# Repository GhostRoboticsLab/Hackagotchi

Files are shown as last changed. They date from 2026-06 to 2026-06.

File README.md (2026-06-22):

# Hackagotchi 🛠️🐾

<div align="center">

**The debug probe with a soul — and tools up its sleeves.**






<!-- HERO RENDER: export the Blender hero to docs/media/hero.png (recommend ~1280px wide, transparent or dark bg) and uncomment the <img> below; then drop the social card that follows it.
<img src="docs/media/hero.png" width="640" alt="Hackagotchi — XIAO RP2040: CMSIS-DAP debug probe + UART black-box recorder + reactive OLED companion" />
-->

<!-- Until the Blender hero lands, the social card doubles as the top banner. -->
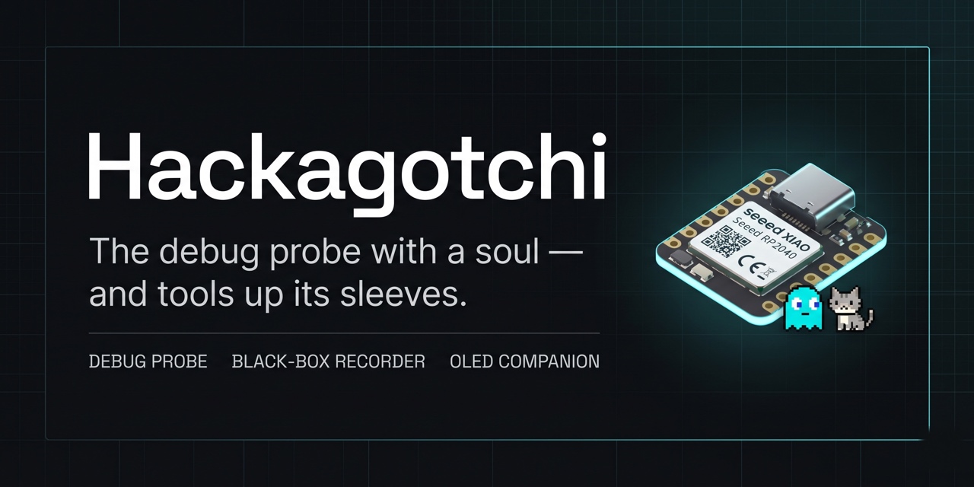
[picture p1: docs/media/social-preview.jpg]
Hackagotchi — a CMSIS-DAP debug probe, UART black-box recorder, and reactive OLED companion on one Seeed XIAO RP2040


</div>

A fork of Raspberry Pi's official [`debugprobe`](https://github.com/raspberrypi/debugprobe) firmware — drop-in with OpenOCD, probe-rs, and the Pico SDK — that doesn't just flash your target, it *watches* it. One **Seeed XIAO RP2040**, one firmware image, **three simultaneous roles**:

- 🔌 **A real SWD debug probe** — halt, erase, and reflash a wedged target with OpenOCD / probe-rs, *whatever state its firmware is in*. Standards-compliant CMSIS-DAP; enumerates as **"Hackagotchi Probe (CMSIS-DAP)"**.
- 📼 **A UART black-box recorder** — continuously logs the target's serial to microSD (session headers, heartbeats, a freeze-frame on a wedge), so a board that goes dark still leaves its **last words**.
- 🐾 **A reactive OLED that's alive, not a dongle** — a cat and a ghost whose every flicker is a *literal readout of your target*. The cat is the bench at a glance; **Spectre, the ghost, IS the target board's soul** — it wakes when the board talks, goes hollow when it wedges, dissolves when you reflash. The probe and recorder feed a face that shows the board's pulse. (This layer is evolving fast.)

> 🎯 All three on **one single-core RP2040**, with **0 DAP transfer stalls under load** — the dashboard and SD writer never steal a cycle from a flash in progress. That invariant (**R1**) is *proven on hardware, not asserted*: see [`docs/release-readiness.md`](docs/release-readiness.md).

## ⚡ Flash it in 30 seconds

No toolchain needed — just `picotool` (`brew install picotool`). Grab `hackagotchi_probe.uf2` from the **[latest release](https://github.com/GhostRoboticsLab/Hackagotchi/releases)**, drop into BOOTSEL, and load:

```bash
# BOOTSEL the XIAO: hold B, tap R, release B  ->  an RPI-RP2 drive mounts
picotool load -x hackagotchi_probe.uf2          # -x = run after loading

# alive check: send this to the control serial port (the one that answers as "Hackagotchi")
printf '{"q":"status"}\n' > /dev/cu.usbmodemXXXX  # -> {"fw":"Hackagotchi","ver":"1.0.0",...}
```

That's it — the cat wakes up and the probe is live.

<sub>Already running an older build? You don't even need the chord — send `{"q":"bootsel"}` to the control port and it drops to BOOTSEL on its own. Building from source instead? → [`docs/c-firmware-build.md`](docs/c-firmware-build.md).</sub>

<sub>**Two firmwares live here.** The shipping product is the **C firmware** in [`firmware/c/`](firmware/c) (everything below). [`firmware/micropython/`](firmware/micropython) is the original MicroPython v1 prototype, kept for reference.</sub>

---

<details>
<summary><b>🔧 Wiring &amp; pin map</b> — it's a XIAO on a Seeed expansion board; you only wire SWD + GND to your target</summary>

| Function | Pins |
|---|---|
| **SWD → target** (the probe) | SWCLK **GP26**, SWDIO **GP27**, + GND |
| **Target UART tap** → CDC0 bridge | TX **GP0**, RX **GP1** (uart0) |
| **microSD** — SPI0 (black box) | SCK **GP2**, MOSI **GP3**, MISO **GP4**, CS **GP28** |
| **OLED** — I2C1 @ 1 MHz (addr 0x3C) | SDA **GP6**, SCL **GP7** |
| **Buzzer** (PWM) | **GP29** |
| **WS2812 NeoPixel** (status LED) | data **GP12**, power **GP11** |

**No physical button** — GP27 became SWDIO, so navigation and tools are driven over USB (CDC1, below). A deliberate trade: when the device *is* a debugger, an extra debug pin beats a menu button.

</details>

<details>
<summary><b>🎛️ Using it</b> — two USB serial ports: a transparent UART bridge + a JSON control channel</summary>

| Port | Role |
|---|---|
| **CDC0** | Transparent **UART bridge** — your target's serial console, passed straight through (115200 default; runtime-changeable). |
| **CDC1** | **JSON control channel** — newline-delimited `{"q":"..."}` requests, JSON replies. |

The numeric `/dev/cu.usbmodemXXXX` suffix is **not stable** across replug — identify the control port by *behavior*: it's the one that answers `{"q":"status"}` with `"fw":"Hackagotchi"`. The other is the bridge.

**Debugging a target (SWD)** — it's a standard CMSIS-DAP probe, so point your usual tools at it:

```bash
probe-rs list                                   # -> "Hackagotchi Probe (CMSIS-DAP)"
probe-rs download --verify firmware.elf --chip RP2040
openocd -f interface/cmsis-dap.cfg -f target/rp2040.cfg
```

</details>

<details>
<summary><b>📡 Control channel (CDC1) — full command reference</b></summary>

Send `{"q":"<cmd>", ...}\n`; you get one JSON line back.

| Group | Command | Does |
|---|---|---|
| **Status** | `{"q":"status"}` | live telemetry: `fw, ver, heap, up, n, crashes, wd_armed, page, urx_drop, frag, …` |
| | `{"q":"dump"}` | status + last crash report |
| | `{"q":"lastfault"}` | the post-mortem crash box (HardFault / malloc-fail, survives reboot) |
| **Recorder / SD** | `{"q":"rec"}` / `{"q":"tail"}` | recorder state / the on-card log tail |
| | `{"q":"ls"}` / `{"q":"cat","i":N,"off":M}` | list logs / read log #N (by index — no path traversal) |
| | `{"q":"sd"}` | SD mount + bring-up status |
| **Dashboard** | `{"q":"next"}` / `{"q":"prev"}` / `{"q":"screen","n":N}` | navigate screens |
| | `{"q":"hex"}` | toggle the SNIFFER between ASCII and hex |
| **Tools** | `{"q":"macros"}` / `{"q":"macro","i":N}` | list / send a predefined string out the target UART |
| | `{"q":"setmacro","i":N,"s":"..."}` | set macro N (persisted to SD) |
| | `{"q":"baud","v":N}` | change the target-UART baud (validated set; persisted) |
| **Feedback** | `{"q":"beep"}` / `{"q":"led",...}` / `{"q":"pixel",...}` | buzzer / status LEDs / NeoPixel (pixel 0) |
| | `{"q":"fb"}` | feedback-layer readback — beep count + live NeoPixel colour (diagnostic) |
| **Companion (v1.2)** | `{"q":"fill","r":..,"g":..,"b":..}` | set the whole WS2812 chain to one colour |
| | `{"q":"mood","n":0..6,"i":0..255}` | animated mood: off / idle / rx / warn / fault / pet / rainbow |
| | `{"q":"btn"}` / `{"q":"joy"}` | button + joystick readback (held / taps; present / X / Y / dir) |
| **Companion** | `{"q":"pet"}` | a happy cat beat (heart + chirp) |
| | `{"q":"summon"}` / `{"q":"banish"}` | force the ghost present / absent (also lets tests drive it) |
| | `{"q":"exorcise"}` | the exorcism dissolve — a host flasher fires it after a clean reflash |
| | `{"q":"ghost","on":0/1}` / `{"q":"theme","n":0/1}` | mute the character layer (pure-instrument) / motion density |
| | `{"q":"ghost"}` (no `on`) | clear a `summon`/`banish` override — return the ghost to AUTO |
| **Maintenance** | `{"q":"bootsel"}` | reset to BOOTSEL for a hands-free reflash |
| | `{"q":"wd_arm"}` / `{"q":"wd_reset"}` | software watchdog control |

There are also test/diagnostic hooks used by the HIL suite (`uloop_on/off`, `recgen_on/off`, `crash`, `oom_test`, `wd_test`) — see [`firmware/c/src/cdc1_control.c`](firmware/c/src/cdc1_control.c).

</details>

<details open>
<summary><b>🐾 The dashboard</b> — a cat + a ghost, 6 auto-cycling monitor screens, 3 summonable tool screens</summary>

```
HOME         SNIFFER        RECORDER     THROUGHPUT    WATCHDOG       UPTIME
 /\_/\  .-.  UART RX LOG    BLACK BOX     ▁▂▄▆█▆▄▂      last freeze    + heap
( o.o )(o o) live tail      log NNN       bytes/s       frame          rev/flt
```

**Every flicker of personality is a literal readout of a real signal** — two characters, no whimsy that isn't load-bearing:

- **The cat** is your bench familiar, its mood the bench at a glance: **sleeping** (idle), **content** (target chatting), **hunting** (data really flowing — particles + tail speed scale with throughput), **alert** (target wedged or SD fault). Pet it with `{"q":"pet"}`.
- **Spectre, the ghost**, *is the target board's soul*. It **dozes** when the target is quiet and **wakes solid** when it talks over the UART tap (GP0/GP1), goes **hollow/pale** when it wedges, **torn** on a recorder fault, and is **exorcised** (dissolves) when the host reflashes. A status pip rides the top-right corner of every screen. (Ghost liveness follows the target's *serial* — an SWD-only attach with no UART traffic shows the dozing ghost.)

The six **monitor** screens auto-cycle; three **tool** screens (MACRO / BAUD / SD-EXPLORER) are summoned over CDC1 and stay put (excluded from auto-cycle). The buzzer + NeoPixel add event feedback (summon chirp, wedge alarm + red, recovery gasp + green) — all driven off the DAP hot path. Want a pure instrument cluster? `{"q":"ghost","on":0}`.

This character layer is under heavy active development and expanding fast — the cat and Spectre are just the first faces of the bench.

</details>

<details>
<summary><b>🧠 How it works — the R1 invariant</b> (single-core coexistence bought with priority, not a 2nd core)</summary>

The RP2040 in `debugprobe-v2.2.3` is **single-core** (no SMP), so coexistence is bought with **task priority**:

```
priority  high ─────────────────────────────────────────────► low
          UART bridge / watchdog  >  USB (TUD)  >  DAP  >  dashboard + SD writer
```

The DAP path is never blocked by anything below it, and nothing above it takes a DAP-needed lock. Cross-task data moves through **single-writer published snapshots** (a seqlock) and **lock-free SPSC rings** — never shared mutable structs. Each resource has exactly one owning task (FatFs ↔ SD task, OLED/I2C1 ↔ dashboard task, uart0 TX ↔ bridge task). The firmware runs from **flash XIP** (not `copy_to_ram`), buying +139 KB of SRAM at identical DAP throughput.

The measured payoff: **0 DAP transfer stalls** in every soak — while the SD writer hammers the card and the dashboard renders. Rationale: [`docs/engineering-plan.md`](docs/engineering-plan.md) · evidence: [`docs/release-readiness.md`](docs/release-readiness.md).

</details>

<details>
<summary><b>📁 Repository layout</b></summary>

```
firmware/c/          the shipping C firmware (this README)
  src/               our overlay: probe + bridge + control + recorder + dashboard + reliability
  boards/            the locked XIAO pin map (board config shim over upstream)
  tests/             gates/ (Gate 0/1/2) + m1..m4 (HIL + host unit tests)
  build_fork.sh setup.sh analyze.sh   build / fetch-upstream / static-analysis gate
firmware/micropython/  legacy v1 prototype (MicroPython)
docs/                engineering-plan · release-readiness · c-firmware-build · recovery-model · firmware-conventions
.github/workflows/   firmware-c.yml — manual-dispatch build + static-analysis gate + Release
case/                3D-printable enclosure
```

</details>

<details>
<summary><b>🛡️ Reliability &amp; evidence</b> — this project is gates-first</summary>

The risky architectural claims — *does the dashboard starve the probe? does the SD writer corrupt a flash? does the 2nd CDC keep DAP enumerating?* — were proven on real hardware as falsifiable **gates** *before* any feature work. See [`docs/release-readiness.md`](docs/release-readiness.md) for the full CI-automated-vs-HIL-attested evidence table, and `firmware/c/tests/gates/GATE_RESULTS.md`.

> ⚠️ A green CI badge means "builds + passes static analysis," **not** "the gates ran" — the HIL gates need the physical bench and are attested by hand on each release image.

</details>

<details>
<summary><b>📜 License &amp; open-core model</b></summary>

- **Project: GPL-3.0-or-later** ([`LICENSE`](LICENSE)) — © 2026 GhostRoboticsLab and the Hackagotchi authors. Same copyleft lineage as Pwnagotchi / Flipper Zero / Meshtastic: use, study, modify, redistribute; derivatives stay GPL.
- **`firmware/c/` subtree: MIT** ([`firmware/c/LICENSE`](firmware/c/LICENSE)) — kept MIT so fixes stay rebasable onto upstream `debugprobe`.
- Third-party components are all permissive (MIT / BSD-3 / Apache-2.0), attributed in [`THIRD-PARTY-NOTICES.md`](THIRD-PARTY-NOTICES.md) (+ [`firmware/c/THIRD-PARTY-NOTICES.md`](firmware/c/THIRD-PARTY-NOTICES.md)).

**Open-core:** the firmware is free and forkable; the project is sustained by selling assembled, pre-flashed units and the enclosure — not by closing the code.

</details>

<details>
<summary><b>🙏 Acknowledgements</b></summary>

Built on the shoulders of [`raspberrypi/debugprobe`](https://github.com/raspberrypi/debugprobe), the [Raspberry Pi Pico SDK](https://github.com/raspberrypi/pico-sdk), [TinyUSB](https://github.com/hathach/tinyusb), [FreeRTOS](https://www.freertos.org/), [carlk3's no-OS-FatFS](https://github.com/carlk3/no-OS-FatFS-SD-SDIO-SPI-RPi-Pico), ChaN's [FatFs](http://elm-chan.org/fsw/ff/), [daschr/pico-ssd1306](https://github.com/daschr/pico-ssd1306), and [zserge/jsmn](https://github.com/zserge/jsmn). 🐾

</details>

---

**Contributing?** Start with **[`CONTRIBUTING.md`](CONTRIBUTING.md)** — the fork-overlay model (don't edit upstream), the R1 concurrency rules, the gates-first discipline, and the build/test loop. 🐾

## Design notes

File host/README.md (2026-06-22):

# Host tooling

Host-side companions for a running Hackagotchi probe. Pure Python (stdlib + `pyserial`, plus
optional `Pillow`); **nothing here touches the firmware or risks the device** — these just drive
the two USB-CDC serial ports the board exposes.

| file | what it is |
|---|---|
| `hackagotchi_ctl.py` | the CLI driver for the CDC1 JSON control channel — so you don't hand-echo `{"q":"…"}` at a port |
| `tests/ctl_selftest.py` | a no-hardware self-test of the CLI's parsing/dispatch (mock serial); falsifiable green check |

## Setup

```bash
./setup-venv.sh                 # from the repo root: creates .venv + installs requirements.txt
.venv/bin/python host/hackagotchi_ctl.py status
```

`setup-venv.sh` builds one venv at the repo root and symlinks `firmware/c/.venv` to it, so the
HIL-test convention (`.venv/bin/python tests/…` run from `firmware/c/`) resolves to the same
interpreter. Manual equivalent: `python3 -m venv .venv && .venv/bin/pip install -r requirements.txt`.

## The two ports (identify by behavior, not device path)

The composite device exposes two `/dev/cu.usbmodem*` (or `/dev/ttyACM*`) ports; the numeric suffix
is **not stable across replug**. The CLI auto-detects by probing every port with `{"q":"status"}`
and matching the `"fw":"Hackagotchi"` reply — so you normally don't pass `--port` at all.

- **CDC0** — transparent target-UART bridge (the target's console; default 115200). Silent to a status probe.
- **CDC1** — newline-delimited JSON control channel (`{"q":"…"}` → one JSON line back). The one the CLI drives.

## CLI commands

```
.venv/bin/python host/hackagotchi_ctl.py <command> [args]   [--port /dev/cu.usbmodemXXXX]
```

| command | what it does |
|---|---|
| `status` | live telemetry snapshot (screen, baud, tx/rx, throughput, recorder, wedge) |
| `dump` | crash box + status in one shot |
| `lastfault` | the post-mortem crash box (HardFault / malloc-fail; survives a reboot) |
| `freeze` | the recorder's freeze-frame — the target's last words before it went silent |
| `bootsel` | reset to BOOTSEL for a hands-free reflash (the port drops; then `picotool load -x …`) |
| `baud [RATE]` | read the target-UART baud + valid options; with `RATE`, set it (validated, persisted) |
| `macro [N]` | list the configured macros; with `N`, send macro N out the target UART |
| `ls` | list the SD card's log files (shows the number to pass to `cat`) |
| `cat N [--off M] [--all]` | read SD log #N (`cat 7` → `log_007.txt`); `--all` pages to EOF |
| `sd` / `rec` / `tail` | SD mount status / recorder state / on-card log tail |
| `screen N` | jump the dashboard to screen N |
| `clear` | reset tx/rx/throughput/hits + freeze-frame |
| `watch [--seconds S]` | live-tail the relayed telemetry (Ctrl-C to stop) |
| `shot [--out f.png] [--scale K]` | screenshot the OLED over the tap → PNG (PGM fallback without Pillow) |

`ls`/`cat`/`tail` are **async by design**: the firmware services FatFs on a low-priority task off
the DAP hot path (R1), so the CLI issues each of these twice — trigger, then collect the fresh
result. The full command grammar lives in the firmware (`src/cdc1_control.c`) and the README
command table.

## Self-test (no hardware)

```bash
python3 host/tests/ctl_selftest.py                          # all checks PASS (exit 0)
HG_CTL_SELFTEST_BREAK=1 python3 host/tests/ctl_selftest.py  # verify-the-verifier: MUST FAIL (exit 1)
```

It feeds canned device replies through the CLI's parsers with a mock serial. The break mode flips
one expectation to prove the harness can actually go red — a test that cannot fail is a silent pass.

## HIL tests

The hardware-in-the-loop suites under `firmware/c/tests/**` use the same venv but need the physical
bench (a probe + a separate RP2040 target + microSD). See the project README and
`docs/release-readiness.md`.

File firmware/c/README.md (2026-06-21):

# Hackagotchi — C probe firmware

A fork of the Raspberry Pi [debugprobe](https://github.com/raspberrypi/debugprobe) that turns a
XIAO RP2040 into a **real SWD debug probe** (drive it with OpenOCD / probe-rs to halt, erase, and
reflash a wedged target regardless of its firmware state) **while also** running a UART black-box
recorder to SD, a reactive OLED dashboard, and a JSON control channel — all on the Pico SDK +
TinyUSB + FreeRTOS (**single-core**), staying R1-clean (0 DAP transfer stalls) throughout.

> This is the released product (**M1–M5 complete**; the 3 hardware gates passed). For the product
> overview and flashing a release build, see the [repo-root README](../../README.md). Full
> build/flash/analyze guide: [`../../docs/c-firmware-build.md`](../../docs/c-firmware-build.md).
> Engineering history + evidence: [`../../docs/engineering-plan.md`](../../docs/engineering-plan.md),
> [`../../docs/release-readiness.md`](../../docs/release-readiness.md), and the gate/milestone
> results under [`tests/`](tests).

## Build & flash (from source)

```bash
./setup.sh                        # fetch pinned upstream (debugprobe v2.2.3, carlk3 FatFs, pico-sdk 2.2.0)
VERSION=1.0.0 ./build_fork.sh     # -> build/hackagotchi_probe.uf2 (+ .elf); VERSION is reported by {"q":"status"}
./analyze.sh                      # GCC -fanalyzer + cppcheck static-analysis gate
```

Flash: BOOTSEL the XIAO (hold **B**, tap **R**, release **B** → `RPI-RP2` mounts), then
`picotool load -x build/hackagotchi_probe.uf2`. With the firmware already running, `{"q":"bootsel"}`
over CDC1 drops it to BOOTSEL with no button (remote reflash).

## Layout

- `src/` — our overlay: `main.c` (probe + FreeRTOS tasks), `cdc1_control.c` (JSON control),
  `cdc_uart.c` + `uart_bridge.c` (CDC0 bridge), `sd_gate.c` + `recorder.c` (SD black box),
  `hackagotchi_dashboard.c` (OLED), `crash_box.c` / `watchdog_task.c` (reliability), `feedback.c`
  (buzzer/NeoPixel), `hg_config.c` (settings), vendored `ssd1306/`, `jsmn.h`, `ws2812.pio`.
- `boards/board_hackagotchi_config.h` — the **locked** pin map (below).
- `upstream/` (gitignored) — pristine debugprobe + carlk3 FatFs, fetched by `setup.sh`.
- `tests/` — `gates/` (Gate 0/1/2 + `GATE_RESULTS.md`), `m1/`…`m4/` (HIL + host unit tests).

## Pin map (locked; verified with `picotool info`)

| Function | Pins |
|---|---|
| SWD (probe → target) | SWCLK **GP26**, SWDIO **GP27** |
| Target UART bridge (CDC0) | TX **GP0**, RX **GP1** |
| SD card — SPI0 (black box) | SCK **GP2**, MOSI **GP3**, MISO **GP4**, CS **GP28** |
| OLED — I2C1 @ 1 MHz (addr 0x3C) | SDA **GP6**, SCL **GP7** |
| Buzzer (PWM) | **GP29** |
| WS2812 NeoPixel | data **GP12**, power **GP11** |

There is **no physical button** (GP27 became SWDIO) — navigation + tools are driven over the CDC1
JSON channel. Two USB-CDC nodes enumerate: **CDC0** = UART bridge, **CDC1** = JSON control.

## Fork model

Pinned to upstream **`debugprobe-v2.2.3`** (single-core FreeRTOS — before the #189 SMP flash
regression). `setup.sh` fetches the pristine upstream into `upstream/` (gitignored); our build is an
**overlay** (we compile our `main.c` instead of upstream's and add our tasks) without modifying
upstream, so fixes stay rebasable. See [`../../docs/upstream-strategy.md`](../../docs/upstream-strategy.md).

## License

`firmware/c/` is **MIT** ([`LICENSE`](LICENSE)) to stay upstream-compatible; the rest of the repo is
GPL-3.0-or-later. Third-party components (all permissive MIT/BSD-3/Apache) are attributed in
[`THIRD-PARTY-NOTICES.md`](THIRD-PARTY-NOTICES.md).

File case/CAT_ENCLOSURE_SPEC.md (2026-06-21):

# Cat-as-object enclosure — spec & CAD-agent prompt

> Design spec, 2026-06-20. Evolves the existing "Field Recorder" pebble
> ([`HACKAGOTCHI_CASE.md`](HACKAGOTCHI_CASE.md) / `hackagotchi_case.scad`) into **Hackagotchi** — a
> desk-cat enclosure whose **face is the OLED**. The single ignition lever: a still
> photo of the powered-off object must read unmistakably as a cat.

## Design thesis

Fuse mascot + object. The on-screen `draw_cat` sprite (a 28×20 head with pointed ears, nose,
whiskers, wagging tail) should rhyme with the physical form. **#1 acceptance criterion:** one still
photo of the powered-OFF printed unit reads as a cat. The team's in-house 3D printing makes this the
highest-leverage, lowest-cost viral asset.

## Hardware to enclose

Seeed XIAO RP2040 stacked on the Seeed XIAO Expansion Board — **every dimension stays a parametric
`[MEASURE]` placeholder**, matching the current file's discipline:

- 0.96″ 128×64 SSD1306 OLED · microSD slot (edge access) · PCF8563 RTC + CR1220 coin cell ·
  passive buzzer · user button · USB-C (on the XIAO) · UART-tap leads GP0/GP1/GND exiting as a
  bundle · optional future LiPo volume.

## Cat-feature → physical mapping

| Cat feature | Physical realization |
|---|---|
| **Face** | the flush OLED visor — the screen shows the cat mascot, so the object frames the screen *as* the face |
| **Ears** | two pointed 3D ears at the OLED end, flanking the canted top corners (echo the sprite's ear angle) |
| **Nose / mouth** | the buzzer grille, recentred directly below the screen as a muzzle motif |
| **Whiskers** | shallow debossed lines on the front face flanking the screen |
| **Cheek / paw** | the recessed user button as a tap-target "cheek" |
| **Tail / rump** | the probe-snout cable boot at the XIAO end where USB-C + tap leads exit — sculpt a curled-tail relief |
| **Collar loop** | the lanyard eyelet, relocated between/behind the ears |

## Carry over from v1

Canted top (tilts screen to a desk viewer) · snap-fit seam + **no visible screws** · corner-post
board cradle · flush visor. **Print:** FDM, 0.4 mm nozzle / 0.2 mm layers, PETG or PLA; base
flat-down, top visor-window-down → no supports; ears self-support **or** are separate snap/glue
parts; ship a `coupon` (one ear + seam + cable opening) to print first.

## The CAD-agent prompt

Hand the block below to a CAD agent (OpenSCAD-fluent) to refactor `case/hackagotchi_case.scad`:

```
ROLE: You are a parametric CAD engineer fluent in OpenSCAD and FDM design-for-manufacture.

GOAL: Refactor the existing enclosure `case/hackagotchi_case.scad` from a plain "Field Recorder"
pebble into "Hackagotchi" — a desk-cat enclosure whose FACE is the OLED screen. THE #1 ACCEPTANCE
CRITERION: a single still photo of the powered-OFF printed object must read unmistakably as a cat.
This is a marketing-critical hero object, not just a box.

START FROM: the current `case/hackagotchi_case.scad` and `case/HACKAGOTCHI_CASE.md`. Preserve its
parametric structure, its `[MEASURE]`-placeholder discipline (DO NOT invent precise hardware
dimensions — keep every unknown as a clearly-commented variable with a provisional default), its
snap-fit seam, corner-post board cradle, canted top, and no-visible-screws constraint.

HARDWARE TO HOUSE (Seeed XIAO RP2040 stacked on the Seeed XIAO Expansion Board; all dims = [MEASURE]):
- 0.96" 128x64 SSD1306 OLED (the "face")     - microSD slot, edge-accessible
- PCF8563 RTC + CR1220 coin-cell holder       - passive buzzer        - user button
- USB-C port on the XIAO                       - UART-tap leads GP0/GP1/GND exit as a bundle
- leave an optional parametric volume for a future LiPo (default off)

CAT FORM (map features onto function — the printed silhouette must persist when unpowered):
- FACE  = flush OLED visor with a thin frame reveal (the on-screen mascot aligns to it)
- EARS  = two pointed 3D ears at the OLED end flanking the canted top corners
- NOSE/MOUTH = the buzzer grille, recentred directly below the screen as a muzzle
- WHISKERS   = shallow debossed lines on the front face beside the screen
- CHEEK = the recessed user button                - TAIL/RUMP = the probe-snout cable boot at
  the XIAO end (USB-C + tap leads exit here); add a curled-tail relief
- COLLAR LOOP = lanyard eyelet relocated between/behind the ears

HARD CONSTRAINTS:
- FDM, 0.4 mm nozzle, 0.2 mm layers, PETG/PLA. Base prints flat-down, top prints visor-down →
  NO support material. Ears must EITHER self-support at their radii OR be separate snap/glue parts
  (your call — justify it in a comment). Keep wall thickness, snap-fit lip clearance (`lip_clr`),
  and all tolerances as named parameters.
- Everything parametric. Anything you cannot know (board outline, component positions, OLED active
  area, USB-C cutout, tap-lead slot) stays a `[MEASURE]` variable with a sane default + a comment.

DELIVERABLES:
1. Refactored `case/hackagotchi_case.scad` with a `part=` switch: "base" | "top" | "ears"
   (if separate) | "coupon" | "all" (preview only).
2. Every part renders MANIFOLD / NoError via the OpenSCAD CLI. Provide the exact render commands.
3. A "[MEASURE] checklist": list every variable a human must set with calipers before a full print,
   grouped by part, each with units and what to measure against.
4. A 3-line print plan (orientation per part, which to print first, support=none confirmation).

STYLE: minimal but unmistakably feline; soft radii; the cat should look intentional and cute, not
a literal toy cat — think "instrument with a face." Comment your geometry. Do not add electronics,
firmware, or BOM commentary — enclosure only. If a requirement is physically impossible to print
without supports, say so and propose the nearest printable alternative rather than silently changing intent.
```

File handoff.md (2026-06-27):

# Handoff — apply the Hackagotchi product-analysis playbook to **Kestrel** (GhostLabs)

> **Purpose.** This document hands a receiving agent the *exact methodology* used to analyze
> **Hackagotchi** (a GhostLabs hardware/firmware product) so it can reproduce the full analysis for
> **Kestrel**, another GhostLabs project. The Hackagotchi *findings* were product-specific; the
> *method* below is reusable. Worked examples to imitate live in the Hackagotchi repo:
> `docs/go-to-market.md`, `docs/monetization.md`, `case/CAT_ENCLOSURE_SPEC.md`, and the GPL-3.0
> relicense (`LICENSE` + `THIRD-PARTY-NOTICES.md`).
>
> **How to use:** read §1 (principles), do §2 (understand Kestrel + adapt), run §3 (the phases),
> ship §4 (deliverables). §5 has copy-paste lens templates. §6 has the hard-won defaults.

---

## 0. Operating mode

- **Best executed with multi-agent orchestration.** Each phase is a *fan-out of independent lenses*
  (run in parallel) → an *adversarial critic* that stress-tests all lenses together → a *synthesis*
  you write. If you have a Workflow/subagent tool, use it (parallel lenses + a high-effort critic).
  If you're a single agent, run each lens as its own sequential research pass, then the critic.
- **Ground everything in web research + the real repo.** Real comparables, real 2026 prices/fees,
  real numbers. Never vibes, never made-up figures.
- **You produce the synthesis.** Subagents return structured findings; *you* write the final docs and
  make the decisive calls. Don't just relay lens output.

---

## 1. Operating principles (non-negotiable — these are what made the analysis good)

1. **Adversarial verification at every phase.** End each phase with a ruthless critic prompted to
   *refute*: name the weakest/most wishful claims, what won't work, the single biggest risk, the
   honest odds, and a **cut list**. Trust the critic's corrected numbers over first-pass optimism.
2. **Honest ceilings.** Model the *realistic* outcome, not the fantasy. State the hard ceiling out
   loud (for Hackagotchi: "a beloved niche tool, not a viral phenomenon"). Treat breakout as a
   labeled lottery ticket that **never** enters a plan or anchors any spend.
3. **Lead with the core insight ("the wedge"), not the feature list.** Find the one-sentence,
   universally-felt pain the product resolves. That sentence *is* the positioning.
4. **Be decisive.** Pick winners and give numbers; don't survey options. Every recommendation states
   the action, the why, a confidence level, and (for money) the arithmetic.
5. **Separate "can" from "should."** Especially for licensing/closed-source: answer the legal
   question *and* the strategic question separately.
6. **Right altitude for the audience.** For a hobbyist/consumer/maker audience, the emotional hook /
   personality / mascot is the *primary* lever — lean in. For an enterprise/pro audience, firewall it
   and lead with credibility. Decide which Kestrel is *first*.
7. **Cross-link and date everything.** Each deliverable is a dated analysis snapshot, cross-linked to
   the others.

---

## 2. Phase 0 — Understand Kestrel, then ADAPT the plan (do this first)

Before any strategy work, build the shared brief every lens will reuse.

**Read the Kestrel repo end-to-end:** README, `docs/`, any roadmap/engineering notes, the code
structure, the license state, and every dependency's license. Determine:

- **What it is** and **who it's for** (the audience — and therefore the altitude per principle 6).
- **The core "wedge"/insight** — the one-sentence pain it kills.
- **Stage** — finished? still in development? (gates "launch now vs keep building").
- **Assets** — does it have a mascot/brand? hardware? 3D-printing capability? a community? a name with
  lineage/borrowed reach?
- **Licensing reality** — current license (or none = "all rights reserved"), and whether deps are
  permissive (MIT/BSD/Apache) or copyleft (GPL) / non-commercial (which constrains closing it).

**Then classify the project TYPE and adapt which phases apply:**

| Kestrel is… | Run | Adapt / skip |
|---|---|---|
| **Hardware / firmware product** | All of §3 incl. manufacturing + enclosure spec | — (the Hackagotchi case, verbatim shape) |
| **Pure software / app / SaaS** | §3 A, B, C, licensing | Replace "manufacturing/DFM" with *delivery/infra cost + COGS-per-user*; pricing vs software comparables; **skip** the enclosure spec (optionally produce a landing-page/brand spec instead) |
| **Dev tool / library / OSS** | §3 A, B (adoption-flavored), C, licensing | Monetization → OSS sustainability (sponsors, support, hosted/pro tier); virality → adoption/forkability; skip enclosure/manufacturing |
| **Service / content / other** | §3 A, C, licensing | Tailor B and the asset spec to the medium |

**Output of Phase 0:** a tight one-page **`{{KESTREL_BRIEF}}`** (product, wedge, audience, stage,
assets, license reality, the goal). Every lens prompt below interpolates it. This mirrors the
`BRIEF` constant used in the Hackagotchi workflows.

---

## 3. The analysis phases

Each phase = fan-out lenses → adversarial critic → your synthesis into one dated doc.

### Phase A — Go-to-market / marketing strategy → `docs/go-to-market.md`
**Lenses:** (1) audience & channels — *who*, ranked, with the beachhead, and the exact 2026
communities/channels to reach them; (2) positioning & messaging — the 5-second one-liner, taglines,
the narrative (pain → villain → hero), naming check; (3) launch playbook — sequenced, the single best
lead surface, the one make-or-break asset; (4) competitive landscape — real alternatives + prices,
the defensible differentiation, where *not* to fight; (5) business model — monetization shape +
channels; (6) content & assets — the highest-leverage pieces, ranked by impact-per-effort.
**Critic:** the real wedge, weakest claims, what won't work for a small/solo team, biggest risk, the
**cut list**, and an honest "product vs portfolio/credibility play" verdict.

### Phase B — Virality / adoption strategy → fold into `docs/go-to-market.md`
**Lenses:** (1) **viral case studies** — find the *real* analogues that went viral in Kestrel's space
and extract the repeatable mechanics (for Hackagotchi: Pwnagotchi, Flipper, the deauther,
Meshtastic); (2) the **hook** — the emotional/mascot/personality lever or the "money moment" that is
inherently shareable; (3) **channel ignition mechanics** — what actually triggers a front page /
algorithm / share cascade, and the firing *order* (e.g. Reddit warm-up → Hackaday amplifier → hold
Show HN); (4) the **distribution funnel** — hardware: 3D-print + build-it-yourself; software:
free-tier/templates/integrations/forkability; (5) **licensing-for-virality** — open vs closed, and
its effect on the community flywheel; (6) **timing & readiness** — launch-now vs keep-building, the
readiness minimum, a realistic definition of "viral" for this niche (tiered, with odds).
**Critic:** the single **ignition move**, the **honest odds**, what *kills* virality, and the decisive
open/closed call.

### Phase C — Monetization, pricing & manufacturing/delivery → `docs/monetization.md`
**Lenses:** (1) revenue model + **the actual math** — every stream ranked by contribution, the funnel
math (visitors → conversion → paid), unit economics, and **low/base/high 12-month scenarios** with
explicit assumptions; (2) **pricing market analysis** — competitor price map, willingness-to-pay
floor/ceiling, the recommended price ladder (good/better/best) with rationale; (3) **manufacturing /
DFM** (hardware) — enclosure (FDM → POD → injection-mold break-evens), electronics (COTS vs custom
PCB MOQ curves), certification, assembly — *or* **delivery/infra cost** (software); (4) **channel
economics** — fees, fulfillment burden, tax/VAT handling, and crowdfunding-to-de-risk-the-first-run.
**Critic (CFO-style, high effort):** the weakest numbers (haircut them), a frank **realistic P&L**
(is this a business, side-income, or break-even hobby?), the **biggest financial risk**, a
sell-or-not verdict, the **recommended sequenced path**, and a **cut list**. *The critic's corrected
numbers are the ones you publish.*

### Cross-cutting 1 — Licensing decision (+ optionally execute it)
Answer both questions: **CAN** it be closed (audit every dependency's license — flag any
copyleft/non-commercial traps) and **SHOULD** it (strategy: for clonable/community products the moat
is brand + docs + convenience + trademark, not the bytes → usually **open-core**). Recommend a
specific license + the open-core structure. If asked to execute: add `LICENSE` + per-file SPDX
headers + a root `THIRD-PARTY-NOTICES.md`, kill any stale license references, **on a branch → PR**.
(Hackagotchi precedent: GPL-3.0 for the project, MIT kept on a subtree that's a fork of an MIT
upstream to preserve upstream-ability. Confirm the copyright holder against the **GitHub org name**,
not a guess.)

### Cross-cutting 2 — Tangible-asset spec (if applicable)
Hardware → an enclosure/industrial-design spec + a ready-to-use **CAD-agent prompt** (see
`case/CAT_ENCLOSURE_SPEC.md` for the shape: design thesis, hardware-to-house with `[MEASURE]`
parametric placeholders, feature→form mapping table, print constraints, deliverables, and the
self-contained prompt). Software → a landing-page / brand / onboarding spec.

---

## 4. Deliverables

Produce, each on its **own branch → PR** (keep PRs focused; docs-only PRs separate from any code/
license change):

- `docs/go-to-market.md` — GTM + virality (audience, positioning, the ignition move, channel
  sequence, the **honest ceiling** table, what-kills-it, the readiness gate, a **cut list**).
- `docs/monetization.md` (or `docs/business-model.md` for software) — the **corrected** money math,
  pricing ladder, unit economics, scenario table, the cardinal financial rules, manufacturing/
  delivery roadmap, channel sequence, the pre-revenue gate.
- (hardware) `<dir>/<ASSET>_SPEC.md` — asset spec + CAD-agent prompt.
- Licensing: `LICENSE` + `THIRD-PARTY-NOTICES.md` (if executing) on a relicense branch → PR.

**Delivery (pre-authorized by Davis — don't ask for this part).** When a phase's report/deliverable
is finished, ship it end-to-end: **commit → push → open PR → sync with `main`** (merge the PR, then
update local `main`). This delivery flow is standing-authorized. You still **pause between phases**
for steering, and still **ask before** anything destructive/out-of-scope (force-push, history
rewrite, deleting work) and before any **license change** not already cleared with Davis.

**Every doc:** dated header + one-line provenance, evidence-grounded, the critic's corrected figures,
cross-linked, and an explicit "honest ceiling" + "cut list".

---

## 5. Reusable templates (copy-paste; substitute `{{KESTREL_BRIEF}}`)

**Lens output schema (structured):**
```
{ lens: string,
  keyFindings: string[],                 // 4–7 decisive, evidence-backed
  numbers?: string[],                    // concrete figures w/ sources (money phases)
  recommendations: [{ action, why|rationale, priority|viralLeverage|confidence, effort? }],
  evidence?: string[] }                  // named cases, URLs, prices, mechanics
```

**Critic output schema:**
```
{ weakestClaims: string[], whatWontWork|whatKills: string[], biggestRisk: string,
  theRealWedge|theIgnitionMove: string, honestOdds|realisticPnL: string,
  decisiveCall: string,                  // e.g. open/closed, sell-or-not, product-vs-portfolio
  cutList: string[] }
```

**Generic lens prompt:**
```
You are a {{ROLE}} for {{PROJECT TYPE}}. {{TASK FOR THIS LENS}}.
{{KESTREL_BRIEF}}
Use WebSearch to ground this in current (2026) reality. Be specific with NAMES, NUMBERS, and real
comparables — not categories. Deliver {{the bullet list of what this lens must produce}}. Be
opinionated and pick winners; show arithmetic where relevant.
```

**Adversarial critic prompt:**
```
You are a ruthless {{growth / CFO}} advisor doing a REALITY CHECK on the strategy assembled for
{{PROJECT}}. Be adversarial and decisive — stop a small team from wasting months/money.
{{KESTREL_BRIEF}}
Assembled findings from the lenses (JSON): {{LENSES_JSON}}
Identify: the weakest/most wishful claims; what won't work for a small team with no budget/audience;
the single biggest risk; THE one move that matters most (be concrete); the honest odds / realistic
P&L (don't flatter); the decisive call ({{open vs closed / sell-or-not / etc.}}); and the cut list of
what to NOT do.
```

**Phase lens menus** (interpolate the brief into each): use the lens lists in §3 A/B/C verbatim as the
set of parallel lenses per phase.

---

## 6. Hard-won defaults from Hackagotchi (apply, but re-verify for Kestrel)

- **Open-core beats closed** for clonable / community / maker products. Closing the source on a
  commodity base protects almost nothing and kills the fork/plugin/community flywheel. Monetize the
  brand, docs, convenience, trademark, and a premium tier — never the bytes. *(Verify Kestrel's
  audience expects openness before assuming this.)*
- **Plan for the niche base case, not the lottery.** Breakout is a 10–20%-at-best upside that must
  never appear in a P&L.
- **Price for after-labor margin.** For small-batch hardware, *labor — not BOM —* is the margin
  killer; price above the "nets ~$0 after your time" floor. For software, watch infra COGS + support
  load per user.
- **Never spend tooling/inventory ahead of validated demand** — crowdfund the first real run.
- **Never ship without the safety/quality basics** (hardware: input protection; software: the
  equivalent first-run/data-loss guards) — RMAs/churn erase all margin and the brand.
- **The mascot/personality can be the #1 viral lever for a hobbyist audience** — but firewall it from
  capability claims for a pro/enterprise audience.
- **Lineage/borrowed reach is free** — if the name or category rides an existing beloved thing, state
  it explicitly.

---

### Quick-start for the receiving agent
1. Read this whole file. 2. Do **Phase 0** → write `{{KESTREL_BRIEF}}` and classify the project type.
3. Run **Phase A**, then **B**, then **C** (fan-out lenses → critic → synthesize), pausing after each
   to let the human steer. 4. Do the **licensing** decision; execute it on a branch + PR if asked.
5. Produce the **asset spec** if applicable. 6. For each finished deliverable, **commit → push → open
   PR → sync with `main`** (pre-authorized — don't ask).
Pause between phases for steering and surface conflicts; ask before anything destructive/out-of-scope
or any **license change** not yet cleared with Davis.

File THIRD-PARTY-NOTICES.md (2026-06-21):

# Third-party notices

Copyright © 2026 GhostRoboticsLab and the Hackagotchi authors.

Hackagotchi's own source code is licensed **GPL-3.0-or-later** (see [`LICENSE`](LICENSE)),
**except** the `firmware/c/` subtree, which is **MIT** (see
[`firmware/c/LICENSE`](firmware/c/LICENSE) and the note below). Bundled and build-time
third-party components remain under their own licenses, reproduced or referenced here.

## firmware/micropython — v1 (project code: GPL-3.0-or-later)

Vendored MicroPython drivers, redistributed under their original **MIT** license:

| Component | Path | License | Upstream |
|---|---|---|---|
| `ssd1306.py` | `firmware/micropython/lib/ssd1306.py` | MIT | MicroPython project (`micropython/micropython`) |

MIT is one-way compatible with GPL-3.0, so the combined v1 firmware (GPL-3.0 application
code + MIT drivers) is distributable as a whole under **GPL-3.0-or-later**.

## firmware/c — v2 (subtree license: MIT)

The v2 debug-probe firmware is a fork of Raspberry Pi's **`debugprobe`** (MIT) and is kept
under **MIT** so fixes remain upstream-compatible (see `docs/upstream-strategy.md`). Its full
per-component attribution lives in
[`firmware/c/THIRD-PARTY-NOTICES.md`](firmware/c/THIRD-PARTY-NOTICES.md) and covers, in brief:

| Component | License |
|---|---|
| `raspberrypi/debugprobe` | MIT |
| ARM CMSIS-DAP | Apache-2.0 |
| FreeRTOS-Kernel | MIT |
| Raspberry Pi Pico SDK | BSD-3-Clause |
| TinyUSB | MIT |
| `daschr/pico-ssd1306` | MIT |
| `zserge/jsmn` | MIT |

All permissive, no copyleft. Per release, ship this notice and keep any GPL (sigrok) or
non-commercial (SEGGER SystemView) components **out** of the shipping image, per
`docs/engineering-plan.md`.

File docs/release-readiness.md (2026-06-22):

# Release readiness — `v1.1`

The single evidence index for the C probe firmware release. It draws the line between what **CI can
automate** and what is **operator-attested on real hardware**, and pins each green to the *tagged
image* (not a per-increment dev build).

> ⚠️ **The HIL gates cannot run in CI.** Every gate/milestone test needs a physical probe + target
> (+ for some, an SD card / SWD fixtures). CI (`.github/workflows/firmware-c.yml`, self-hosted runner)
> runs **only** the build + the `analyze.sh` static-analysis gate. A green CI badge therefore means
> "builds + passes static analysis," **not** "the gates ran." The gates below were run by hand on the
> image and recorded here.

## Release identity (v1.1)

| | |
|---|---|
| Tag | `v1.1` |
| Version (compiled in) | `1.1.0` — reported live by `{"q":"status"}` → `"ver"` (verified on the artifact: `strings` → `1.1.0`) |
| Base | fork of `raspberrypi/debugprobe` @ `debugprobe-v2.2.3` (single-core FreeRTOS) |
| Headline | OLED UI overhaul (cat + Spectre) **+ the `HG_PIN_DAP` XIP-cache-contention fix it needed** (§0 below) + DAP health telemetry |
| Build | `VERSION=1.1.0 ./build_fork.sh` (Arm GCC 13.3.Rel1 + pico-sdk 2.2.0; **`HG_PIN_DAP=ON` by default**) |
| Footprint | `.text` 110516 B (flash XIP) · `.data` 18832 B copied to **SRAM** at boot (incl. the ~18.8 KB pinned DAP/USB hot path) · `.bss` 82068 B |
| Attested artifact | `.uf2` sha256 `b0826090…d683` · `.elf` sha256 `56c5c975…5bec` |
| Gate | `analyze.sh` **PASS** (exit 0); the 7 DAP/USB transaction objects verified resident in SRAM (`nm`: `0x2000xxxx`), i.e. the pin took effect in the binary |
| Published | **tag `v1.1` @ `29fddde`** · [Release](https://github.com/GhostRoboticsLab/Hackagotchi/releases/tag/v1.1) — **immutable**, latest (`.uf2` + `.elf` + `THIRD-PARTY-NOTICES.md` + MIT `LICENSE`) · 2026-06-22. The published `.uf2` downloads back to sha256 `b0826090…d683`, byte-identical to the attested artifact and a clean reproducible rebuild from `29fddde`. |
| Tag scheme | per v1.0: GitHub immutable-releases reserve a tag name permanently, so semver `1.1.0` ships under the short tag **`v1.1`** (the `1.1.x` tag space stays open for patch re-cuts). |

## Section 0 — v1.1 delta: the XIP-cache-contention finding + `HG_PIN_DAP` fix

The v1.1 UI overhaul is a `+0` (lowest-priority), snapshot-only render layer that never touches the DAP
hot path — yet it introduced a **0-stall DAP regression** via a path priority cannot see. This section is
the proof it was found, root-caused, and fixed before shipping.

**Falsifiable claim (the regression):** *the v1.1 UI does not regress the DAP retryable-desync rate the
shipped v1.0 met.* — **FALSIFIED**, then fixed.

| Step | Evidence | Result |
|---|---|---|
| Reproduce | Gate-1 soaks of the v1.1 candidate on a clean bench | **1.4–3.0% retryable**, **0 stalls**, 0 target-glitch |
| Is it the firmware (not bench drift)? | **Interleaved A/B vs the shipped v1.0 `.uf2`** on one bench/host/cable, candidate **last-in-time**, power-cycle each | v1.0 **~0.2%**; v1.1 **1.4–3.0%** with the v1.1 run last → real **~7–15× regression**, not drift. (Tell: a power-cycle made it *worse*, not better → not dirty-bench.) |
| Root cause | ELF artifact diff + reasoning: the +0 render loop churns the 16 KB XIP I-cache and evicts the flash-resident CMSIS-DAP framing path; only the USB device ISR (`dcd_rp2040_irq`) was SRAM-resident → QSPI refill in the USB-IN window → retryable desyncs, **0-stall** (RAM ISR keeps acking). **The XIP cache is priority-blind.** | confirmed |
| Fix | `HG_PIN_DAP` → `memmap_hackagotchi_pin.ld` drops the 7 DAP/USB transaction objects from flash `.text` so they run from SRAM (residency only; no priority change; no upstream edit). `nm` on the v1.1 artifact: all 7 at `0x2000xxxx`. | in the shipped binary |
| Pure-pin soak | `gate1_soak 500` on the pinned image (run `b7dsm5jry`) | **0/500 fails, 0 stalls** — cleaner than v1.0's own ~0.2% |
| Combined image soak | `gate1_soak 1000` on the combined candidate (`ver 1.1.0-pin-dh` — identical to the released `1.1.0` but for the compiled version string), **non-idle host** (concurrent git/doc work mid-run) | authoritative line **verbatim**: `DONE N=1000 fails=2 stalls=0 target_glitch=0` → **`PROBE VERDICT: FAIL` (strict 0-fail Gate-1 bar)**. **999/1000 clean cycles**; the `fails=2` are both from **one** bad cycle (#994: a `TARGET_OK` retryable download fail + its re-verify mismatch). **0 stalls, 0 target-glitch.** |
| Liveness cross-check | a live `{"q":"status"}` read **immediately after the soak** (companion read — the soak harness logs cycle tallies, not the status reply) | `dap_xfers=1,993,328`, `crashes=0`, `urx_drop=utx_drop=0` — the monotonic `--wrap=DAP_ExecuteCommand` witness shows the probe serviced ~2.0 M transfers, so the clean cycles are real, not a dark/silent pass. |

**Verdict — honest, not flattering.** The R1 hard bar (**0 stalls**) held in every soak, and the fix's
*correctness* is established: the interleaved A/B eliminated the ~7–15× regression and the **pure-pin image
soaked `0/500` (PASS)** — that 0/500 is the clean reference. **But the combined 1000-cycle run's own strict
Gate-1 verdict was `FAIL`** — `fails=2` (0.2%), both from a single non-stall `TARGET_OK` retryable cycle on
an **admitted non-idle host** (the methodology's #1 rate inflator). 0.2% is the *same order* as v1.0's ~0.2%
floor — **not below it**. So the combined run corroborates 0-stall + witness-live but did **not** itself
clear the strict retryable bar; we ship on the strength of the A/B + the 0/500, not this run. **Carried
forward (open):** re-run the combined image `gate1_soak 1000` + `coexist_soak 300` on a strictly idle host
for a clean 0/N headline.

> Methodology now codified in `docs/firmware-conventions.md` §2, `docs/mcu-bringup-playbook.md` §10, and
> the `run-hil-gate` / `firmware-gate` skills: **0 stalls is necessary, not sufficient** — also gate the
> retryable rate against the *shipped* image, interleaved + candidate-last, with the `dap_xfers` witness.

## Section A — CI-automated (`firmware-c.yml`)

| Check | Tool | Result on v1.0 |
|---|---|---|
| Build | CMake + pinned Arm GCC 13.3 + pico-sdk 2.2.0 | **PASS** (clean) |
| Static-analysis gate | `analyze.sh` (GCC `-fanalyzer` + cppcheck) | **PASS** — 0 analyzer / 0 style on the pristine TUs (`cdc1_control.c`, `hackagotchi_dashboard.c`); only report-only upstream-inherited warnings |
| Artifacts + Release | uploads `.uf2`+`.elf`; optional Release ships **+ THIRD-PARTY-NOTICES.md + LICENSE** | wired |

Host unit tests (`ring_test`, `recorder_test`) are pure-host and **CI-able** (no hardware); they pass
locally (below) and a CI job for them is a tracked follow-up.

## Section B — HIL-attested baseline (NOT run in CI) — carried forward to v1.1

> **Carry-forward rationale.** The v1.1 delta is (a) the OLED UI overhaul, which runs entirely at the
> lowest priority off snapshot-only reads — it adds new *screens/attestation*, not new probe/bridge/SD
> paths — (b) the `HG_PIN_DAP` **residency** change (no logic/priority change), (c) the additive
> `dap_xfers`/`dap_idle_ms` status fields, and (d) the `ver` string. The portable + integration suites
> below are unaffected by those, so they carry forward as the v1.1 baseline; the v1.1-specific evidence
> (UI surfaces via `screen_hil`, and the DAP regression + fix) is in **§0** and the M-UI results.

Ports: CDC1/control `/dev/cu.usbmodem21204`, CDC0/bridge `/dev/cu.usbmodem21202`. Runner:
`…/PicoInky/.venv/bin/python`. Device flashed with the v1.0 `.uf2` (`{"q":"status"}` → `ver=1.0.0`).

| Suite | Proves | On v1.0 | Result |
|---|---|---|---|
| Version provenance | device self-reports its release | ✅ re-run | **PASS** — `fw=Hackagotchi, ver=1.0.0` |
| `m1/ring_test` (host) | SPSC ring (FIFO/wrap/drop/fence) | ✅ re-run | **PASS** 35/35 |
| `m2/recorder_test` (host) | recorder core state machine | ✅ re-run | **PASS** 31/31 |
| `m1/jsmn_hil` | JSON dispatch, strstr-trap reject, frag reassembly, nav | ✅ re-run | **PASS** (nav assertion hardened — async read) |
| `m1/uart_bridge_hil` | CDC0↔UART IRQ→ring→drain, 0 drops | ✅ re-run | **PASS** 55 B, 0 drops |
| `m1/crashbox_hil` | HardFault + malloc-fail captured, survive reboot | ✅ re-run | **PASS** |
| `m1/watchdog_hil` | SW watchdog catches a wedged TUD | ✅ re-run | **PASS** |
| `m3/screen_hil` | screen self-attestation (shows==loops) | ✅ re-run | **PASS** |
| `m3/feedback_hil` | buzzer/NeoPixel event transitions | ✅ re-run | **PASS** |
| `m4/hex_hil` | SNIFFER ASCII↔hex render | ✅ re-run | **PASS** (gutter assertion hardened — row-wrap) |
| `m4/macro_hil` | macro sender loops back | ✅ re-run | **PASS** |
| `m4/baud_hil` | runtime baud change + loopback at new rate | ✅ re-run | **PASS** |
| `m4/sd_hil` | SD explorer ls/cat | ✅ re-run | **PASS** |
| `m4/config_hil` | settings persist across reboot | ✅ re-run | **PASS** |
| **Gate 2 deferral (b)** `gate2_cdc.py --live-uart` | CDC0 live UART concurrent with a DAP flash soak | ✅ re-run | **PASS** — loopback 125/125, `urx_drop`/`utx_drop` +0, CDC1 answered 125/125, **0 stalls** ¹ |
| Gate 0 | probe halts/erases/flashes a target | cited | **PASS** 5/5 — `GATE_RESULTS.md` (prior image; needs SWD target + fixtures to re-run) |
| Gate 1 | OLED task survives sustained flash, 0 stalls; at-DAP-prio contention | cited | **PASS** — `GATE_RESULTS.md` (1000/1000 + self-attesting 300; prior image) |
| Gate 2 core | 2 nodes, DAP binds, 100/100 JSON | cited + corroborated | **PASS** — `GATE_RESULTS.md`; on v1.0 the probe enumerates as `Hackagotchi Probe (CMSIS-DAP)` and `--live-uart` exercised both CDCs + DAP live |
| M2 coexistence soak (R1) | 0 stalls under continuous SD-write + DAP flash | cited | **PROBE PASS** — `M4_RESULTS.md`: **0 stalls, flash succeeded every cycle**; the 13/300 (4.3%) are RETRYABLE host/USB hiccups, not flash-fails or probe faults (M4 image; v1.0 differs only by the `ver` string, so not re-run) |

¹ First run: the target re-glitched its QSPI (`fails=300`, still 0 stalls — the documented fragility).
**Clean re-run after a power-cycle (2026-06-21): PASS — `fails=1` (1%), 0 stalls, loopback 64/64,
urx/utx_drop +0, CDC1 answered 64/64** — the DAP flash also completed clean *concurrent with* byte-perfect
UART + USB liveness. Unambiguous close of deferral (b).

## Open operator-gated items

1. **Gate 2 deferral (a)** — node-map stability across replug/reboot. **One cycle effectively passed**:
   the 2026-06-21 power loss + operator replug was a real reboot+replug, and behavioral discovery recovered
   the roles correctly afterward (exactly 2 nodes; control `usbmodem21204` answers as `Hackagotchi`; bridge
   `usbmodem21202` silent). The full interactive 3×-replug + 1-reboot run is available via
   `gate2_cdc.py --replug-rounds 4` (it prompts the operator each round).
2. ~~Gate 2 deferral (b) clean re-run~~ — **DONE** (footnote ¹: clean PASS on the power-cycled target).
3. *(optional rigor)* re-run Gate 0/1 + `coexist_soak.py 300` on the v1.0 image (cited above from the
   functionally-identical M4 image).

## Carried caveats (unchanged from M4)

- Retryable (0-stall) DAP transfer errors rise under the *artificial* continuous-max-SD soak; ~0 in
  real use (the target is halted during a real flash). **Host-load-sensitive** — run soaks on an idle host.
- Some target boards re-glitch their QSPI under sustained flash hammering (still 0 stalls throughout) —
  power-cycle the target between long soak campaigns. Probe firmware unaffected.

## Reproduce

```bash
cd firmware/c && ./setup.sh && VERSION=1.0.0 BUILD_DIR=/tmp/hg-v100 ./build_fork.sh && ./analyze.sh
# flash /tmp/hg-v100/hackagotchi_probe.uf2 (picotool load -x, or {"q":"bootsel"} then load), then:
VENV=…/PicoInky/.venv/bin/python
$VENV tests/m1/jsmn_hil.py; $VENV tests/m1/uart_bridge_hil.py; $VENV tests/m1/crashbox_hil.py; $VENV tests/m1/watchdog_hil.py
$VENV tests/m3/screen_hil.py; $VENV tests/m3/feedback_hil.py
$VENV tests/m4/hex_hil.py; $VENV tests/m4/macro_hil.py; $VENV tests/m4/baud_hil.py; $VENV tests/m4/sd_hil.py; $VENV tests/m4/config_hil.py
$VENV tests/gates/gate2_cdc.py --live-uart --secs 150       # deferral (b)
$VENV tests/gates/gate2_cdc.py --replug-rounds 4            # deferral (a) — operator-driven
cc -I src -pthread tests/m1/ring_test.c -o /tmp/ring && /tmp/ring
cc -I src tests/m2/recorder_test.c src/recorder.c -o /tmp/rec && /tmp/rec
```

> Run HIL suites **standalone on a settled device** (not back-to-back after the reboot-inducing
> crashbox/watchdog tests, and not on a loaded host) — the UART-loopback tests share device state.
> See the `run-hil-gate` skill for the bench runbook.

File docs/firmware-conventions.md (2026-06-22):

# Hackagotchi firmware — C conventions (the reliability stack, codified)

The conventions the M1 reliability core established, written down so M2+ follow them. These are the
"raise the reliability stack" rules in concrete form. The methodology behind them (gates-first,
evidence ranks, verify-the-verifier) lives in `docs/mcu-bringup-playbook.md`; this file is the
day-to-day coding contract.

## 1. Error handling: error-code + goto-cleanup

New code that acquires **more than one** releasable resource unwinds via a single cleanup label, in
reverse order of acquisition — no nested `if` pyramids, no leaked handle on an early error:

```c
int do_thing(...) {
    int rc = -1;
    FIL *f = NULL;
    if (f_mount(&fs, "", 1) != FR_OK) goto out;          // resource 1
    if (f_open(&file, path, FA_WRITE) != FR_OK) goto unmount;  // resource 2
    if (f_write(&file, buf, n, &bw) != FR_OK || bw != n) goto close;
    rc = 0;
close:   f_close(&file);
unmount: f_unmount("");
out:     return rc;
}
```

- Return an **error code**, not a bool, when the caller can act differently per failure.
- A function that takes **one** resource uses plain early-return (the degenerate case) — that is what
  the M1 modules (`crash_box`, `watchdog_task`, `uart_bridge`, `cdc1_control`) do, since none acquire
  multiple resources. The full goto-cleanup idiom first earns its keep in **M2** (FatFs: mount → open
  → write → close).
- Never `goto` forward over a variable's initialization, and never `goto` backward (no loops).

## 2. Never block on the hot path (anything at or above DAP priority)

Priority order (single-core FreeRTOS, F1-1): UART-bridge +3 > TUD +2 > DAP +1 > dashboard +0, plus the
SW-watchdog at +3. (This intentionally keeps upstream debugprobe's UART(+3) > TUD(+2) ordering — "UART
must preempt USB or characters get lost" — rather than the engineering-plan §4.1 sketch of TinyUSB >
UART; the load-bearing invariant is only that everything stays **above DAP**.) A task at or above DAP
must not busy-wait or do slow I/O, or it delays the probe:

- **No `uart_write_blocking` / `f_write` / `ssd1306_show` / `busy_wait` on a +1..+3 task.** The CDC0
  TX path was switched from `uart_write_blocking` to push-only-what-the-FIFO-takes (M1 increment 5)
  for exactly this reason.
- Slow work (SD writes, OLED flush, buzzer) belongs on the **dashboard task (+0)**, which is designed
  to be preemptible and may be starved for seconds under load — that starvation is a *feature*, not a
  wedge (so do **not** watchdog the dashboard task; watchdog TUD instead — it is never legitimately
  starved because DAP is below it).

**The XIP cache is priority-blind (Finding, v1.1).** Priority arbitrates CPU *scheduling*, not the
shared **16 KB XIP instruction cache or the QSPI flash bus**. The image runs from flash XIP and the
entire CMSIS-DAP response-framing path (`DAP_ProcessCommand`, `SWD_Transfer`, `tud_task_ext`,
`usbd_edpt_xfer`, the vendor/CDC endpoint glue) is flash-resident — only the USB device ISR
(`dcd_rp2040_irq`) is in SRAM. A *non-blocking* +0 task that churns a large flash-instruction working
set every frame (v1.1's OLED render loop: new blit engine + sprites + ghost compositing, 8 blits/frame)
**evicts the DAP path's cache lines**; the next transaction pays a QSPI refill that lands inside the
USB-IN response window → **retryable** DAP framing desyncs (wrong command-ID / short-transfer /
IN-timeout). It stays **0-stall** (the RAM-resident ISR keeps acking the bus — added *latency*, not a
lock), so it PASSES the R1 hard bar yet **regresses the strict Gate-1 retryable rate the shipped image
met**. Preemption can't save it: when the DAP task runs, the cache is *already* polluted. Proven by
interleaved A/B on the bench (v1.1 ~1.4–3.0% retryable vs v1.0 ~0.2%, 0 stalls throughout, candidate
last-in-time → not bench drift). **Mitigation: `HG_PIN_DAP`** — a gated linker variant
(`memmap_hackagotchi_pin.ld`) drops the DAP/USB transaction objects from flash `.text` via
`EXCLUDE_FILE` so they run from SRAM, out of the contended cache (no upstream edit, **residency-only —
no priority change**, ~19 KB of the +139 KB free SRAM). The pinned image soaked **0/500**. Corollary:
when you add continuous flash-resident work, **watch the DAP *retryable* rate, not just stalls**, and
A/B it against the shipped image — and the old "the DAP hot path stays warm in XIP without
`__not_in_flash_func`" assumption holds only for a light UI; a heavy render loop crosses the threshold.

## 3. Bounded buffers, counted overflow — never silent loss

Every queue/ring/buffer has a fixed cap and a **counter** for what it had to drop, surfaced in the
CDC1 `status` telemetry (`urx_drop`, `utx_drop`, `crashes`, …). A silent drop is a silent pass. The
target-UART RX path is interrupt-driven into a bounded SPSC ring (`spsc_ring.h`) so capture never
depends on poll timing; overflow is counted, not lost-and-forgotten.

## 4. ISR / callback-context buffers go static, not stack (Finding F1-4)

A USB/IRQ callback runs on a small task stack (the TUD task is 512 words) on top of the USB stack's
own call depth. Large locals there overflow it and corrupt adjacent state — the symptom is *not* a
clean crash but, e.g., a corrupted USB endpoint (host `ENXIO`). Put parser token arrays, reply
buffers, DMA scratch, etc. in `static` storage (the callback is single-task, non-reentrant) or in a
dedicated larger stack. See `cdc1_control.c` (jsmn tokens + reply buffers are `static`).

## 5. Firmware self-attestation + machine-checkable telemetry

The running firmware reports its own identity and proof-of-behaviour over CDC1 `status` (build prio,
measured stall, loop counters, fault count, ring drops). This closes provenance gaps (which build is
actually running?) and powers the HIL gates. Prefer a **machine-readable** signal a test can assert on
over an operator eyeball. Every reply is one line of valid JSON.

## 6. Overlay discipline

The probe is an overlay of upstream debugprobe (stable tag). Keep per-file diffs minimal and tagged
`// [HACKAGOTCHI]`; new functionality goes in **new** files (`crash_box`, `watchdog_task`,
`uart_bridge`, `spsc_ring`, `cdc1_control`) wherever possible, so an upstream bump is a small re-diff.
Vendored third-party code is single-header where possible and listed in `THIRD-PARTY-NOTICES.md`.

## 7. Prove it on hardware (gates-first)

No architectural claim is "done" until a falsifiable HIL test asserts it from the right signal and can
emit FAIL. Host-test pure logic off-target (`tests/m1/ring_test.c`); HIL-test integration on the
device (`tests/m1/*_hil.py`). Decode the built artifact (`nm`/`strings`/`addr2line`/descriptor), don't
trust the source diff. Disclose every deferred item in the verdict.

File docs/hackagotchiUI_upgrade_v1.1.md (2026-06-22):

# Hackagotchi UI Upgrade — v1.1 (grounded)

**Status:** planning doc for the *later* graphics/UI rewrite (after M3 ships the faithful port).
**Supersedes:** `hackagotchiUI_upgradev1.0.md` (a Ghost Labs spec written by an agent with **no context of
our hardware bring-up** — Gates 0–2, M1, M2, M3.0–M3.2). This doc keeps v1.0's good UI/aesthetic ideas and
**rejects its architectural prescriptions that contradict what we proved on hardware.**

---

## 0. Ground truth the v1.0 spec didn't have

These are *established by HIL evidence* in this repo (see `tests/{gates,m1,m2,m3}/*_RESULTS.md`,
`docs/engineering-plan.md`, the product-focus memory). The upgrade must respect them:

- **F1-1 — SINGLE-CORE FreeRTOS.** The base is debugprobe **v2.2.3**, `configNUM_CORES=1`. SMP (and the
  #189 flash regression) came later; we deliberately stay on the stable single-core tag. **There is no
  "Core 1" to give the UI.** Coexistence is by **priority/preemption**, proven across 5000+ flash cycles.
- **XIP, no flash-pinning.** We dropped `copy_to_ram` → run from flash XIP (**+139 KB SRAM**, free 35→174 KB).
  The soak proved the DAP hot path stays warm in the 16 KB XIP cache **without** `__not_in_flash_func`
  pinning *for the light M3 UI* (SWCLK is PIO-generated; the SWD servicing code is tiny).
  **[Corrected after v1.1 HIL]** This held only up to a *light* UI. The shipped v1.1 render loop (sprite
  blit engine + ghost compositing, ~8 blits/frame) churns a large enough flash-instruction working set to
  **evict** the DAP framing path from the shared XIP cache, adding a QSPI refill inside the USB-IN window
  → a measurable, **still-0-stall** retryable-desync regression (~1.4–3.0% vs v1.0's ~0.2%, proven by
  interleaved A/B on the bench). The fix is *not* to pin the whole image back to RAM, but to pin only the
  DAP/USB hot path (~19 KB of the +139 KB win) via **`HG_PIN_DAP`**, keeping XIP-default for everything
  else; the pinned image soaks **0/500**. See `docs/firmware-conventions.md` §2 + `mcu-bringup-playbook.md` §10.
- **No user button.** GP27 (the only expansion button) became **SWDIO** at Gate 1; GP26 → SWCLK. Input is
  **auto-cycle + CDC1** (`next`/`prev`/`{"q":"screen","n":N}`). External buttons/switches are a future
  soldering option (broken-out Dx pads only — GP16/17 aren't pads).
- **Hard-dropped screens.** Oscilloscope (ADC on GP26=SWCLK), PWM Lab (GP28=SD-CS + GP2=SD-SCK), Logic
  Analyzer (monitors the whole locked bus) **cannot exist** — they need runtime pin re-mux, which wedges
  SD/SWD/UART. I2C-scanner is pointless (only our own OLED+RTC on I2C1) and contends the bus.
- **Status LED = onboard WS2812 NeoPixel** (GP12 data + GP11 power), driven via **PIO on pio1** (SWD owns
  pio0). The tiny onboard RGB (GP16/17) proved unreliable (color ≠ spec + competes with the GP25 USB-LED).
- **i2c1 is SHARED** (OLED 0x3C + PCF8563 RTC 0x51), GP6/GP7, behind a FreeRTOS mutex. Any OLED change
  must keep the RTC working on the same bus.
- **Concurrency idiom = single-writer published snapshots / SPSC rings**, never shared mutable structs.
  The dashboard already reads recorder/RTC state via a seqlock `rec_snapshot_t` and touches i2c1 only for
  `ssd1306_show()`. The M2 "two-ring" rule is load-bearing.
- **R1 (make-or-break):** nothing on the DAP/USB hot path may block. The OLED `ssd1306_show()` (~23 ms at
  400 kHz) is proven-safe **only** because it runs at the lowest priority + fully preemptible; the M2/M3
  coexist soaks pass at the **250 ms** redraw cadence.

---

## 1. Adversarial verdict on v1.0, claim by claim

| v1.0 claim | Verdict | Why (grounded) |
| --- | --- | --- |
| **Dual-core split**: Core 0 diagnostic, Core 1 UI; communicate via `multicore_fifo` | **REJECT** | Single-core FreeRTOS (F1-1). There is no spare core without enabling the #189-regressed SMP path we avoided, or bare-metal core1 fighting FreeRTOS. Our priority model already gives the UI "free" time. |
| **"No shared volatile flags; use multicore FIFO"** | **REJECT** | Moot (single core) and counter to our *proven* single-writer-snapshot idiom. Keep snapshots/SPSC. |
| **`__not_in_flash_func()` the UI loop + ISRs to protect the XIP cache** | **REJECT (the *prescription*) — but the *fear* was real** | **[Corrected after v1.1 HIL]** Pinning the *UI loop* is the wrong fix — the UI is the cache aggressor; you can't protect the cache by moving the aggressor into it, and the UI is lowest-prio + preempted anyway. But "cache footprint can't threaten DAP timing" was **wrong**: the heavy v1.1 render loop *does* evict the flash-resident DAP path (priority schedules CPU, not the XIP cache). The right fix pins the **victim** — the DAP/USB hot path (~19 KB) — to SRAM via `HG_PIN_DAP`, not the aggressor. |
| **Framebuffer in an isolated SRAM bank (`.sram4`)** | **DEFER / measure-first** | A real RP2040 technique for DMA-vs-USB AHB contention, but M2 already showed the OLED coexists at ~1% retryable. Only worth it *if* a DMA flush (below) shows measurable contention. Don't pre-optimize. |
| **DMA-push the 1025-byte framebuffer to I2C, CPU-free** | **ADOPT** | Genuine win: frees the CPU during the flush and (with FM+) shrinks the bus-hold. Our ssd1306 lib **already** uses the 1025-byte / `[0]=0x40` layout, so only the transfer path changes. Must still hold the i2c1 mutex for the DMA's duration (RTC shares the bus). |
| **`frame_dirty` — only flush on change** | **ADOPT** | We currently redraw every 250 ms. A dirty-flag cuts i2c1 traffic hugely (most frames are identical), freeing the bus for the RTC and lowering coexistence pressure. High value, low risk. |
| **I2C1 @ 1000 kHz (Fast Mode Plus)** | **ADAPT — with care** | FM+ shrinks the flush ~23 ms→~9 ms (good for R1). **But the PCF8563 RTC shares this bus and is typically rated 400 kHz.** Options: (a) verify the specific RTC tolerates FM+; (b) keep 400 kHz; (c) clock-switch around RTC transactions. Do **not** blindly set 1 MHz — it risks the clock. |
| **Reactive state machine (IDLE / UART_RX / ERROR), cat animation scales with packet rate** | **ADOPT** | Already feasible from the snapshot (`rx_total` delta, `wedge`, `alert`). This is the heart of the "alive" feel. Map states to snapshot fields, not FIFO messages. |
| **`STATE_OSC` / `STATE_PWM` (cat interacting with waveforms/wheels)** | **REJECT** | Those screens are hard-dropped (pin conflicts). No scope/PWM to react to. |
| **Sprite system (1-bit bitmap blit, lightweight struct)** | **ADOPT** | Needed for richer graphics than line-art. Sprites are `const` → live in flash/XIP, blit directly (no SRAM copy needed). This is the right primitive for the cat rewrite. **[Corrected after v1.1 HIL]** The *sprite data* in flash is fine; it's the larger *blit-engine code* working set that pressures the XIP cache — handled by pinning the DAP path (`HG_PIN_DAP`), not by changing the sprite layout. |
| **Ghost Labs "Phantom" mascot + day/night variants (RTC)** | **ADOPT (aesthetic)** | Pure identity/polish; RTC day/night is trivial (we cache the clock). Good for the rewrite the user wants. |
| **Buzzer soundscapes (boot jingle, error buzz), non-blocking** | **ADOPT** | We have the buzzer HAL (GP29 PWM, non-blocking, serviced off the hot path). Jingles/alerts fit M3.3. |
| **MicroSD FatFs blackbox logging, non-blocking** | **ALREADY DONE** | That's M2 (the recorder). The UI just reads its snapshot. |
| **User-button HW interrupt → Core 1 for UI toggle/ack** | **REJECT** | No button (GP27=SWDIO). Use CDC1 nav; if external buttons get soldered later, route them to a free Dx pad + the existing nav intents. |
| **Battery voltage via onboard divider → "hunger" level** | **DEFER — needs HW** | The XIAO RP2040 has **no** battery divider (not a Pico LiPo). All ADC-capable pins (GP26-29) are taken (SWCLK/SWDIO/SD-CS/buzzer). Needs external sense HW on a future board rev. Cute idea, park it. |
| **SSD1306 Horizontal Addressing Mode for linear DMA** | **ADOPT (with DMA)** | Correct prerequisite for a single-shot full-frame DMA. Fold in when we do the DMA flush. |

**Net:** v1.0's *UI vision* (reactive sprite-based mascot ecosystem, DMA/dirty rendering, soundscapes) is
good and worth building. v1.0's *system architecture* (dual-core, flash-pinning, button, battery sense,
scope/PWM states, 1 MHz bus) is mostly wrong for our proven hardware/firmware and must not be copied.

---

## 2. The grounded v1.1 upgrade plan (for after M3)

**Keep the M3 spine** (lowest-prio render task, snapshot-only reads, i2c1-mutex'd show, CDC1 nav,
self-attestation with the show-success counter). Layer the upgrade on top:

**Phase A — render pipeline (perf + headroom).**
1. **Dirty-flag rendering** — hash/compare the framebuffer (or track a dirty bool per screen); only
   `ssd1306_show()` when it changed. Biggest, safest win; cuts i2c1 traffic → more RTC headroom + lower R1
   pressure. (Lets a faster animation cadence be cheap.)
2. **DMA framebuffer flush** — push the existing 1025-byte buffer via a DMA channel to I2C1 TX, holding the
   i2c1 mutex for the transfer; switch the SSD1306 to Horizontal Addressing. Frees the CPU during the flush.
3. **Conditional FM+** — only after confirming the PCF8563 tolerates it (else keep 400 kHz, or clock-switch
   around RTC reads). Re-run the coexist soak at the new cadence — *the soak is the gate, not the spec.*

**Phase B — graphics rewrite (the part the user wants).**
4. **Sprite engine** — a tiny `sprite_t { w,h, const uint8_t *bits }` + blit (XOR/OR/clear) into the
   framebuffer. Sprites are `const` (flash/XIP). Replace the line-art cat with sprite frames.
5. **Reactive mascot state machine** — `IDLE / RX / WEDGE / FAULT` derived from the snapshot (rx-rate,
   wedge, alert, SD error). Animation speed scales with `tp_now`. Add the Ghost Labs phantom + RTC
   day/night variants. The NeoPixel mirrors state (idle=dim, RX=green pulse, wedge/fault=red).
6. **Soundscape** — boot jingle + per-state buzzer motifs via the existing non-blocking HAL (M3.3 wires
   wedge/fault/trigger; the rewrite adds the jingle + RX blips).

**Phase C — input & expansion (optional, HW-gated).**
7. If external buttons get soldered (free Dx pad), route them to the existing `dash_nav_step`/`dash_nav_to`
   intents + a "select/ack" intent — zero architecture change.
8. Battery/hunger only on a board rev that adds a real divider on a free ADC pin.

**Non-negotiables for every phase:** stay single-core + priority-preemptive; keep the render task lowest-
prio; read state only via published snapshots; keep i2c1's only writers the OLED show + RTC (mutex'd);
**gate every change on the probe-rs coexist soak (0 stalls, rec_drop=0)** — not on the spec's assertions.

---

## 3. One-line summary
Take v1.0's *look* (reactive sprite mascot + ghost, DMA/dirty rendering, soundscapes, day/night); throw out
its *architecture* (dual-core, flash-pinning, a button, battery sense, scope/PWM, 1 MHz bus) — all of which
assume a device we don't have. Build the upgrade on the proven M3 spine, soak-gated.

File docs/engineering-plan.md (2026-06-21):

# Hackagotchi — Engineering Plan

**Status:** Execution plan. Companion to `docs/c-firmware-analysis.md` (the decision doc). The *whether* is settled — this is the *how*. Folds in three research reports: yapicoprobe verdict (A), reliability stack (B), gate test strategy (C).

**Last verified:** 2026-06-19. Facts re-confirmed this session against live sources are tagged ✅; report-flagged caveats are preserved as ⚠️.

---

## 1. Scope & principles

**Goal.** Evolve the Hackagotchi device (Seeed XIAO RP2040 + expansion: SSD1306 128×64 OLED on I2C GP6/GP7; microSD on SPI0 GP2/3/4/CS28; PCF8563-class RTC @0x51; buzzer GP29; button GP27; LEDs GP25/26/17; target-UART tap on UART0 GP0/GP1) from its current MicroPython firmware into a **single C firmware** that is simultaneously:
- a **real SWD debug probe** (fork of `raspberrypi/debugprobe`, C + Pico SDK + TinyUSB + FreeRTOS SMP + PIO SWD), and
- the full **Hackagotchi OLED dashboard + UART "black-box" recorder**, reimplemented in C.

**Principles (in priority order):**

| # | Principle | What it means in practice |
|---|---|---|
| 1 | **Reliability by construction** | The probe path must NEVER stall/corrupt. The architecture (task priorities, no blocking on the DAP path), not tooling, is the lever. Tooling only *enforces and regression-tests* it. |
| 2 | **Gates-first** | No UI-porting code is written until **Gate 1** proves SWD ⇄ dashboard coexistence. Each gate is cheap to abandon; a failed gate kills/reshapes the plan before sunk cost. |
| 3 | **Reuse over reinvent** | Established libs for SWD/USB/SD/OLED/JSON/tests. Hand-roll only the ~40-line SPSC ring and the few glue macros. |
| 4 | **PicoInky stays a frozen test mule** | The MicroPython PicoInky repo/firmware is unchanged by this work — it is the *target* board against which the probe is validated, and a behavior reference for the ported screens. Hackagotchi is a **new C codebase** (this repo's `firmware/c/` subtree), not a mutation of the MicroPython tree. |

---

## 2. Base decision — debugprobe 2.2.3 NOW, yapicoprobe re-evaluated LATER

**Decision: fork `raspberrypi/debugprobe` pinned to tag `debugprobe-v2.2.3`. Do NOT fork yapicoprobe now.**

### Verified ground-truth (this session)
- ✅ **`debugprobe-v2.2.3` is a real tag** (Jul 7 2025, "Debugprobe re-release v2.2.3"). Latest upstream is `debugprobe-v2.3.1` (May 27 2026); `v2.3.0` was Feb 11 2026.
- ✅ **Issue #189 is real and as described:** FreeRTOS-SMP flash-programming regression introduced by commit `457e048`, intermittent flash hangs / "cannot read IDR" / corrupted target binary, **GDB+OpenOCD halt unaffected — flash-path only**. Absent from 2.2.3; reappears when 457e048 is cherry-picked. This is exactly why the Gate-1 bar is "1000 cycles, 0 fails," not a happy-path flash. ⚠️ It *may* be fixed in 2.3.x — see trigger below.
- ✅ **yapicoprobe `master` does not currently build on current `arm-none-eabi-gcc`** (issue #197, opened May 11 2026, still **open**, "high prio / in progress": `cannot read spec file 'nosys.specs'`). This directly substantiates Report A's reliability concern.

### Why debugprobe 2.2.3 now
- It is the **Raspberry Pi-maintained reference** every host tool (OpenOCD, pyOCD, probe-rs) is tested against → best fit for "reliability first / well-established."
- The gates were **defined against it**; changing base mid-plan invalidates Gate 0.
- 2.2.3 sits **before** the #189 SMP regression → safest known-good flash path.

### Why NOT yapicoprobe now (reinforced this session)
- **Bus-factor ≈ 1** + a visibly bumpy tracker (#197 build-broken-on-current-GCC, #198/#183 RTT regressions, RP2350 experimental). A sellable, reliability-critical product on a single-maintainer hobby fork is the exact exposure we're avoiding.
- **No umbrella `LICENSE` file** (GitHub license API returns `null`) — a real legal-hygiene problem for a sold product, even though per-file headers are clean (MIT + Apache-2.0 + SEGGER-BSD-1clause + FreeRTOS-MIT, no GPL).
- **Much larger surface** (NCM networking, sigrok, MSC, SystemView) we don't need — more to audit/break, opposite of lean gates-first.
- **No XIAO support either way** → no head start from adopting it.

### What we DO take from yapicoprobe — as a *design reference*, not a base
- Its **FreeRTOS SMP task-priority table** is a free, battle-tested template for our own (LED 30, **TinyUSB 28**, debug-CDC 26, sigrok 9, MSC-writer 8, SystemView 6, **UART-bridge 5**, **DAPv2 exec 3**, RTT-console 1, with the heavy RTT task pinned to core 1 via `vTaskCoreAffinitySet(…, 1<<1)`).
- Its `src/daplink-pico` MSC and RTT-to-CDC plumbing are **drop-in candidates later** (MIT/Apache).
- Cross-check role: run it **at Gate 0 only** as an A/B second-opinion probe firmware. If stock 2.2.3 ever shows a link issue our fork can't explain, yapicoprobe isolates "our fork" vs "RP2040-SWD-in-general."

### Trigger condition to revisit yapicoprobe (or move base to 2.3.x)
Re-evaluate **only after Gate 1 passes**, and adopt only *features* (RTT-into-CDC, MSC UF2 drag-drop, the proven SMP model) — never wholesale — and only if **all** hold:
1. We actually want one of those features in the product, AND
2. yapicoprobe's tracker is green on our toolchain (#197-class build breaks resolved on a pinned tag), AND
3. The license posture is settled (umbrella license confirmed with rgrr, or we've shed SEGGER/sigrok so the residual is plain MIT/Apache).
- **Separately:** once Gate 1 is green on 2.2.3, spike whether `debugprobe-v2.3.1` (post-#189-fix) is a viable newer base; if its flash path passes our Gate-1 soak, prefer it over 2.2.3 to ride upstream maintenance. ⚠️ Do not assume — prove it with the soak.

---

## 3. Adopted toolchain & libraries — "the reliability stack"

Versions are **flagged, not blindly pinned** — confirm against the live tree at adoption time, then pin by commit/tag in CI.

### MUST-HAVE — adopt in full

| Concern | Tool / library | Version (verify→pin) | License | Notes |
|---|---|---|---|---|
| Probe base | `raspberrypi/debugprobe` | tag `debugprobe-v2.2.3` ✅ | BSD-3 | Fork base. SWD-over-PIO, CMSIS-DAP v1/v2. |
| RTOS | FreeRTOS-Kernel (SMP) | submodule, pin SHA | MIT | `configNUMBER_OF_CORES=2`, `configUSE_CORE_AFFINITY`. |
| SDK / USB | Pico SDK + TinyUSB | SDK pin (debugprobe uses 2.x); TinyUSB per-SDK | BSD-3 / MIT | `cdc_dual_ports` is the 2×CDC reference. |
| SD / FAT | `carlk3/no-OS-FatFS-SD-SDIO-SPI-RPi-Pico` (wraps ChaN FatFs) | ~v3.6.2 | BSD-style | SPI0 microSD. **Writes block → low-prio task off the DAP core, never on hot path.** |
| OLED | `daschr/pico-ssd1306` | pin SHA | MIT | Near 1:1 with existing framebuf calls. Render to RAM FB in dashboard task; `ssd1306_show()` I2C flush at low prio/low rate, off hot path. |
| JSON (CDC1 control) | `zserge/jsmn` | single-header, pin SHA | MIT | **Zero-allocation tokenizer** (offset/length into the RX buffer). NOT cJSON (malloc-per-node → heap frag on 264 KB RP2040). Wrap iterate-kv boilerplate once + host-unit-test it. |
| Ring buffer | Pico SDK `queue_t` + hand-rolled SPSC ring (~40 lines) | SDK | BSD-3 | Single-producer/consumer UART path. Unit-tested. **No library** — a dep here is over-engineering. |
| Fault dump | Pico SDK `panic`/`hard_assert`/`assert`/`invalid_params_if` + custom `isr_hardfault`/`HardFault_Handler` override | SDK | BSD-3 | M0+ has **no stack-limit register** → silent stack overflow is real. Capture stacked frame (R0–R3, R12, LR, PC, xPSR) to a reserved-RAM "crash box" surviving reset; dump over CDC; reboot via WDT. Critical because the device often runs **probe-less**. (pico-sdk #228 pattern.) |
| Task health | FreeRTOS software-watchdog task feeding the **one** RP2040 HW WDT | SDK + FreeRTOS | — | Each monitored task checks in; low-prio watchdog task verifies all checked in within deadline, then `watchdog_update()`. Plus `configCHECK_FOR_STACK_OVERFLOW=2` + `vApplicationStackOverflowHook`, `configUSE_MALLOC_FAILED_HOOK=1`. **Primary defense against a blocking call stalling DAP.** |
| Host unit tests | Unity + CMock via **Ceedling 1.0** (ThrowTheSwitch) | 1.0 | MIT | x86 host tests for portable logic; mock HW edges (SD/OLED/USB) at the seam. |
| Static analysis | GCC `-Wall -Wextra -Wshadow -Wconversion -Wundef -Wdouble-promotion`, **`-Werror` in CI**, **`-fanalyzer`** | GCC pin | — | Tier-zero, free, highest bugs/minute. |
| Static analysis | `cppcheck` + `clang-tidy` (curated: `bugprone-*`, `cert-*`, `clang-analyzer-*`, selective `readability-*`) | cppcheck ~2.21 | — | Run **both** (disjoint bug classes). Our code only — exclude vendored SDK/FreeRTOS/TinyUSB. `clang-tidy` needs `compile_commands.json` via `-DCMAKE_EXPORT_COMPILE_COMMANDS=ON`. Curate-then-grow. |
| Heap | FreeRTOS `heap_4` (default), instrumented | — | — | **Gate-1 data decision**: keep `heap_4` (supports `vPortFree`, `xPortGetFreeHeapSize`/`…MinimumEverFreeHeapSize`) unless Gate 1 shows fragmentation alloc failures → only then retreat to `heap_1`. |

### NICE-TO-HAVE — adopt when a real need appears

| Tool | When | Caveat |
|---|---|---|
| **SEGGER RTT** (target-side `SEGGER_RTT.c/.h`) | Near-zero-overhead firmware-diagnostic logging that doesn't block on UART; our probe can *be* the RTT host. | BSD; commercial-OK with attribution. Promote to MUST-HAVE only if we later adopt yapicoprobe's RTT plumbing. Keep separate from the recorded target-UART telemetry. |
| **SEGGER SystemView** (visualizer) | **Bring-up / Gate-1 validation only** — visually prove the dashboard task never preempts DAP. | ⚠️ **Free tier is non-commercial only; commercial use needs a paid license.** **Keep it OUT of the shipping image** — bring-up tool, not a product dependency. |
| **HIL test in CI** (self-hosted mac-mini runner: pyOCD/OpenOCD + pytest, real probe + target) | After Gates 0–2 pass manually. Start with a smoke test (flash target, read IDCODE, assert), not a matrix. | Real maintenance cost (physical rig, flaky USB). |
| **CodeChecker** (Ericsson) | When analyzer output volume grows; aggregates clang-tidy/cppcheck with suppression mgmt. | Premature day one. |
| **ETL** (`ETLCPP/etl`, fixed-capacity no-heap containers) | Only if the dashboard/parser layer is written in **C++**. | MIT, but it's C++ — not worth a language mix just for a fixed vector. |

### EXPLICITLY SKIP — over-engineering for a small product

| Skip | Why |
|---|---|
| **Full MISRA C compliance** | Safety-cert friction (thousands of documented deviations) for little gain over `-Wall -Wextra -Werror -fanalyzer` + cppcheck + clang-tidy. At most run cppcheck's MISRA addon occasionally as a *suggestion source*, never a gate. |
| **Coverity / PVS-Studio / paid Infer** | The free trio covers the vast majority. Justified only at scale / under compliance mandate. |
| **cJSON / full JSON DOM** | malloc-per-node heap fragmentation on RP2040. Messages are tiny/fixed-shape → jsmn. |
| **Bespoke logging/trace framework** | RTT or plain CDC `printf` suffices. |
| **Custom ring-buffer / data-structure libs** | `queue_t` + hand-rolled SPSC ring, unit-tested. |
| **Fancy WDT (external chip / challenge-response)** | SW-watchdog-task-feeds-one-HW-WDT is the standard, sufficient pattern. |

---

## 4. Reliability methodology — how the C firmware beats the MicroPython original

The MicroPython firmware was *resilient by reboot* (the boot contract: never sit blank, re-probe, fall into a minimal loop on exception). The C firmware must be **resilient by construction** — caught earlier, observable when probe-less, and provably non-blocking on the DAP path.

### 4.1 Concurrency discipline (the #1 lever)
- **Core 1 = DAP + autobaud, untouched.** **Core 0 = TinyUSB + UART bridge + a LOW-priority dashboard task.**
- **Priority hierarchy** (modeled on yapicoprobe's): TinyUSB > UART-bridge > DAP-exec-glue **≫ dashboard task** (lowest, e.g. idle+2). The dashboard (OLED/SD/beep) must be *preemptible* by everything on the USB/probe path.
- **Pin the dashboard task to core 0 explicitly** (`vTaskCoreAffinitySet`) — `tskNO_AFFINITY` is **wrong** here; it must never land on core 1 beside DAP.
- **No blocking on the DAP/USB hot path, ever:** no `ssd1306_show()` I2C burst, no FatFs/SD write, no buzzer dwell, **no per-byte `strstr`** on the RX hot path. The bridge does a bounded SPSC enqueue; the dashboard/recorder drains and does the slow work at low priority.
- Gate 1 includes an **adversarial `busy_wait_ms(50)`** variant in the dashboard task to prove even a long core-0 stall (a slow SD write proxy) doesn't corrupt DAP.

### 4.2 Error handling in C (replaces try/except)
- **Error-code enum + single-exit `goto cleanup`** — the canonical idiom (Linux kernel, SQLite, libgit2). One `typedef enum { OK=0, ERR_… } pd_err_t;` per subsystem; resources released in reverse order at a bottom label. **Do not emulate C++ exceptions.**
- **Two boring macros:** `PD_TRY(expr)` (assign + `goto cleanup` on error) and `PD_CHECK(cond, code)`. Keep them few.
- **Pico SDK assert/panic is the foundation:** `assert`, `hard_assert` (→ `panic()` in release), `invalid_params_if`. `panic()` for unrecoverable invariants; error codes for anything a caller can handle.

### 4.3 Fault handler + crash box (because the device runs probe-less)
- Override the weak `isr_hardfault`/`HardFault_Handler`: capture the stacked exception frame → write to a **reserved-RAM crash box** that survives a warm reset → reboot via WDT → on next boot, dump the decoded fault over CDC (and/or RTT).
- Keep the **`.elf`** as a CI artifact to symbolicate these dumps and RTT.

### 4.4 Task health → single HW watchdog
- SW-watchdog pattern (§3): per-task check-in counters; a low-prio watchdog task feeds the lone RP2040 HW WDT only when **all** monitored tasks checked in on time. A wedged DAP/bridge/dashboard task → WDT not fed → chip resets.
- `configCHECK_FOR_STACK_OVERFLOW=2` + `vApplicationStackOverflowHook` compensate for the missing M0+ stack-limit register; `configUSE_MALLOC_FAILED_HOOK=1`.

### 4.5 Testable-logic structure (so logic ships verified, not hardware-hoped)
- **If it touches a register, it lives behind an interface and gets mocked; if it's algorithmic, it gets a host test.** High-value testable units (the project's actual risk areas):
  - UART **line/ring buffer** + framing,
  - the **wedge detector** state machine,
  - the **JSON control parser** (CDC1),
  - **log-rotation / session-index** logic ported from the MicroPython firmware (session-based auto-incrementing log files).
- These get Unity/CMock host tests *as they're extracted from the MicroPython port*, gated in CI.

---

## 5. Work breakdown structure

Phased, gates-first. Estimate reconciled to the prior **~22–31 eng-day** total. Ranges reflect report-flagged uncertainty (hardware bring-up, dual-CDC-on-macOS, soak duration).

| Milestone | Tasks | Reliability-stack mapping | Est (eng-days) |
|---|---|---|---|
| **M0 — Gates** (no UI port) | Build/flash stock 2.2.3 (bare XIAO); **Gate 0** (probe halts/erases/flashes a spare Pico). Lock SWD pin map → `board_hackagotchi_config.h`. Fork + remap SWD + one core-0 OLED coexistence task; **Gate 1** soak (≥1000 cycles, +adversarial 50 ms variant); record heap watermark → heap_4/heap_1 decision. Add CDC1 + jsmn status handler; **Gate 2** (two nodes, DAP binds, JSON round-trip). | Pico SDK base; `daschr/pico-ssd1306`; `heap_4` instrumented; jsmn; SPSC ring; the gate harness scripts (§9). | **6–9** |
| **M1 — Probe + bridge + control core** | Productionize the fork on the locked pin map. Robust UART bridge (CDC0) with bounded SPSC ring; CDC1 JSON control (jsmn) — `status`, `next`/`prev`/`dump` equivalents. **Fault handler + crash box; SW-watchdog task; stack-overflow/malloc hooks.** Per-interface USB string descriptors for stable node mapping. | §4.1 concurrency, §4.2 error idiom, §4.3 fault box, §4.4 watchdog; jsmn; SPSC ring (host-tested). | **4–6** |
| **M2 — SD + black-box logging** | `carlk3` FatFs on SPI0 (off-hot-path low-prio writer task). Port **session-based auto-incrementing log files** + UART telemetry recorder from MicroPython. RTC (PCF8563 @0x51) read for timestamps. | FatFs (low-prio task); log-rotation/session-index logic **host-unit-tested**; wedge detector state machine host-tested. | **3–5** |
| **M3 — Core screens** | OLED dashboard task (RAM framebuffer; low-rate flush). Port the *highest-value* mono screens first: live UART/telemetry view, recorder status, probe status, clock. Button (GP27) + LEDs (GP25/26/17) + buzzer (GP29, non-blocking, off hot path). | `daschr/pico-ssd1306`; dashboard task at lowest prio pinned core 0; buzzer never on hot path. | **3–4** |
| **M4 — Full UI parity** | Remaining Hackagotchi screens to parity with the MicroPython OLED family. Settings/config persisted to SD or flash. JSON control surface for host-side `dashboard_host.py`-style streaming if retained. | Reuse mono-page data conventions from PicoInky as a *behavior reference* (no code reuse — different language). cppcheck/clang-tidy curated set tightened. | **3–4** |
| **M5 — Polish / release** | CI green on the AUTOMATED checks it can run (build + `analyze.sh` static analysis + host unit tests); the HIL gates are **operator-attested on the release image** (CI cannot run hardware — see `docs/release-readiness.md`). Version compiled into the firmware (`{"q":"status"}` `ver`). Tagged GitHub Release with `.uf2`+`.elf` **+ NOTICE/LICENSE**. Docs: pin map, license/NOTICE bundle, flashing guide, README/CONTRIBUTING. License hygiene pass (BSD-3/MIT/Apache NOTICEs shipped; SystemView/sigrok confirmed absent from the shipping image). | CI/CD §7; HIL attested on-image; license posture (§2). | **3–4** |
| | | **Total** | **22–32** |

**Gating rule:** M1+ do not start until **Gate 1 passes**. M0 is abandon-cheap.

---

## 6. The 3-gate plan

**Locked SWD pin map (decide before any soldering).** Stock 2.2.3 defaults ✅ (`board_pico_config.h` @ v2.2.3): `SWCLK=GP2, SWDIO=GP3, RESET=GP1, UART_TX=GP4, UART_RX=GP5, uart1, LED=GP25, PROBE_SM=0`. **Collision:** GP2/3/4/28 are the Hackagotchi SD bus; GP4/5 aren't even broken out on the XIAO; the jancumps XIAO fork already moves the UART bridge to **GP0/GP1** ✅. **Recommended remap:** SWCLK/SWDIO onto two broken-out, uncommitted XIAO pins that avoid GP2/3/4/28 (SD), GP6/7 (OLED), and ideally GP0/1 (UART tap) — candidate **SWCLK=GP26, SWDIO=GP27** *if the button (GP27) is reclaimed*. ⚠️ **A wrong SWD pin fails Gate 1 silently as "no IDCODE."** Lock it in `board_hackagotchi_config.h` and record it in the gate doc; validate by Gate-0-style `probe-rs info` on the actual soldered header **before** trusting Gate 1.

✅ `probe-rs` subcommands confirmed present: `list`, `info`, `erase`, `download` (`--verify`, `--chip` in flattened `ProbeOptions`/`BinaryDownloadOptions`), `verify`, `reset`, `read`, `write`, `benchmark`.

### GATE 0 — stock probe firmware halts/erases/flashes a separate target
**Objective:** prove the *unmodified upstream* firmware turns the XIAO into a working SWD probe against a separate target, on THIS host (macOS) + toolchain. 0% porting. If this fails, nothing downstream matters.

**Setup:** Probe = **bare XIAO, no expansion board** (so stock GP2/GP3 SWD pins are legitimately free — isolates "does the probe work at all" from "on our pin map"; remap is a Gate-1 concern). Target = a **separate spare Raspberry Pi Pico** (plain RP2040 — not the XIAO, not a Pico W). Wiring: Probe SWCLK→Target SWCLK, SWDIO→SWDIO, **GND→GND (mandatory)**, optional RESET→RUN (only for `--connect-under-reset`). Power target via its own USB (don't backpower).

**Procedure / commands (macOS):**
```bash
# Build stock base
git clone --branch debugprobe-v2.2.3 --recurse-submodules \
  https://github.com/raspberrypi/debugprobe.git
cd debugprobe && mkdir build && cd build
cmake .. -DDEBUG_ON_PICO=OFF        # standalone probe
make -j                              # -> debugprobe.uf2
# Flash XIAO via BOOTSEL: copy debugprobe.uf2 to RPI-RP2, or: picotool load -x debugprobe.uf2

# Enumeration / DAP-present
system_profiler SPUSBDataType | grep -iA8 -E 'CMSIS|debugprobe|Picoprobe'
ioreg -p IOUSB -l -w0 | grep -iE 'CMSIS|debugprobe|IOCalloutDevice'
ls /dev/cu.usbmodem*

# probe-rs path (preferred: scriptable, --verify built in)
probe-rs list
probe-rs info --chip RP2040 --protocol swd
probe-rs erase --chip RP2040
probe-rs download --chip RP2040 --verify blink.elf
probe-rs reset --chip RP2040

# openocd cross-check (independent second opinion)
openocd -f interface/cmsis-dap.cfg -f target/rp2040.cfg \
  -c "init; reset halt; flash write_image erase blink.elf; verify_image blink.elf; reset run; exit"
```
Use a known `blink.elf` from `pico-examples` so the blinking LED corroborates `verify`.

**Pass/fail (quantitative):** PASS = `list` shows CMSIS-DAP; `info` reads a valid RP2040 IDCODE; `erase` 0-error; `download --verify` → `Verification successful` (exit 0); LED blinks after `reset`; openocd `verify_image` → verified; **5/5 consecutive clean runs**. FAIL = any non-zero exit, `Verification failed`, no probe in `list`, or no IDCODE.

**Optional A/B:** run yapicoprobe once here as a second-opinion probe firmware (do not adopt). If 2.2.3 shows a link issue our fork can't explain, this isolates "our fork" vs "RP2040-SWD-in-general."

**Evidence:** `gate0/` stdouts (`probe-rs_info.txt`, `download_verify.txt`, `openocd.txt`, `usb_enum.txt`) + blink video + versions (`probe-rs --version`, openocd, fw SHA/tag, macOS).

### GATE 1 — fork + SWD-remapped + ONE low-prio OLED task survives a sustained flash loop
**Make-or-break.** Prove that with SWD remapped off the SD bus AND a continuous core-0 OLED task, the probe flashes the target thousands of times with **zero** corruption/stall/timeout, and quantify heap headroom.

**Built:** fork 2.2.3; add `board_hackagotchi_config.h` (remapped SWCLK/SWDIO, UART GP0/GP1, LED GP25); add **one** low-prio FreeRTOS task **pinned to core 0** that only drives the OLED (`daschr/pico-ssd1306` on GP6/GP7): increment a counter, render a few lines, `ssd1306_show()` in a loop with a small delay. DAP stays on core 1, untouched. This is a **coexistence harness, not the dashboard.** Build **`heap_4`** first.

**Setup:** Gate-0 wiring **plus the Hackagotchi expansion board attached** (real OLED live; SD/buzzer pins physically present to prove remapped SWD truly avoids them). SWD on the **remapped** pins. Optional: logic analyzer or the spare XIAO-UART bridge on GP0 telemetry for an independent stall trace.

**Procedure:** (1) flash fork; confirm `probe-rs info` reads the target on the **remapped** pins *before* stressing (proves the remap). (2) confirm OLED counter ticking + probe enumerated simultaneously. (3) run the soak ≥1000 cycles (~2–4 h). (4) periodically emit `xPortGetFreeHeapSize()` + `xPortGetMinimumEverFreeHeapSize()` over CDC. (5) tally + inspect min-ever-free watermark.

**Stress harness** (`gate1_soak.sh`): alternate **two distinct images** (so `--verify` is a real read-back diff), wrap every call in `timeout` (a DAP hang → detected stall, not infinite hang), run an **independent second `probe-rs verify`** (guards a lying download-verify), dump probe+USB state on first failure. Twin `gate1_soak_openocd.sh` runs the same loop with the openocd client (different DAP pipelining; #189 only showed under flash → vary the client).
```bash
#!/usr/bin/env bash
# gate1_soak.sh
set -uo pipefail
CHIP=RP2040; ELF_A=fixtures/blink_a.elf; ELF_B=fixtures/blink_b.elf
N=${1:-1000}; log=gate1/soak_$(date +%Y%m%dT%H%M%S).log; fails=0; stalls=0
for i in $(seq 1 "$N"); do
  elf=$([ $((i % 2)) -eq 0 ] && echo "$ELF_A" || echo "$ELF_B")
  if ! timeout 30 probe-rs download --chip "$CHIP" --verify "$elf" >>"$log" 2>&1; then
    rc=$?
    [ $rc -eq 124 ] && { echo "STALL/TIMEOUT cycle $i"|tee -a "$log"; stalls=$((stalls+1)); } \
                    || { echo "FAIL(rc=$rc) cycle $i"|tee -a "$log"; fails=$((fails+1)); }
    probe-rs list >>"$log" 2>&1
    system_profiler SPUSBDataType | grep -iA6 CMSIS >>"$log" 2>&1
  fi
  timeout 30 probe-rs verify --chip "$CHIP" "$elf" >>"$log" 2>&1 || \
    { echo "REVERIFY-MISMATCH cycle $i"|tee -a "$log"; fails=$((fails+1)); }
done
echo "DONE N=$N fails=$fails stalls=$stalls"|tee -a "$log"; exit $(( fails + stalls ))
```
**Adversarial variant:** add a `busy_wait_ms(50)` to the OLED task (slow-SD-write proxy) to prove a long core-0 stall still doesn't corrupt DAP. Do NOT yet add real SD writes or the buzzer.

**Pass/fail:** PASS = **1000 consecutive download+verify, 0 fails, 0 stalls** (`exit 0`), independent re-verify passes every cycle, OLED counter advanced throughout. Stretch: 5000 overnight. **Heap decision:** if min-ever-free stays comfortably positive (≳4 KB headroom, no monotonic decline) → keep `heap_4` (preferred; dashboard will malloc framebuffers/JSON). Retreat to `heap_1` only on fragmentation alloc failures (but `heap_1` forbids `vPortFree`, which the OLED lib / future tasks may need). FAIL = any corruption, stall, OLED freeze, downward-trending free heap (leak), or the adversarial variant failing.

**Evidence:** soak log w/ per-cycle timings + tally; heap watermark series (plot via `heap_plot.py`); OLED-counter timelapse; fork SHA; `board_hackagotchi_config.h`; chosen heap scheme + measured headroom. **This log IS the gate verdict.**

### GATE 2 — add 2nd CDC: two usbmodem nodes, DAP still binds, JSON round-trip
**Objective:** composite grows {DAP v2 + CDC0} → {DAP v2 + CDC0 + CDC1} cleanly: macOS enumerates **two** `/dev/cu.usbmodem*`, CMSIS-DAP still binds (probe-rs still works), `{"q":"status"}` round-trips on CDC1 while CDC0 carries the UART telemetry stream and DAP stays bound.

**Built:** merge the `cdc_dual_ports` pattern into the fork's `usb_descriptors.c` — add a 2nd CDC (3rd+4th interface pair + 2 endpoints), keep device descriptor IAD composite `0xEF/0x02/0x01` ✅ with an IAD per CDC, bump `CFG_TUD_CDC=2` + `ITF_NUM_TOTAL`/`EPNUM_*`. Tiny CDC1 line handler parses `{"q":"status"}` (jsmn) → one-line JSON reply `{"fw":"…","heap":NNN,"up":SS}`. CDC0 keeps bridging the target UART. Set **distinct USB interface-name strings** per CDC (`"Hackagotchi UART"` / `"Hackagotchi Control"`).

**Setup:** Gate-1 (probe + target + OLED live) + a known UART stream into GP0/GP1 RX so CDC0 has real traffic.

**Commands (the macOS node-identity problem is the crux):**
```bash
ls /dev/cu.usbmodem*            # expect TWO nodes
probe-rs list                   # CMSIS-DAP still present
probe-rs info --chip RP2040 --protocol swd
# Map name -> node ROBUSTLY (don't trust numeric suffix sort order):
ioreg -p IOUSB -l -w0 -r -c IOUSBHostDevice | \
  grep -iE 'IOCalloutDevice|bInterfaceNumber|USB Interface Name|kUSBString'
system_profiler SPUSBDataType   # shows IAD + each named CDC interface
# JSON round-trip on CDC1 while CDC0 carries UART and DAP is live (run concurrently):
cat /dev/cu.usbmodemCDC0 > gate2/uart_capture.txt &
( probe-rs info --chip RP2040 --protocol swd ) &
python3 - <<'PY'
import serial, json, time
p = serial.Serial('/dev/cu.usbmodemCDC1', 115200, timeout=2)
p.write(b'{"q":"status"}\n'); time.sleep(0.2)
line = p.readline().decode().strip(); print("REPLY:", line)
assert json.loads(line).get("fw"), "no valid JSON status reply"; print("PASS")
PY
wait
```
**Robust node ID:** map **interface NAME → `IOCalloutDevice` path** via `ioreg`/`system_profiler`, NOT the numeric `usbmodemXXXXn` suffix sort order (⚠️ not guaranteed stable across reboots/replugs). Document the mapping recipe in the gate doc.

**Pass/fail:** PASS = exactly **2** nodes; `list`+`info` still succeed (DAP unaffected); CDC1 returns valid JSON with expected keys in timeout; CDC0 simultaneously shows live UART bytes; **round-trip 100/100** with no DAP error during the burst; mapping stable across **3 replug + 1 host reboot**. FAIL = only 1 node, DAP disappears, malformed/no JSON, CDC0 stops carrying UART when CDC1 active, or node identity unresolvable without trial-and-error.

**Evidence:** `gate2/` — `system_profiler` IAD + 2 named CDCs, `ls` listing, 100-request round-trip log (count + latencies), concurrent UART capture, documented name→node mapping recipe.

### Gate-results checklist template (copy into the gate doc)
```
HACKAGOTCHI GATE RESULTS
Date: __  Operator: __  Host macOS: __  probe-rs: __  openocd: __  picotool: __
Probe fw source/SHA: __  Pico SDK tag: __  Target: spare Pico (rev __)
Locked SWD: SWCLK=GP__ SWDIO=GP__ RESET=GP__ UART=GP0/GP1 OLED I2C=GP6/GP7

GATE 0 — stock probe halts/erases/flashes a target            [ PASS / FAIL ]
  [ ] probe-rs list shows CMSIS-DAP   [ ] info reads IDCODE: __
  [ ] erase 0-error  [ ] download --verify => "Verification successful"
  [ ] openocd verify_image => verified  [ ] reset => LED blinks  [ ] 5/5 clean
  Evidence: gate0/

GATE 1 — fork+SWD-remap+OLED task survives sustained flash      [ PASS / FAIL ]
  Fork base: debugprobe-v2.2.3  Fork SHA: __
  [ ] remapped SWD verified by probe-rs info BEFORE soak
  [ ] OLED task pinned core0, DAP on core1
  [ ] N cycles: __ (bar >=1000)  fails: __  stalls: __  re-verify mismatch: __ (must be 0)
  [ ] OLED counter advanced  [ ] adversarial 50ms-stall fails: __ (must be 0)
  Heap: scheme=heap__ free=__B min-ever-free=__B leak?__ DECISION: heap__
  Evidence: gate1/soak_*.log, heap plot, timelapse

GATE 2 — 2nd CDC: two nodes, DAP binds, JSON round-trip         [ PASS / FAIL ]
  Device class: 0xEF/0x02/0x01 (IAD)  CFG_TUD_CDC=2
  [ ] exactly TWO nodes  [ ] probe-rs list/info still succeed
  [ ] node map by NAME (CDC0=UART, CDC1=Control): __ / __  [ ] stable 3 replug + 1 reboot
  [ ] {"q":"status"} 100/100 valid JSON  [ ] CDC0 carried live UART concurrently
  Evidence: gate2/

OVERALL: [ ] all 3 PASS -> proceed to UI port   [ ] blocked at gate __: __
```

---

## 7. CI/CD (GitHub Actions)

Mirror the existing self-hosted-runner pattern (the MicroPython UF2 flow in PicoInky's `.github/workflows/firmware.yml`).

**One firmware workflow + parallel quality jobs:**
- **`build`** — checkout `submodules: recursive` (pico-sdk, FreeRTOS-Kernel, TinyUSB, `carlk3` FatFs all **pinned git submodules** — that IS the toolchain pin). **Pin Arm GCC** to a specific `arm-none-eabi-gcc` release (same philosophy as the existing MicroPython v1.28.0 + Arm GCC 13.3.Rel1 pin). `cmake -DCMAKE_EXPORT_COMPILE_COMMANDS=ON` → build → upload **`.uf2`** and **`.elf`** as artifacts. ⚠️ Pin the GCC version explicitly — the live yapicoprobe #197 ("cannot read `nosys.specs`" on current Debian GCC) is a concrete example of an *unpinned* GCC breaking an Arm embedded build; pinning is the mitigation.
- **`host-tests`** — Ceedling (Unity/CMock) for parser, ring buffer, wedge detector, log-rotation.
- **`cppcheck`** — our code only (exclude vendored).
- **`clang-tidy`** — curated checks, consumes `compile_commands.json`.
- **`werror-build`** — `-Wall -Wextra -Wshadow -Wconversion -Wundef -Wdouble-promotion -Werror -fanalyzer`.
- **Gate:** merges blocked on all of the above.
- **Release:** on tag → GitHub Release with `.uf2` **and `.elf`** attached (the `.elf` is required to symbolicate fault dumps + RTT). Dispatch-only manual trigger, like the existing firmware workflow.
- **(Later) HIL smoke** on the self-hosted mac-mini: real probe flashes a target, asserts IDCODE — added only after Gates 0–2 pass.

**Delivery status (reconciled with reality as of M1, 2026-06-20):** `build` ✅ and a static-analysis gate
(`analyze.sh`: `-Wall -Wextra -Wshadow -Wundef -Wdouble-promotion -fanalyzer -fsyntax-only` + optional
cppcheck) ✅ are in `.github/workflows/firmware-c.yml`. **Deferred to M2** (CI plumbing, not a missing M1
deliverable): the **`host-tests`** Ceedling job (M1 ships the host test `firmware/c/tests/m1/ring_test.c`
run via `cc` — Ceedling wrapping lands when M2 adds log-rotation/wedge-detector logic), a dedicated
**`clang-tidy`** job, and the full **`werror-build`** (`-Werror -Wconversion`) gate. Tracked in
`docs/TODO.md`; M1's own code builds `-Wall -Wextra`-clean.

---

## 8. Risk register

| # | Risk | Severity | Mitigation | Retired by |
|---|---|---|---|---|
| R1 | **Blocking call on the DAP/USB hot path** (OLED `show()`, SD write, beep, per-byte `strstr`) stalls/corrupts flash | **Critical** | §4.1 priority hierarchy; dashboard task lowest-prio + core-0-pinned; bounded SPSC enqueue on bridge; no slow work on hot path | **Gate 1** (incl. adversarial 50 ms variant) |
| R2 | **Heap fragmentation / exhaustion** under FreeRTOS on 264 KB RP2040 | High | `heap_4` instrumented; jsmn zero-alloc (no JSON DOM); watermark logged | **Gate 1** heap decision (data-driven heap_4 vs heap_1) |
| R3 | **Dual-CDC node identity unstable on macOS** (numeric suffix not stable across reboot/replug) | High | Distinct per-interface USB string descriptors; map name→`IOCalloutDevice` via `ioreg`/`system_profiler` | **Gate 2** (3 replug + 1 reboot stability check) |
| R4 | **SMP flash regression (#189)** ✅ — intermittent, flash-path-only, GDB/halt looks fine | High | Pin **2.2.3** (before commit `457e048`); soak with checksum-per-cycle, not happy-path | **Gate 1** soak (1000 cycles, 0 fails) |
| R5 | **Wrong SWD pin remap** ⚠️ — fails silently as "no IDCODE" | High | Lock `board_hackagotchi_config.h`; validate via `probe-rs info` on the **soldered** header *before* soak | **Gate 1** pre-soak `info` check |
| R6 | **SWD pins physically don't reach / not broken out** on the XIAO expansion header (limited free GPIO; GP2/3/4/28=SD, 6/7=OLED, 0/1=UART) | Med | Lock pin map before soldering; candidate SWCLK=GP26/SWDIO=GP27 (reclaim button); verify broken-out on the expansion header | **Gate 0/1** wiring validation |
| R7 | **yapicoprobe adopted prematurely** → bus-factor-1, unpinned breaking edge (#197 build break live), no umbrella license | Med | Stay on debugprobe 2.2.3; yapicoprobe = Gate-0 A/B reference + design template only; strict §2 trigger to revisit | §2 trigger gating |
| R8 | **License hygiene for a sold product** — SystemView non-commercial; yapicoprobe no umbrella license | Med | Keep SystemView a bring-up tool, OUT of shipping image; if any yapicoprobe code is later vendored, confirm umbrella license + ship NOTICEs; residual stack is BSD-3/MIT/Apache | M5 license pass |
| R9 | **Silent stack overflow** (M0+ has no stack-limit register) | Med | `configCHECK_FOR_STACK_OVERFLOW=2` + hook; fault handler + crash box; SW-watchdog | M1 fault-handling work |
| R10 | **Base drift** — 2.3.x may already fix #189, making 2.2.3 needlessly old | Low | After Gate 1 green on 2.2.3, spike 2.3.1 through the same soak; adopt if it passes | Post-Gate-1 base spike |

---

## 9. Test scripts to write NOW (before hardware exists)

All host-side, hardware-blind (fail cleanly with "no probe found" until wired). Authored so they're ready the instant the SWD header is soldered. Location: `firmware/c/tests/gates/`.

| Script | Purpose |
|---|---|
| `gate0_check.sh` | Runs `probe-rs list/info/erase/download --verify/reset` + `openocd verify_image` against `--chip RP2040`; asserts exit codes; writes `gate0/*.txt`. |
| `gate1_soak.sh` | The probe-rs soak loop above — alternating images, `timeout` wrap, independent re-verify, forensic dump on first fail. |
| `gate1_soak_openocd.sh` | Twin of the soak with the openocd client (different DAP pipelining — varies the client per #189). |
| `heap_plot.py` | Ingests the CDC heap-watermark log; plots free vs min-ever-free (leak/fragmentation visual); degrades to a text summary without matplotlib. |
| `gate2_cdc.py` | Two-node enumeration + JSON round-trip harness; parameterized node paths; `ioreg`/`system_profiler` **name→node** mapping helper. |
| `usb_enum_snapshot.sh` | Wraps `system_profiler SPUSBDataType` + `ioreg -p IOUSB -l` + `ls /dev/cu.usbmodem*` into a timestamped snapshot; run before/after each gate to diff descriptor changes. |
| `fixtures/build_fixtures.sh` | Builds two **distinct** `pico-examples` blink ELFs so `--verify` is a real read-back diff (not a same-image pass that masks a stuck write). Run once toolchain is set up. |
| `pin_toolchain.sh` | Install + record versions of `probe-rs` (`--version`), `openocd`, `picotool`, Arm GCC, Pico SDK tag — embedded in every gate log for reproducibility. |

Also write the **host unit tests** (Ceedling) for the portable logic that has no hardware dependency yet — UART ring buffer, wedge-detector state machine, jsmn JSON-control adapter, log-rotation/session-index — porting the algorithms from the MicroPython firmware behind mockable hardware seams. These run in CI from day one and need no probe.

---

*Generated by a 4-agent research workflow (yapicoprobe verdict · robust-embedded-C reliability stack · gate test strategy → synthesis), with live source re-verification. Re-confirm version/issue facts against the upstream repos at adoption time.*

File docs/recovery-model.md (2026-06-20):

# Hackagotchi — recovery model ("can it brick?")

What actually recovers the probe and a target it's attached to, in what order, and the residual cases
that genuinely *can* brick. Written to be honest about guarantees — the enemy is an over-claim that
gets trusted (the same silent-pass discipline as `mcu-bringup-playbook.md`). Two separate stories that
are easy to conflate: **the XIAO (the probe)** and **the attached target** recover by different means.

> TL;DR: **"unbrickable" is too strong.** But the XIAO is *practically* unrecoverable-proof thanks to
> the RP2040's mask-ROM bootrom (a chip property, not our firmware), and the M1 reliability core makes
> it self-healing + usually reflashable without touching it. A target is recoverable by the probe over
> SWD in the common case — but **not** if its debug port is physically dead or permanently locked.

---

## 1. The real source of resilience: the RP2040 bootrom (not our code)

On every reset the RP2040 runs its **bootrom**, which lives in **mask ROM and cannot be overwritten**.
The bootrom checks the **BOOTSEL** condition *before it branches to any code in flash* — it does first
read + checksum the flash's boot-stage-2 candidate into SRAM (trying the QSPI modes), but BOOTSEL,
sensed on the **QSPI_SS / flash chip-select strap pin**, is evaluated before that second stage is
*executed*:

- BOOTSEL asserted at reset → enter the USB bootloader (USB MSC + PICOBOOT), **regardless of what is
  in flash** — even if flash is blank, corrupt, or full of garbage (flash is read/probed, never run).
- BOOTSEL not asserted → validate + run the flash second-stage; if that's invalid, fall back to USB.

Consequences that matter here:

- **No software — including a bug of ours — can disable the BOOTSEL escape hatch on RP2040.** There is
  no secure-boot / OTP lockout that removes it. (RP2350 adds optional secure boot; RP2040 does not.)
- Holding BOOTSEL while powering up / resetting **always** wins over whatever is in flash. So even a
  tight reboot-loop is recoverable: a reboot-loop is *annoying*, not a brick.
- Flash content can always be mass-erased + rewritten over PICOBOOT, so corrupt flash is recoverable
  as long as the QSPI flash chip is electrically alive.

On the XIAO RP2040 the BOOTSEL gesture is: **hold B, tap R, release B**. (macOS sometimes does not
auto-mount the `RPI-RP2` volume; that's cosmetic — `picotool` still reaches the device over PICOBOOT,
which is all a reflash needs.)
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

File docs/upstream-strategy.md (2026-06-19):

# Hackagotchi — Upstream Strategy

How we relate to the two upstream projects: **debugprobe** (our base) and **yapicoprobe**
(a feature donor we also intend to contribute to). Companion to `c-firmware-analysis.md` §2 and
`engineering-plan.md` §2.

---

## 1. debugprobe — our base: track official stable, diverge minimally

**Policy: base on the official `raspberrypi/debugprobe`, track STABLE TAGS only (never `master`),
and keep our delta small enough that rebasing onto a new stable tag is cheap.**
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

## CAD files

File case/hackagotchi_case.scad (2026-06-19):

// hackagotchi_case.scad — minimal pocket case for Hackagotchi (Seeed XIAO RP2040 + Expansion Board:
// 128x64 OLED, microSD, PCF8563 RTC + CR1220, buzzer, user button). A "field recorder" form:
// a soft pebble with a gently CANTED top so the OLED tilts toward you on a desk, a tapering
// PROBE SNOUT where the UART-tap leads exit, and a LANYARD eyelet for pocket carry. Snap-fit
// clamshell, no visible screws.
//
//   openscad -D 'part="base"'   -o case/pt_base.stl   case/hackagotchi_case.scad
//   openscad -D 'part="top"'    -o case/pt_top.stl    case/hackagotchi_case.scad
//   openscad -D 'part="coupon"' -o case/pt_coupon.stl case/hackagotchi_case.scad   // fit test
//   openscad -D 'part="all"'    -o case/pt_preview.stl case/hackagotchi_case.scad  // preview only
//
// v1 (2026-06-19) — authored from datasheets; board outline + component positions are [MEASURE].
// The FORM is the deliverable; confirm cutout positions with calipers and print the coupon first.

part = "all";          // "base" | "top" | "coupon" | "all"
$fn = 80;
eps = 0.02;

/* ===== board (Seeed XIAO Expansion Base) — [MEASURE] all of these ===== */
brd_l   = 72.0;        // expansion board length [MEASURE]
brd_w   = 30.0;        // expansion board width  [MEASURE]
brd_t   = 1.2;         // PCB thickness
comp_h  = 9.0;         // tallest topside component clearance (OLED module / RTC holder) [MEASURE]
under_h = 2.5;         // underside clearance (XIAO + solder) below the PCB [MEASURE]

// component positions, board-centred coords (X along length, Y along width) — [MEASURE].
// -X = OLED end = HIGH end of the cant (tall enough for the 9mm OLED module).
// +X = XIAO end = LOW end -> USB-C + UART-tap leads exit here through the snout.
oled_pos = [-17.0, 0]; // OLED active-area centre (on the high end)
oled_w   = 22.0;       // OLED active width  (window = active + frame reveal)
oled_h   = 11.5;       // OLED active height
btn_pos  = [4.0, -9.0];// user button centre
sd_edge_y= +1;         // microSD slot on the +Y long edge; -1 for -Y
sd_pos_x = -6.0;       // microSD slot centre along X
buzz_pos = [6.0, 9.0]; // buzzer (grille goes over this)

/* ===== shell / fit ===== */
wall     = 2.0;        // side wall thickness
floor_t  = 1.6;        // base floor thickness
roof_t   = 1.8;        // top roof thickness (over the OLED visor frame)
corner_r = 5.0;        // generous pebble corner radius
fit      = 0.4;        // board edge -> inner wall clearance, per side
h_front  = 14.0;       // outer height at the front (USB-C/OLED-near) edge
h_back   = 19.0;       // outer height at the back edge -> the cant that tilts the OLED up
split_z  = 7.0;        // base/top split height above the bottom (snap seam)
lip_h    = 3.0;        // snap-lip overlap depth at the seam
lip_clr  = 0.18;       // snap-lip clearance per side (raise if too tight)

/* ===== features ===== */
frame    = 1.2;        // OLED window frame reveal beyond the active area, per side
btn_bore = 4.0;        // button access hole
usbc_w   = 9.6; usbc_h = 3.6;     // USB-C cutout
sd_w     = 12.5; sd_h  = 2.2;     // microSD slot cutout
snout_w  = 12.0;       // probe-snout width (tap leads GP0/GP1/GND exit here, +X end)
snout_d  = 7.0;        // how far the snout necks out past the body
tap_slot = 5.0;        // tap-lead exit slot height/width
eyelet_d = 5.0;        // lanyard eyelet outer loop
eyelet_hole = 2.6;     // lanyard hole

/* ===== derived ===== */
cav_l   = brd_l + 2*fit;
cav_w   = brd_w + 2*fit;
outer_l = cav_l + 2*wall;
outer_w = cav_w + 2*wall;
tilt    = atan2(h_back - h_front, outer_l);   // top-face cant angle
board_z = floor_t + under_h;                   // PCB underside height in the base

module rrect(w, h, r) offset(r=r) square([max(0.1,w - 2*r), max(0.1,h - 2*r)], center=true);
module rbox(w, h, t, r) linear_extrude(height=t) rrect(w, h, r);

/* ---- the full outer pebble: a rounded prism with a canted (wedged) top ---- */
module shell_outer() {
  intersection() {
    rbox(outer_l, outer_w, h_back + 10, corner_r);
    // half-space below the cant plane (higher at -X/back, lower at +X/front)
    translate([0, 0, (h_front + h_back)/2])
      rotate([0, tilt, 0])
        translate([0, 0, -100]) cube([800, 800, 200], center=true);
  }
}

/* ---- hollow inner volume (shell_outer shrunk by wall/floor/roof) ---- */
module shell_inner() {
  intersection() {
    translate([0, 0, floor_t])
      rbox(outer_l - 2*wall, outer_w - 2*wall, h_back + 10, max(0.6, corner_r - wall));
    translate([0, 0, (h_front + h_back)/2 - roof_t/cos(tilt)])
      rotate([0, tilt, 0])
        translate([0, 0, -100]) cube([800, 800, 200], center=true);
  }
}

/* ---- probe snout: a rounded cable-boot on the +X end, centred on the USB-C/tap exit ---- */
module snout() {
  translate([outer_l/2 - 1, 0, board_z + 1.0])
    hull() {
      rotate([90, 0, 0]) cylinder(h = snout_w, d = usbc_h + 5, center = true, $fn = 48);
      translate([snout_d, 0, 0])
        rotate([90, 0, 0]) cylinder(h = snout_w * 0.7, d = usbc_h + 2.5, center = true, $fn = 48);
    }
}

/* ---- lanyard eyelet: a loop off the -X/back top corner ---- */
module eyelet() {
  translate([-outer_l/2 - eyelet_d*0.4, outer_w/2 - eyelet_d, h_back - eyelet_d/2 - 1])
    rotate([90, 0, 0])
      difference() {
        cylinder(h = 3.2, d = eyelet_d + 3, center = true);
        cylinder(h = 4, d = eyelet_hole, center = true);
      }
}

/* ---- board-locating posts in the base (corner cradles) ---- */
module board_posts() {
  for (sx = [-1, 1]) for (sy = [-1, 1])
    translate([sx*(cav_l/2 - 1.6), sy*(cav_w/2 - 1.6), floor_t]) {
      linear_extrude(under_h) square([3.2, 3.2], center=true);      // PCB rest pillar
      translate([0,0,under_h]) linear_extrude(brd_t + 1.2)          // edge-capture lip
        square([3.2, 3.2], center=true);
    }
}

/* ---- top cutouts: OLED window, button, buzzer grille (cut through the roof) ---- */
module top_cuts() {
  // OLED window — projected straight up through the canted roof
  translate([oled_pos[0], oled_pos[1], 0])
    rbox(oled_w + 2*frame, oled_h + 2*frame, h_back + 5, 1.6);
  // button bore
  translate([btn_pos[0], btn_pos[1], 0]) cylinder(h = h_back + 5, d = btn_bore);
  // buzzer grille — a small 3x3 hole array
  for (i = [-1:1]) for (j = [-1:1])
    translate([buzz_pos[0] + i*3.2, buzz_pos[1] + j*3.2, 0]) cylinder(h = h_back + 5, d = 1.4);
}

/* ---- edge cutouts: combined USB-C + tap exit through the +X snout, microSD on a long edge ---- */
module edge_cuts() {
  // One generous opening through the +X snout for the XIAO USB-C AND the UART-tap leads
  // (both originate at the XIAO end). A single cable boot rather than two fragile slots.
  translate([outer_l/2 + snout_d/2, 0, board_z + 1.5])
    hull() {
      cube([snout_d + wall + 2, usbc_w, usbc_h], center=true);                 // USB-C window
      translate([0, 0, -1.5]) cube([snout_d + wall + 2, usbc_w + 4, tap_slot], center=true); // lead exit
    }
  // microSD on a long edge
  translate([sd_pos_x, sd_edge_y*(outer_w/2), board_z + 0.5])
    rotate([90,0,0]) cube([sd_w, sd_h, 3*wall], center=true);
}

/* ---- assemblies ---- */
module body_solid() { union() { shell_outer(); snout(); eyelet(); } }

module base() {
  difference() {
    union() {
      intersection() { body_solid(); translate([0,0,-eps]) rbox(outer_l+40, outer_w+40, split_z+eps, 0.1); }
      board_posts();
    }
    // hollow + seam recess for the top's lip + edge cuts
    shell_inner();
    translate([0,0,split_z - lip_h])
      difference() {
        rbox(outer_l - 2*wall + 2*lip_clr + 2, outer_w - 2*wall + 2*lip_clr + 2, lip_h + eps, corner_r);
        rbox(outer_l - 2*wall - 2*lip_clr, outer_w - 2*wall - 2*lip_clr, lip_h + 4*eps, max(0.6,corner_r-wall));
      }
    edge_cuts();
  }
}

module top() {
  difference() {
    union() {
      intersection() { body_solid(); translate([0,0,split_z]) rbox(outer_l+40, outer_w+40, h_back+10, 0.1); }
      // inward snap lip that drops into the base recess
      translate([0,0,split_z - lip_h])
        difference() {
          rbox(outer_l - 2*wall + 2*lip_clr, outer_w - 2*wall + 2*lip_clr, lip_h, max(0.6,corner_r-wall));
          translate([0,0,-eps]) rbox(outer_l - 2*wall - 2*lip_clr - 2, outer_w - 2*wall - 2*lip_clr - 2, lip_h+2*eps, max(0.6,corner_r-wall));
        }
    }
    shell_inner();
    top_cuts();
    edge_cuts();
  }
}

/* ---- coupon: the snout end of the base+top for a fast seam/fit test ---- */
module coupon() {
  intersection() {
    union() { base(); top(); }
    translate([outer_l/2 - 8, 0, (h_back)/2]) cube([24, outer_w+2, h_back+10], center=true);
  }
}

/* ---- dispatch ---- */
if (part == "base") base();
else if (part == "top") top();
else if (part == "coupon") coupon();
else {                                   // "all": exploded preview
  base();
  color("white") translate([0, 0, h_back + 8]) top();
}

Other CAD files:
case/pockettap_case.scad

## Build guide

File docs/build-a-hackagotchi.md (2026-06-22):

# Build a Hackagotchi

How to assemble, wire, flash, and first-boot a Hackagotchi from parts. This is the **physical
reproducibility** guide; the toolchain-level firmware build lives in
[`c-firmware-build.md`](c-firmware-build.md) and [`../firmware/c/README.md`](../firmware/c/README.md),
and the host tooling in [`../host/README.md`](../host/README.md).

> Hackagotchi runs three roles from one image on a single XIAO RP2040: a CMSIS-DAP SWD debug probe,
> a UART-to-microSD black-box recorder, and a reactive OLED dashboard. The hardware is almost
> entirely a stock **Seeed XIAO RP2040 + XIAO Expansion Board** — the expansion board already carries
> the OLED, microSD slot, and buzzer, so the BOM is short.

## Bill of materials

Approximate costs are USD, ballpark as of 2026 — check the store for current pricing. Quantities are
per unit.

| # | Part | Qty | ~Cost | Where | Notes |
|---|---|-----|---|---|---|
| 1 | **Seeed XIAO RP2040** | 1 | ~$5–6 | [wiki.seeedstudio.com/XIAO-RP2040](https://wiki.seeedstudio.com/XIAO-RP2040/) | the MCU. Has an **onboard WS2812 NeoPixel** (GP12 data / GP11 power) + onboard LED (GP25) the firmware uses |
| 2 | **Seeed Studio XIAO Expansion Board Base** | 1 | ~$11–14 | [wiki.seeedstudio.com/Seeeduino-XIAO-Expansion-Board](https://wiki.seeedstudio.com/Seeeduino-XIAO-Expansion-Board/) | carries the **0.96″ 128×64 SSD1306 OLED** (I2C @ 0x3C), **microSD slot** (SPI), **passive buzzer** (GP29), a user button (GP27 — **unusable**, see reconciliation), and a PCF8563 RTC + CR1220 holder (**unused**, see reconciliation) |
| 3 | **microSD card**, FAT32 | 1 | ~$5–8 | any | the black-box log store. Tested on a 16 GB FAT32 card; format FAT32 before first use |
| 4 | **Dupont / jumper leads** | ~5 | ~$2 | any | to a target board: SWCLK/SWDIO + GND (debug) and the UART tap GP0/GP1 + GND |
| 5 | **USB-C cable** | 1 | ~$3 | any | data-capable (powers + enumerates the composite USB device) |
| 6 | **Filament**, PETG or PLA | ~10 g | ~$1 | any | for the printed case ([`../case/`](../case/)) — 0.4 mm nozzle, 0.2 mm layers |
| 7 | *(for testing)* a separate **RP2040 target** | 1 | ~$4–5 | any | e.g. a Pico/Pico W to debug + record. Not part of the shipped unit |

**Rough total (the unit itself, parts 1–6): ~$27–34.**

The expansion board is the lever that keeps this cheap: OLED + microSD + buzzer come pre-mounted and
pre-wired to the XIAO's pads, so there is no peripheral soldering for the core build — just stack,
insert the card, and wire the two taps to whatever you're debugging.

## Consolidated pin map (as-built)

Every pin is fixed in firmware — `firmware/c/boards/board_hackagotchi_config.h` (probe/UART),
`firmware/c/src/sd/hw_config.c` (SD), `firmware/c/src/i2c1_bus.h` (OLED), and
`firmware/c/src/feedback.c` (buzzer/NeoPixel). The XIAO pad name (D0…D10) is what's silk-screened.

| Signal | GPIO | XIAO pad | Bus / role | Notes |
|---|---|---|---|---|
| **SWCLK** | GP26 | D0 | PIO0 SWD (probe out) | reclaims the D0 green-LED/ADC pad |
| **SWDIO** | GP27 | D1 | PIO0 SWD (probe I/O) | reclaims the user-button pad. **SWDIO must equal SWCLK+1** (PIO side-set adjacency) — that's why GP26/GP27 |
| **UART0 TX** | GP0 | D6 | target-UART tap → target RX | the recorder/bridge's view of the target console |
| **UART0 RX** | GP1 | D7 | target-UART tap ← target TX | |
| **SD SCK** | GP2 | D8 | SPI0 (FatFs) | 12 MHz |
| **SD MOSI** | GP3 | D10 | SPI0 | |
| **SD MISO** | GP4 | D9 | SPI0 | |
| **SD CS** | GP28 | D2 | SPI0, software SS | GP28 isn't an SPI0 HW pin, but CS is a plain GPIO so it's fine |
| **I2C1 SDA** | GP6 | D4 | OLED SSD1306 @ 0x3C | **OLED is the sole device** (RTC dropped); FM+ **1 MHz**, single-owner, no mutex |
| **I2C1 SCL** | GP7 | D5 | OLED SSD1306 | |
| **Buzzer** | GP29 | D3 | PWM | passive piezo |
| **NeoPixel data** | GP12 | onboard | WS2812 via **pio1** | the color status indicator (wedge = red, recovery = green). pio1 deliberately — pio0 is the SWD probe |
| **NeoPixel power** | GP11 | onboard | power-enable (drive HIGH) | the XIAO gates NeoPixel power on this pin |
| **Onboard LED** | GP25 | onboard | USB heartbeat | active-low; no pad |
| ~~Onboard RGB~~ | ~~GP16/17~~ | onboard | **unused** | abandoned as an unreliable status channel (firmware Finding M3-1) — the WS2812 is the status LED |

**Do not press the user button during a flash.** GP27 is now SWDIO; a debounce cap on that line can
break SWD at 1 MHz. The Gate-1 pre-soak check `probe-rs info --chip RP2040 --protocol swd` is the
arbiter that the soldered/stacked SWD path is sound before you trust a soak.

## As-shipped vs. the case docs — reconciliation

⚠️ The enclosure docs ([`../case/HACKAGOTCHI_CASE.md`](../case/HACKAGOTCHI_CASE.md),
[`../case/CAT_ENCLOSURE_SPEC.md`](../case/CAT_ENCLOSURE_SPEC.md)) and `hackagotchi_case.scad` were
written against an **earlier hardware intent** and have drifted from the as-built firmware. Until the
case is revised, reconcile as follows:

| Case docs say… | As-built firmware | What to do |
|---|---|---|
| Enclose a **PCF8563 RTC + CR1220 coin cell** | RTC **dropped** (commit `eca0f03`): `rtc_read = NULL`, logs carry **uptime `+Ns`** stamps, no `time`/`settime` verbs, I2C1 runs OLED-only at FM+ 1 MHz | No coin cell needed for operation. The RTC chip is still on the expansion board but the firmware never reads it — don't design the case around coin-cell access. There is **no wall-clock**; log timestamps are uptime-relative |
| A **recessed user button** as a "cheek" tap-target | GP27 is **SWDIO** — the button is electrically sacrificed and **unusable** (pressing it can break SWD) | Treat the button as decorative-only, or blank the cutout. All interaction is over USB (CDC1) — there is no physical button. `pet`/`summon`/`exorcise` etc. are CDC1 verbs |
| (no mention of a status light) | Firmware drives the **onboard WS2812 NeoPixel** (GP12/GP11) as the primary color-status channel | The `.scad` has **no light-pipe / cutout** for the NeoPixel, so the status color is invisible in an opaque case. Add a diffuser/cutout over the XIAO's onboard NeoPixel, or accept a blind status LED |
| OLED "face", buzzer "muzzle" grille, canted top | Consistent — OLED on GP6/7 @ 0x3C, buzzer on GP29 | No change. The cat-face/OLED and buzzer-grille mappings still hold |

The case files are also explicitly **v1 "form, not fit"** — every board outline and component
position is a `[MEASURE]` placeholder. Measure your stacked board with calipers and set the `.scad`
parameters before a full print; print the `coupon` first.

## Assembly

1. **Stack** the XIAO RP2040 onto the XIAO Expansion Board (USB-C end matching the board's USB-C
   cutout). This connects the OLED, microSD, and buzzer to the pads in the map above — no soldering.
2. **Format and insert** a FAT32 microSD card into the expansion board's slot (this is the black-box
   log store; with no card the recorder degrades gracefully and the SD glyph shows unmounted).
3. **Wire the debug + tap leads** to your target board:
   - SWD: XIAO **GP26 → target SWCLK**, **GP27 → target SWDIO**, **GND → GND**.
   - UART tap (optional but it's the recorder's whole point): XIAO **GP0 (TX) → target RX**,
     **GP1 (RX) → target TX**, **GND → GND**.
4. **Print the case** from [`../case/`](../case/) — render the STLs with the OpenSCAD commands in
   `HACKAGOTCHI_CASE.md`, print the `coupon` first to check the snap-fit seam and cable opening, then
   the base + top. Apply the reconciliation notes above (button cutout, NeoPixel diffuser).
5. **USB-C** from the XIAO to your host. The device enumerates as a composite USB device: two CDC
   serial ports (bridge + control) and the CMSIS-DAP probe.

## Build & flash the firmware

Full toolchain detail is in [`c-firmware-build.md`](c-firmware-build.md); the short path (all from
`firmware/c/`, pinned Arm GCC 13.3 + pico-sdk 2.2.0):

```bash
cd firmware/c
./setup.sh                                          # fetch pinned upstream (gitignored)
VERSION=$(git describe --tags --always) ./build_fork.sh   # -> build/hackagotchi_probe.uf2
./analyze.sh                                         # static-analysis gate (must pass)
```

Flash it:

- **First time / recovery:** hold nothing — there is no BOOTSEL button (GP27 is SWDIO). Put a *bare*
  XIAO into BOOTSEL via its onboard reset before first flash, then:
  `picotool load -x build/hackagotchi_probe.uf2`.
- **Reflash a running unit, hands-free:** send `{"q":"bootsel"}` on the control port (CDC1) — the
  firmware resets to BOOTSEL with no button — then `picotool load -x …`. The host CLI wraps this:
  `.venv/bin/python host/hackagotchi_ctl.py bootsel`. See [`recovery-model.md`](recovery-model.md).

## First-contact verification

Set up the host tooling once (`./setup-venv.sh` from the repo root — see
[`../host/README.md`](../host/README.md)), then:

```bash
.venv/bin/python host/hackagotchi_ctl.py status     # should answer fw=Hackagotchi, ver=…
.venv/bin/python host/hackagotchi_ctl.py sd          # SD mount/bring-up status
.venv/bin/python host/hackagotchi_ctl.py screen 0    # the OLED should show the cat / home screen
```

If `status` answers with `"fw":"Hackagotchi"`, the composite USB device, the control channel, and
the firmware are all alive. The OLED lighting up and `sd` reporting a mounted card confirm the two
expansion-board peripherals are seated. To prove the **probe** path, point `probe-rs` or `openocd` at
a wired target (`probe-rs info --chip RP2040 --protocol swd`).

## References

- [`c-firmware-build.md`](c-firmware-build.md) — toolchain, pinned versions, build flags
- [`../firmware/c/README.md`](../firmware/c/README.md) — firmware overview + CDC1 command table
- [`../host/README.md`](../host/README.md) — host CLI + the two-CDC port model
- [`recovery-model.md`](recovery-model.md) — bootsel / recovery guarantees
- [`release-readiness.md`](release-readiness.md) — what's HIL-attested on the release image
- [`../case/`](../case/) — enclosure source + print instructions

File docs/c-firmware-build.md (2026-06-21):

# Hackagotchi C probe firmware — build, flash, analyze

The C firmware (`firmware/c/`) is a **fork of `raspberrypi/debugprobe` @ `debugprobe-v2.2.3`** for the
Seeed XIAO RP2040: one image that is both an SWD debug probe (CMSIS-DAP) and the Hackagotchi OLED
dashboard / UART black-box recorder. See `docs/engineering-plan.md` for the *why*; this is the *how*.

## Fork model (overlay, not a vendored copy)

`upstream/debugprobe/` is **fetched on demand** by `setup.sh` and is gitignored — it is never committed.
Our changes live in `firmware/c/` and are compiled *instead of* the matching upstream files:

| Our file | Replaces / shadows | Why |
|---|---|---|
| `boards/board_hackagotchi_config.h` | (the real pin map) | SWD/UART/LED pins for the XIAO |
| `boards/board_debug_probe_config.h` | upstream `include/board_debug_probe_config.h` | **shim** → includes the Hackagotchi config; the only no-edit way to inject the board (the C quote-include adjacency rule defeats a `probe_config.h` overlay — see the shim's header comment) |
| `src/main.c` | upstream `src/main.c` | + the low-priority OLED coexistence task |
| `src/hackagotchi_dashboard.c` | (new) | the OLED task (Gate 1) |
| `src/usb_descriptors.c` | upstream `src/usb_descriptors.c` | 2nd CDC + IAD composite (Gate 2) |
| `src/cdc_uart.c` | upstream `src/cdc_uart.c` | `itf`-guard the CDC class callbacks (Gate 2) |
| `src/cdc1_control.c` | (new) | CDC1 JSON control handler (Gate 2) |
| `src/tusb_config.h` | upstream `src/tusb_config.h` | `CFG_TUD_CDC` 1 → 2 |
| `src/ssd1306/` | (vendored, MIT) | `daschr/pico-ssd1306` OLED driver |

`CMakeLists.txt` lists our files first and puts `src/` + `boards/` first on the include path. When
bumping the upstream base, diff each overlay file against the new upstream version.

## Pin map (XIAO RP2040 + Seeed expansion)

| Function | Pins |
|---|---|
| SWD (locked) | **SWCLK=GP26 (D0), SWDIO=GP27 (D1)** — adjacent, SWDIO=SWCLK+1 (PIO requirement); reclaims D0 LED/ADC + D1 button |
| UART tap (bridge) | GP0 TX / GP1 RX (uart0) |
| OLED | I2C1 SDA=GP6 / SCL=GP7 (OLED @0x3C, FM+ 1 MHz, single-owner — the PCF8563 RTC was dropped) |
| microSD — SPI0 (black box) | SCK=GP2 / MOSI=GP3 / MISO=GP4 / CS=GP28 |
| Buzzer (PWM) | GP29 |
| WS2812 NeoPixel (status) | data=GP12 / power=GP11 |
| USB heartbeat LED | GP25 (onboard blue) |

## Prerequisites (already on the build machine / self-hosted runner)

- **Pinned Arm GCC 13.3.Rel1** at `…/fw-build/arm-gnu-toolchain-13.3.rel1-darwin-arm64-arm-none-eabi`
  (NOT the host's system GCC). Override with `GCC_DIR=`.
- **pico-sdk 2.2.0** at `…/fw-build/micropython/lib/pico-sdk` (override with `PICO_SDK_PATH=`).
  `build_fork.sh` auto-inits its `lib/tinyusb` submodule (MicroPython leaves it empty).
- `cmake` ≥ 3.13, `picotool` 2.x. Optional: `cppcheck` (`brew install cppcheck`) for the 2nd analyzer.

## Build

```bash
cd firmware/c
./setup.sh                      # clone debugprobe-v2.2.3 (+ FreeRTOS) into upstream/ (gitignored)
VERSION=1.0.0 ./build_fork.sh   # -> build/hackagotchi_probe.uf2 (+ .elf); VERSION is compiled in + reported by {"q":"status"} "ver"
```

Gate-test variants (separate images; don't overwrite the product `build/` — use `BUILD_DIR=`):

```bash
ADVERSARIAL_STALL_MS=50 BUILD_DIR=/tmp/adv ./build_fork.sh                       # 50ms stall in the OLED task
ADVERSARIAL_STALL_MS=50 ADVERSARIAL_AT_DAP_PRIO=ON BUILD_DIR=/tmp/adv2 ./build_fork.sh  # + at DAP priority (contention)
```

Confirm the build is the intended image before flashing:

```bash
picotool info -a build/hackagotchi_probe.uf2          # SWCLK=GP26/SWDIO=GP27, "Hackagotchi Probe"
nm build/hackagotchi_probe.elf | grep tud_cdc_rx_cb   # present => Gate-2 (2-CDC) image
strings build/hackagotchi_probe.elf | grep 'Hackagotchi Control'
```

## Flash

The XIAO is the probe; reflashing it needs **USB BOOTSEL** — either the button gesture below, or
`{"q":"bootsel"}` over CDC1 (a software reset-to-bootloader, `reset_usb_boot`) for a hands-free reflash:

```bash
# Put the XIAO in BOOTSEL: hold B, tap R, release B  ->  RPI-RP2 mounts
picotool load -x build/hackagotchi_probe.uf2          # -x = run after load
```

Device-local files (none required for the probe itself yet).

## Static-analysis gate (reliability)

```bash
./build_fork.sh && ./analyze.sh    # GCC -fanalyzer + strict warnings (+ cppcheck) on OUR code only
```

FAILs on any `-Wanalyzer-*` finding, or any warning in the genuinely-new files
(`hackagotchi_dashboard.c`, `cdc1_control.c`); upstream-inherited style warnings in the overlay copies
are report-only. CI runs this as a gate (`.github/workflows/firmware-c.yml`).

## Gates

Hardware-in-the-loop validation lives in `firmware/c/tests/gates/` with results in
`tests/gates/GATE_RESULTS.md`. **Gate 0** (probe flashes a target), **Gate 1** (OLED task survives a
sustained flash soak, 0 stalls — at-DAP-priority contention closed), and **Gate 2** (2nd CDC: 2 nodes,
DAP binds, 100/100 JSON round-trip) all **PASS**. Milestones M1–M4 (reliability core, SD black box,
dashboard, full tool UI) are HIL-verified; per-milestone results are under `tests/m1`…`tests/m4`, and
the release-image attestation (CI-automated vs HIL-attested) is consolidated in
[`release-readiness.md`](release-readiness.md). The HIL gates cannot run in CI — only the build +
`analyze.sh` static-analysis gate do.

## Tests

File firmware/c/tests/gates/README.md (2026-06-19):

# Hackagotchi gate harness

Host-side scripts to run the three go/no-go gates from `docs/engineering-plan.md` §6. They
**de-risk the one uncertain thing** — SWD ⇄ dashboard concurrency — before any UI is ported.

All scripts are **hardware-blind-safe**: with no probe wired they exit cleanly with a clear
message (exit code 2 = "can't run yet", 0 = pass, 1 = fail). So they're ready to run the moment
the SWD header is soldered.

## Order

| Gate | Script | Needs |
|---|---|---|
| pre | `pin_toolchain.sh` | nothing — records tool versions into every gate log |
| pre | `usb_enum_snapshot.sh` | nothing — snapshot USB before/after to diff descriptors |
| 0 | `gate0_check.sh [elf]` | bare XIAO w/ **stock** debugprobe.uf2, wired to a spare Pico target |
| 1 | `gate1_soak.sh [N]` + `gate1_soak_openocd.sh [N]` | the **fork** + remapped SWD + 1 OLED task; soak ≥1000 cycles |
| 1 | `heap_plot.py <log>` | the CDC heap-watermark capture from the soak |
| 2 | `gate2_cdc.py` | the fork + 2nd CDC built |

`fixtures/build_fixtures.sh` builds the two distinct blink ELFs the soak needs (run once the
Pico SDK + Arm GCC are set up — see `../../setup.sh`).

## Hardware

- **Probe** = the Hackagotchi XIAO. Gate 0 uses a **bare** XIAO (stock GP2/GP3 SWD free); Gate 1+
  use the soldered, remapped SWD header (`../../boards/board_hackagotchi_config.h`).
- **Target** = a separate spare **Raspberry Pi Pico** (plain RP2040). Powered by its own USB.
- **Wiring** = Probe SWCLK→Target SWCLK, SWDIO→SWDIO, **GND→GND** (mandatory). Optional RESET→RUN.

## Recording results

Copy `GATE_RESULTS.md` per attempt and fill it in. Evidence lands in `gate0/ gate1/ gate2/`
(gitignored — they're per-run artifacts).

> ⚠️ Before trusting Gate 1, validate the **soldered** SWD pins with
> `probe-rs info --chip RP2040 --protocol swd` — a wrong pin fails silently as "no IDCODE".

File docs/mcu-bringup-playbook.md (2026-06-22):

# MCU bring-up playbook — proving firmware on real hardware before you build on it

A repeatable method for bringing up firmware on any microcontroller product, distilled from the
Hackagotchi C debugprobe fork (and applicable to PicoInky, the XIAO bridge, and whatever comes next).
The core idea, the firmware sibling of `case-design-playbook.md`: **never trust a source edit, a green
exit code, or your own eyeballs — prove each claim against the artifact and against a test you have
watched fail.** The expensive bugs here are not crashes; they are *silent passes* — a soak that counts
nothing, an overlay that never compiled in, a verifier that exits 0 on a real mismatch.

This is the workflow that took Hackagotchi through Gate 0 → Gate 1 → Gate 2. Follow it for every new
firmware product. See `docs/engineering-plan.md` for the *why* of this product; this is the portable
*how*.

---

## 0. Gates-first — the central discipline

Before porting a single screen of UI, prove the **hard, falsifiable architectural questions** on real
hardware as a short series of *gates*. A gate is a yes/no claim that, if false, kills or reshapes the
plan — so you want to find out cheaply and early.

Hackagotchi's three gates (the pattern, not the specifics):
- **Gate 0 — can the substrate do the core job at all?** (stock probe halts/erases/flashes a target.)
- **Gate 1 — does the risky coexistence hold?** (the dashboard task survives a sustained flash soak
  without starving the probe.)
- **Gate 2 — does the composite grow cleanly?** (add the 2nd USB CDC; DAP still binds, JSON round-trips.)

Rules:
- **No feature work until the gates pass.** The temptation is always to build the pretty part first;
  resist it. The gate answers the question that, unanswered, makes the pretty part worthless.
- **Each gate is one falsifiable claim** with a quantified bar and a *machine-checked* verdict.
- **Order gates by risk, not by ease.** The thing most likely to be false goes first.
- **A gate that only tests the easy configuration is not passed** — see §3 (the weak-stressor trap).

---

## 1. The hierarchy of truth (firmware edition)

When you assert "the build has pin X / the probe still binds / the OLED is alive," rank your evidence
and always reach for the highest you can get. Trusting a lower rank is how silent passes happen.

| Rank | Evidence | Proves | Notes |
|---|---|---|---|
| 1 | **The running hardware, machine-observed** | the actual behaviour | the gold standard; a script reads a counter / round-trips JSON / reads IDCODE |
| 2 | **The built binary, decoded** (`picotool info`, `nm`, `strings`, descriptor-from-ELF) | what actually compiled in | catches source-edit-didn't-reach-binary (F1-2); cheap, do this every build |
| 3 | **A second independent tool agrees** (openocd *and* probe-rs; cppcheck *and* -fanalyzer) | not a single-tool artifact | each tool lies differently; agreement is strong |
| 4 | **The build log** (text size, "copy_to_ram", 0 warnings) | it compiled & linked | necessary, not sufficient — it links fine and still does the wrong thing |
| 5 | **Operator eyeball** ("the OLED looked fine") | a human saw it once | last resort; a known soft spot — replace with rank-1 capture asap |
| 6 | **The source diff** ("I changed the pin to GP26") | your intent | proves *nothing* about the artifact (F1-2). Never the final word. |

The Hackagotchi findings are all rank-collapse stories: F1-2 trusted rank 6 (the edit had no effect);
the original soak trusted rank 4 (exit code) when rank 1 (stdout) said mismatch; the OLED claim still
rests on rank 5 and is explicitly flagged for rank-1 capture.

---

## 2. Anatomy of a gate

Write every gate down with these six parts (the `firmware-gate` skill scaffolds them; results live in
`tests/gates/GATE_RESULTS.md`):

1. **The falsifiable claim** — one sentence, stated so a failure is unambiguous. *"The OLED coexistence
   task survives ≥1000 consecutive target flashes with 0 probe failures."*
2. **The minimal rig** — exact wiring (pins, which board is probe vs target), firmware under test, and
   its provenance (how do you *know* the DUT is running your build, not the stock one — see §4).
3. **The quantified bar** — N clean cycles, a latency ceiling, "exactly 2 nodes." A number, not "works."
4. **The machine assertion** — a script that decides PASS/FAIL by reading the *right* signal (stdout
   content, a monotonic counter, a JSON field), **never** a human glance and **never** the exit code
   alone (§5). It must be able to emit FAIL.
5. **The adversarial variant** — a build that *should* stress the claim to its breaking point (§3). If
   the stressor can't actually hurt the system, the gate is decorative.
6. **The verdict** — PASS / FAIL / PASS-WITH-BLOCKERS, with evidence paths and every deferred item
   named. "PASS (core claim; X deferred)" is honest; a bare "PASS" that hides a deferred hard test is not.

---

## 3. The weak-stressor trap (volume ≠ strength)

The most seductive failure of a soak is **a huge clean number from a test that could never fail.**

Hackagotchi Gate 1: the OLED task ran at `tskIDLE_PRIORITY`, so DAP preempts it in ~50 µs — it is
*provably incapable* of starving the probe. 5200 clean cycles of that is 5200 cycles of a tautology
("a task that can't interfere doesn't interfere"). The informative test is the **at-DAP-priority**
variant under genuine contention — that one was built and compile-verified but deferred, so the thesis
is *not yet proven under load* despite the impressive cycle count.

Discipline:
- **Identify the worst case the real product will hit** (here: a dashboard doing blocking 23 ms I2C and
  later SD writes, on one core, at or near DAP's priority) and make the adversarial build reproduce it.
- **A stressor you can't make fail is not a stressor.** Before trusting a soak, ask: *what configuration
  would make this gate fail, and have I run it?* If the answer is "I haven't run the one that could
  fail," the gate is open.
- **Report the stressor's strength, not just the count.** "5200 cycles, idle-priority (weak) stressor"
  is honest; "5200 cycles, 0 fails" oversells.

---

## 4. Provenance — prove the DUT runs *your* build

A gate is meaningless if you're testing the stock firmware by accident. Establish provenance every run:
- **Don't rely on serial numbers.** The CMSIS-DAP serial on RP2040 is the flash unique-id — *identical*
  for the stock probe and your fork. It does not discriminate firmware.
- **Use a discriminating artifact:** a product string you set (`picotool info` → "Hackagotchi Probe"),
  your remapped pin map (GP26/27, not stock GP12/13/14), a symbol only your build has
  (`nm … | grep tud_cdc_rx_cb`), a string only your build has (`strings … | grep 'Hackagotchi Control'`).
- **Tee the provenance into the log.** The soak scripts run `probe-rs info` (reads the remapped pins) as
  a banner at the top of every log, so the evidence is inseparable from the result.
- **The byte-identical-builds trap (learned 2026-06-20).** When two builds differ ONLY in behaviour that
  nothing captured records — e.g. a stock build vs an adversarial variant that just changes a task priority
  and adds a `busy_wait` — the product string + pins are *identical*, so a soak of the wrong build produces
  byte-for-byte identical evidence. A re-run `embedded-verifier` workflow caught exactly this here and
  returned DO-NOT-PASS: nothing bound the adversarial image to the 1000-cycle soak. Two fixes, best first:
  - **Firmware self-attestation (best).** Have the firmware report *its own build-id* plus a measurement
    proving the stressor fired, over a channel you already poll. Here the CDC1 status reply gained
    `prio` (1 ⇒ task at DAP priority), a *measured* `stall_us` (≈50000 ⇒ the 50 ms `busy_wait` actually ran;
    the +0..49 µs overage was DAP time-slicing it — contention you can *see*), and a monotonic loop counter
    `n`. Now the run self-proves which image ran AND that the dashboard task kept looping — rank-1, no extra
    wiring. This is strictly better than the loopback jumper it replaced.
  - **`picotool verify` retroactively.** When you can't rebuild: `picotool verify <the-exact-uf2>` against
    the untouched post-soak flash binds the image at rank-2 — and run a CONTROL verify against the *wrong*
    image (it must report "contents did not match") to prove the check discriminates, not a vacuous always-OK.

---

## 5. Verify the verifier (your tools lie, each differently)

Embedded toolchains routinely report success on failure. Before a test's verdict means anything,
confirm the test *fails when it should* — feed it a known-bad input once and watch it go red.

Hard-won instances:
- **`probe-rs verify` (0.31) prints "Verification failed: contents do not match" but EXITS 0** on a real
  mismatch (F1-3). A guard written as `if ! probe-rs verify; then fail; fi` counted *nothing*. Fix:
  decide by **stdout content**, not exit code. This silently invalidated an entire soak until an
  adversarial review caught it.
- **`probe-rs erase --chip RP2040` hangs >150 s** — it skips the bootrom block-erase (F0-1). A "hang" was
  read as a dead board; it was a slow tool. Use openocd's rp2040 driver (~7.7 s) for erase.
- **C quote-include adjacency silently defeats an overlay** (F1-2) — `#include "probe_config.h"` from an
  upstream `.c` picks up upstream's *adjacent* header regardless of `-I` order, so a `src/` overlay of it
  has zero effect. picotool showed the stock pins. See `embedded-fork-overlay`.

Operational rule: **for every test tool, know its failure-reporting quirk before you trust its green.**
Confirm by an independent second tool (rank 3) when the claim matters.

---

## 6. The fork-overlay model (reuse > reinvent, without vendoring)

When the core capability already exists upstream (a CMSIS-DAP probe = `raspberrypi/debugprobe`), fork it
*minimally* rather than rewriting:
- **Pin to a deliberately chosen stable tag**, not HEAD. Hackagotchi pinned `debugprobe-v2.2.3` —
  the last tag *before* the #189 SMP-flash regression (commit 457e048). Know *why* your pin is where it is.
- **Overlay, don't vendor.** Upstream is fetched on demand (gitignored); your files compile *instead of*
  the matching upstream files via include-path ordering. You own a small diff, not a copy that rots.
- **Diff each overlay against upstream on every version bump.** The overlay is a liability that must be
  re-justified when the base moves.
- **Beware the quote-include adjacency rule** (§5 / F1-2): inject a board/config via a *shim* of a header
  that is **not adjacent** to the upstream file that includes it.

The full mechanism — shim, include ordering, toolchain pinning, submodule init — is its own skill:
`embedded-fork-overlay`.

---

## 7. Toolchain pinning (the build is part of the product)

A "works on my machine" embedded build is a non-result. Pin and document:
- **The exact compiler.** Hackagotchi builds with **Arm GCC 13.3.Rel1** (on disk, downloaded), NOT the
  host's system GCC 16.1 (too new — breaks the pico-sdk build). Wrong compiler = subtle miscompiles or
  hard build failures.
- **The exact SDK.** pico-sdk 2.2.0 at a known path; cmake honours the SDK's version range.
- **Submodule gotchas.** MicroPython's bundled pico-sdk leaves `lib/tinyusb` uninitialised (it vendors
  its own), so `bsp/board_api.h` is missing for anything that needs TinyUSB. `git submodule update
  --init lib/tinyusb` once; the build script does it idempotently.
- **A clean build script** that sets `PATH`/`PICO_SDK_PATH`, inits submodules, does a `rm -rf` clean
  build, and forwards adversarial flags. CI runs the *same* script + a static-analysis gate.

---

## 8. Reliability scaffolding (build it alongside, not after)

What earned its keep on Hackagotchi and transfers to any firmware:
- **A static-analysis gate** (`analyze.sh`): GCC `-fanalyzer` + strict warnings + cppcheck on *your* code
  (overlay-inherited upstream warnings report-only; new files must be clean). `-fanalyzer` is a free
  tier-zero analyzer — use it. CI runs it as a gate.
- **Third-party notices** (`THIRD-PARTY-NOTICES.md`): every linked component, role, license, source.
  Check licenses are permissive *before* you depend; re-check on cherry-picks. The project's own license
  is a separate, deliberate decision.
- **Build docs** that state the overlay/shim model, pin map, and the build/flash/analyze commands, so the
  next person (or you in three months) reproduces the artifact exactly.

---

## 9. Operating without a recovery path (remote / unattended)

When you can't physically touch the hardware (operator away, no BOOTSEL/replug possible):
- **Classify every operation by blast radius.** *Target*-flashing ops (soaks that flash the DUT) are
  safe — a wedged target is recoverable by the probe. *Probe*-reflashing ops are not — the probe has no
  software self-reset path, so a wedge needs a physical replug you can't do.
- **Only run the safe class.** Hackagotchi ran more soak cycles + did no-hardware work (analyze gate, CI,
  docs, NOTICE) while the operator was away, and never touched anything that could wedge the probe.
- **Front-load the staged builds.** Build the variants you'll *want* on return (the at-DAP-priority
  image) now and compile-verify them, so the return visit is flash-and-measure, not build-and-debug.

---

## 10. Gotchas (learned the hard way)

- **Single-core reality can undercut a multicore plan.** v2.2.3 is `configNUM_CORES=1`; the SMP
  core-affinity isolation the plan assumed does not exist (F1-1). Coexistence became pure
  priority/preemption on one core — which makes the contention test (§3) *more* load-bearing, not less.
  Re-verify the assumption against the actual base.
- **0 stalls ≠ no regression — the shared XIP cache is priority-blind (learned v1.1, 2026-06-22).** On a
  flash-XIP image the DAP/USB response-framing path is flash-resident; a heavy *lowest-priority* task
  (the OLED render loop) churns the 16 KB XIP cache and evicts that path, so the next transaction pays a
  QSPI refill inside the USB-IN response window → **retryable** CMSIS-DAP framing desyncs. They are
  **0-stall** (the RAM-resident USB ISR keeps acking — latency, not a hang), so the R1 hard bar still
  passes while the *retryable rate* silently regresses (v1.1 ~1.4–3.0% vs shipped v1.0 ~0.2%). Priority
  does not protect you — it schedules CPU, not the shared cache/QSPI bus. Lessons: (1) **gate the
  retryable rate against the shipped baseline, not just stalls**; (2) the fix is to pin the hot path into
  SRAM (linker `EXCLUDE_FILE` of the DAP/USB objects, residency-only — no priority change), which took
  the rate to **0/500**.
- **Distinguish a real regression from bench drift with an interleaved A/B against the SHIPPED image.**
  When a candidate's retryable rate looks high you cannot tell "firmware regression" from "noisy host /
  target-QSPI fragility" by one number. Soak the *gold shipped* image and the candidate on the SAME
  bench/host/cable back-to-back, **candidate last in time** (kills the time/order confound), power-cycling
  before each. Here it was decisive: power-cycling the target made the v1.1 rate *worse*, not better —
  falsifying the dirty-bench hypothesis — while the shipped image ran clean on the identical bench, so the
  only variable left was the firmware. Download the released `.uf2` and **sha-match it** so the baseline is
  the exact shipped artifact, not a maybe-different rebuild. A counter like the firmware's own `dap_xfers`
  (transfers executed) read before/after the soak cross-checks that the probe was live throughout — a
  soak whose transfer counter never moved is a silent pass.
- **A counter latched at boot proves nothing.** "The soak ran 1000 times" doesn't prove the OLED task
  kept looping — NAKs are swallowed, an `ok` flag set once stays set. Capture a *monotonic* counter from
  the device (loopback → CDC, or the firmware's own status reply) to prove liveness; eyeball is rank 5.
- **System-alive ≠ task-alive (frozen-but-alive).** A free-running uptime, or a status reply serviced by a
  *higher-priority* task, keeps answering even if your task-under-test froze in a loop. On 2026-06-20 the
  CDC1 `up`/`heap` liveness was serviced by the TUD task (above the dashboard) — so it could not have caught
  a hung dashboard. The fix: report a counter incremented BY the task under test (the dashboard's loop `n`)
  and assert *it* advanced (307→2189, 0 frozen) — that is the rank-1 task-liveness signal, not "device answers."
- **Heap free == min from a no-alloc harness is not headroom.** If the test does zero runtime allocation,
  `free == min` is expected and tells you nothing about the real workload. Re-measure when the actual
  feature mallocs; instrument the right allocator (the SSD1306 framebuffer is C-lib malloc, invisible to
  `xPortGetFreeHeapSize`).
- **Static descriptor decode ≠ enumeration.** USB composite is exactly where static analysis is least
  predictive (host driver quirks). "Flash-ready" from an ELF decode is honest labelling; keep confidence
  low until it enumerates on the actual host.
- **Scope compounds on a small substrate.** Each concurrent subsystem (probe + bridge + control + SD +
  UI) adds memory and scheduling pressure on one small MCU. Gate the *additions*, and re-measure headroom
  as they land — current headroom is not final headroom.

---

## 11. New-firmware checklist

1. [ ] List the **falsifiable architectural risks**; order them by likelihood-of-being-false → gates.
2. [ ] For each gate: claim, minimal rig, quantified bar, **machine** assertion, adversarial variant,
       verdict doc (use the `firmware-gate` skill).
3. [ ] **Pin the toolchain** (compiler + SDK + submodules); write a clean reproducible build script.
4. [ ] If forking upstream: pin a deliberate **stable tag**, overlay-not-vendor, shim the config, diff on
       bump (use `embedded-fork-overlay`).
5. [ ] **Verify the artifact** every build (rank 2): `picotool info` / `nm` / `strings` / descriptor decode.
6. [ ] **Verify the verifier** for every test tool (feed it a known-bad; know its exit-code/stdout quirk).
7. [ ] Establish **provenance** (your build, not stock) and tee it into every log.
8. [ ] Run the gate; if the only stressor that could fail is unrun, the gate is **open** — say so.
9. [ ] Stand up reliability scaffolding **in parallel**: static gate, NOTICE, build docs, CI.
10. [ ] Record the verdict honestly — name every deferred item; "PASS-with-blockers" beats a hollow PASS.

> Many MCU products are coming. The constant across all of them is §0 + §1: **prove the hard claims on
> real hardware, and trust only the highest rank of evidence you can reach.** Everything else is wiring.

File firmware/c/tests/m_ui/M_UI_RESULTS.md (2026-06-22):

# M-UI / v1.2 "Companion" — test results

## Host unit tests (no hardware — run in CI)

| Test | Command | Result |
|---|---|---|
| Sprite blit | `cc -I src -I src/ssd1306 tests/m_ui/blit_test.c -o /tmp/blit && /tmp/blit` | (M-UI baseline) |
| NeoPixel mood renderer | `cc -I src tests/m_ui/neopixel_anim_test.c src/neopixel_anim.c -o /tmp/npa && /tmp/npa` | **PASS** (2026-06-22) |
| Button + joystick logic | `cc -I src tests/m_ui/input_logic_test.c src/input_logic.c -o /tmp/inp && /tmp/inp` | **PASS** (2026-06-22) |

`neopixel_anim_test` asserts off==dark, intensity caps, per-mood channels, the breathing wave, and a
rainbow that actually differs across the chain. `input_logic_test` asserts debounce, short-vs-long
classification, bounce rejection, joystick deadzone/dominant-axis decode, and one-event-per-flick edges.

## Build + static-analysis gate (2026-06-22)

| Build | Result |
|---|---|
| Default (`HG_NEOPIXEL_COUNT=1`, button/joystick OFF) | builds clean; `analyze.sh` **PASS**; DAP/USB hot path still SRAM-pinned (HG_PIN_DAP intact) |
| Companion (`HG_NEOPIXEL_COUNT=5 HG_BUTTON=ON HG_JOYSTICK=ON`) | builds clean; `analyze.sh` **PASS**; new symbols present; `ver=1.2.0-companion` |

Pre-existing `-Wformat-truncation` notes in `hackagotchi_dashboard.c` / `sd_gate.c` are unchanged from
v1.1 and are not gate failures (`analyze.sh` gates `-Wanalyzer-*` + the two pristine files only).

## HIL (hardware-in-the-loop) — PENDING the soldered build

`tests/m_ui/companion_hil.py` — REQUIRED checks (status carries px/btn/joy; mood/fill/btn/joy commands
answer) + interactive button/joystick liveness. Hardware-blind-safe (exit 2 with no probe).

- **2026-06-22, against the bench unit running `1.1.0-pin-dh` (v1.1):** correctly **FAIL** — the v1.1
  image returns `"err":"unknown"` for the new commands and has no px/btn/joy status fields. This is the
  intended "feed it a known-bad input, watch it go red" check; it confirms the test is not a silent pass.
- **Against `1.2.0-companion`:** not yet run — flash the companion image (`HG_NEOPIXEL_COUNT=N
  HG_BUTTON=ON HG_JOYSTICK=ON ./build_fork.sh`, then `picotool load -x`) and re-run. Bar:
  `COMPANION SURFACE: PASS`.
- **Gate 1 coexist soak on the companion image:** not yet run — re-prove **0 stalls** with the strip
  driving + the ADS1115 on the 400 kHz bus before shipping any feature ON.

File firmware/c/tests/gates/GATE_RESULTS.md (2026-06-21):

# Hackagotchi — Gate Results

Copy this file per attempt (e.g. `GATE_RESULTS_2026-06-20.md`) and fill it in. Evidence dirs
(`gate0/ gate1/ gate2/`) are gitignored; attach key logs to the run record.

```
Date: 2026-06-19  Operator: Pratheek  Host macOS: Darwin 25.5.0  probe-rs: 0.31  openocd: 0.12.0  picotool: 2.2
Probe fw source/SHA: stock debugprobe-v2.2.3 (debugprobe_on_pico.uf2), CMSIS-DAP serial 4150324E30363318
Pico SDK tag: 2.x (MicroPython-bundled; blink fixtures built with pinned Arm GCC 13.3.Rel1)
Target: fresh Pico W (RP2040 rev B2, flash 'win w25q16jv' 2MB) running PicoInky 0.8.0 before the wipe
Wired SWD (Gate 0): SWCLK=GP2 (D8)  SWDIO=GP3 (D10)  GND  (3-pin, no RESET)
Wired SWD (Gate 1, REMAPPED + LOCKED): SWCLK=GP26 (D0)  SWDIO=GP27 (D1)  GND  — fork firmware; verified live by probe-rs info (see gate1/provenance.txt). NB: the CMSIS-DAP serial 4150324E30363318 is the RP2040 flash unique-id and is IDENTICAL for the stock probe and the fork — it is NOT firmware-discriminating; the picotool product string ("Hackagotchi Probe") + GP26/27 pin map are.
```

## GATE 0 — stock probe halts/erases/flashes a target  ·  [ **PASS** ]  (2026-06-19, 5/5)
- [x] `probe-rs list` shows CMSIS-DAP — "Debugprobe on Pico (CMSIS-DAP)"
- [x] `info` reads IDCODE: **DPIDR 0x0bc12477** (Part 0x1002, Raspberry Pi); both cores' ROM tables @0xe00ff000
- [x] full 2MB mass-erase 0-error — **via openocd, ~7.7s** (see finding below)
- [x] `download --verify` (probe-rs) ⇒ "Finished in 0.83s" (read-back verify OK)
- [x] `openocd verify_image` ⇒ **verified 6596 bytes** (independent 2nd-tool confirmation)
- [x] `reset` ⇒ rc 0 (LED note: Pico W LED is on the CYW43 chip, not GP25 — blink fixture won't blink visibly; verify is the proof)
- [x] **5/5 consecutive clean runs** (mass-erase 7.69–7.81s, openocd 6596 B every run)
- Evidence: `gate0/`

### Finding F0-1: `probe-rs erase --chip RP2040` is pathologically slow over CMSIS-DAP
A full-chip `probe-rs erase` hung a gate run for >150 s (never completed) — it does not use the RP2040
bootrom `flash_range_erase` block path. **openocd's rp2040 flash driver erases all 2MB in ~7.7 s.** Not a
hardware/wiring fault (the same probe+target mass-erase fine via openocd). `gate0_check.sh` now does the
full mass-erase through openocd and gets the per-region sector-erase proof from `probe-rs download --verify`.
Carry-over for the product: our own recovery/flash flows should use the bootrom block-erase, not probe-rs erase.

## GATE 1 — fork + SWD-remap + OLED task survives sustained flash  ·  [ **PASS** — at-DAP-priority contention CLOSED at rank-1 (2026-06-20) ]
- Fork base: `debugprobe-v2.2.3` (upstream HEAD 466432c)  Build commit **2158e3d**; soak-hardening **07c1a70** (2026-06-19)
- **Build — DONE & statically verified:**
  - [x] Fork builds clean (pinned Arm GCC 13.3.Rel1 + pico-sdk 2.2.0, text 62520, copy_to_ram).
  - [x] SWD locked **SWCLK=GP26 / SWDIO=GP27** (adjacent, SWDIO=SWCLK+1 per probe.pio), PROBE_IO_RAW, UART0 tap GP0/1.
        `picotool info -a` + the soak provenance banner confirm pins 26/27 + "Hackagotchi Probe (CMSIS-DAP)".
  - [x] ONE OLED coexistence task at tskIDLE_PRIORITY (strictly below DAP); real SSD1306 on i2c1 GP6/7;
        touches only I2C+heap (no tud_* → cannot perturb USB/DAP). heap_4.
- **Soak — DONE (pre-soak `probe-rs info` on GP26/27 read both cores' ROM tables):**
  - [x] probe-rs: **1000/1000**, 0 fails, 0 stalls, 0 re-verify mismatch
  - [x] openocd twin: **200/200**, 0 fails, 0 stalls
  - [x] adversarial 50 ms (idle-prio): **1000/1000**, 0 fails, 0 stalls *(build flashed via picotool load; `stall=` self-proof deferred — see verdict)*
  - [x] stretch (hardened script + provenance banner, on the adversarial-50ms firmware): **3000/3000**, 0 fails/stalls/mismatch — probe healthy after. Cumulative Gate-1 evidence = **5200 clean flash cycles**.
  - ⚠️ **CAVEAT — these counts measure the PROBE, and assume a HEALTHY, well-powered TARGET.** A clean run needs the target's AHB-AP up (a HardFault-locked or QSPI-brown-out target cannot run the flash ROM functions and will verify-mismatch no matter how good the probe is). Two confounds seen repeatedly: (1) a back-to-back *sustained* soak brown-out-glitches this particular target Pico W — power-cycle the TARGET between long runs (M4_RESULTS.md §R1); (2) a locked target (the only failure mode `recover.sh` hit on 2026-06-21). The harness now classifies these as `TARGET-GLITCH` (AHB-AP gone) and reports `target_glitch=` separately from the PROBE verdict — see `lib_target_state.sh`. Re-confirmed clean 2026-06-21 on a healthy independently-powered target: probe-rs **40/40** + openocd **20/20**, 0 fails / 0 stalls.
  - [x] OLED counter advanced throughout — **operator-attested** ("the OLED was always working perfectly", 2026-06-19) + pre-soak visual (n= rising, heap min 51016)
  - Pass/fail decided by STDOUT ("Verification successful" count==N, no "Verification failed"), NOT exit code — see F1-3.
  - Heap: scheme **heap_4**  free **51016 B**  min-ever-free **51016 B** (of 64 KB)  leak? none observed  **DECISION: keep heap_4**
    (capability + the coexistence harness does ZERO runtime FreeRTOS allocation, so free==min is expected; revisit when the
    real dashboard mallocs, and instrument newlib then — the SSD1306 framebuffer is C-lib malloc, invisible to xPortGetFreeHeapSize).
  - Evidence: `gate1/soak_*.log` (provenance banner + per-cycle verify), `gate1/provenance.txt`.

### Verdict — 5-lens adversarial verification (workflow wf_8b26aea9): PASS_WITH_BLOCKERS → core claim PASSES, robustness deferred
The DAP-safety ENGINEERING was verified sound by all lenses + an independent re-check (DAP higher-prio than the OLED task,
single-core, `i2c_write_blocking` holds no lock/IRQ, three independent peripherals, no priority inversion); the soaks are real
(0 fails under the corrected check). Blocker disposition:
- [x] **F1-3 (CRITICAL) — defanged re-verify guard:** `probe-rs verify` 0.31 prints "Verification failed: contents do not match"
      but EXITS 0 (confirmed live). The old `if ! probe-rs verify` counted nothing. FIXED (07c1a70: decide by stdout); existing
      logs retroactively re-validated clean.
- [x] **Provenance:** the CMSIS-DAP serial is the RP2040 flash unique-id (identical stock↔fork), NOT firmware-discriminating.
      Closed via the picotool product string + GP26/27 pin map + a `probe-rs info` provenance banner now teed into every soak log.
- [x] **OLED liveness** (a clean soak alone doesn't prove the panel kept looping — NAKs are swallowed, `ok` latched at boot):
      closed by operator attestation + pre-soak visual confirmation.
- [x] **Gate doc** now records the run (this section).
- [x] **CLOSED 2026-06-20 on hardware return** (see the at-DAP-priority close-out section below) — the deferred
      machine-capture + genuine contention test are DONE at rank-1; this verdict is upgraded from PASS_WITH_BLOCKERS
      to unconditional PASS for the at-DAP-priority contention claim.

### Close-out 2026-06-20 — at-DAP-priority GENUINE contention, machine-captured (adversarial workflow wf_96721d04)
The 5200 prior cycles were at IDLE priority (DAP preempts in ~50 µs = a weak/tautological stressor) and the running
image was never machine-bound to the soak. Both are now fixed; a re-run adversarial workflow (4 lenses) had flagged exactly
these as a **silent-pass risk** (a stock-image soak would have produced byte-identical evidence) and returned DO-NOT-PASS
until bound — that binding is now done:
- **Genuine contention build, artifact-verified (rank-2):** `build-gate1-adv` with `ADVERSARIAL_AT_DAP_PRIO=ON`
  (DASH task at DAP priority 1 — objdump: `main` `movs r3,#1` before the 3rd `xTaskCreate`, vs `#0` in stock `build/`)
  + `ADVERSARIAL_STALL_MS=50` (objdump: `dashboard_task` loads literal `0xc350`=50000 into `busy_wait_us`; absent in stock).
  FreeRTOS is `configUSE_PREEMPTION=1` + `configUSE_TIME_SLICING=1` @ 50 µs tick, single-core, so a non-yielding 50 ms
  busy_wait at DAP's own priority genuinely round-robins with DAP — NOT the idle-prio tautology.
- **Soak A (provenance-bound, rank-2): 1000/1000, 0 fails / 0 stalls** at at-DAP-priority. Binding: AFTER the soak,
  `picotool verify /tmp/gate1-adv-a75ff0fa.uf2` against the untouched device flash = **OK** (byte-match to the adversarial
  image, sha `a75ff0fa…`), and the control `picotool verify build/…uf2` (stock `45aba69c…`) = **device contents did not
  match** → the soak provably ran the adversarial image, discriminated from stock.
- **Soak B (self-attesting, rank-1): 300/300, 0 fails / 0 stalls** on a rebuilt image that reports its own identity over
  CDC1 (`{"fw","heap","up","n","stall_cfg","stall_us","prio"}`). Captured every 5 s throughout (`gate1_liveness.py`):
  - `prio=1` for all 95 samples → at-DAP-priority build running (provenance from the firmware itself).
  - `stall_us` = 50000–50049 every sample → the 50 ms busy_wait actually FIRED (the +0..49 µs overage IS DAP
    time-slicing the busy_wait — direct evidence of genuine contention, not a number).
  - **`n` 307 → 2189, 0 N-FROZEN events → the DASHBOARD TASK looped continuously DURING the DAP soak** — closes the
    frozen-but-alive gap that CDC1-only/`up`-only liveness could not (CDC1 is serviced by the higher-prio TUD task).
  - `up` monotonic 76→547 s (no reset), heap flat 51016 B, CDC1 answered every poll (USB never wedged).
- **Verdict signal proven FALSIFIABLE (rank-1):** flash A then `probe-rs verify` B → **"Verification failed: contents do
  not match"** (red path fires); matching image → "Verification successful". So 1300/1300 clean is a real result, not a
  no-op count. (Confirms F1-3 live: `verify` prints failed but the script decides by stdout, not exit code.)
- **DAP healthy after both soaks:** `probe-rs info` reads both target cores' ROM tables; final self-attest `n=2199`.
- **Remaining DISCLOSED caveats (not blockers):** (a) heap-flat is near-vacuous — the harness does zero FreeRTOS alloc and
  the SSD1306 framebuffer is C-lib malloc invisible to `xPortGetFreeHeapSize`; revisit at M1 with newlib instrumentation.
  (b) A non-yielding busy_wait is a CPU-hog proxy; it does NOT exercise shared-bus (SD/SPI) or IRQ-latency contention a real
  blocking peripheral would (plan R1 worst case). (c) The SHIP config runs DASH strictly BELOW DAP (prio 0) — this build is a
  conservative UPPER BOUND, so passing it exceeds the product requirement.
- Evidence: `gate1/fullsoak_*.console` + `soak_*.log` (Soak A), `gate1/resoak_*.console` + `resoak_selfattest_*.csv`
  (Soak B), `gate1/provenance_20260620T110945.txt`. Self-attestation added in `src/cdc1_control.c` + `hackagotchi_dashboard.{c,h}`.

### Finding F1-1: debugprobe-v2.2.3 is SINGLE-CORE FreeRTOS (the engineering-plan SMP affinity model does NOT apply)
`src/FreeRTOSConfig.h` sets `configNUM_CORES=1`; no `multicore_launch`/`vTaskCoreAffinitySet` anywhere
(SMP — and the #189 flash regression — arrived later, via commit 457e048, which is exactly why 2.2.3
was pinned). So the plan's "DAP on core 1, dashboard on core 0" cannot be used. DAP is the LOWEST of
the three upstream tasks (UART+3 > TUD+2 > DAP+1); the OLED task is added strictly below DAP
(tskIDLE_PRIORITY). The DAP guarantee is therefore **priority/preemption**, not core isolation — a
more conservative gate (the 23 ms ssd1306_show I2C burst, and the adversarial 50 ms busy-wait, are
both fully preemptible by DAP). When we later spike `debugprobe-v2.3.1`, re-evaluate under real SMP.

### Finding F1-2: board pins injected via a boards/ shim, not a probe_config.h overlay
The C quote-include rule searches the including file's own directory first, so upstream's `.c` files
always pick up upstream's adjacent `probe_config.h` regardless of `-I` order — a `src/probe_config.h`
overlay silently had NO effect (picotool showed the stock GP12/13/14 pins). Fix: shadow
`board_debug_probe_config.h` (which is NOT adjacent to probe_config.h) from `boards/` instead; the
unmodified upstream probe_config.h `#include`s it and our copy wins for every TU. The picotool-info
check is the guard that catches a wrong-board build.

## GATE 2 — 2nd CDC: two nodes, DAP binds, JSON round-trip  ·  [ **PASS** (core) — 2026-06-20 live hardware ]
- Device class: `0xEF/0x02/0x01` (IAD composite)  CFG_TUD_CDC=2  ·  build commit: see git log
- **Firmware — BUILT & statically verified (no hardware; can't enumerate while operator away):**
  - [x] Builds clean (text 64340); `build/` rebuilt to the Gate-2 image — `nm` shows `tud_cdc_rx_cb`,
        `strings` shows "Hackagotchi UART" + "Hackagotchi Control".
  - [x] Descriptor decoded from the ELF: wTotalLength **164 == sum(bLength) 164**; **5 interfaces**
        (0=DAP-vendor, 1/2=CDC0, 3/4=CDC1); **2 IADs** (firstItf 1 & 3); endpoints
        {0x04,0x85,0x81,0x02,0x83,0x86,0x07,0x88} **no collisions**.
  - [x] DAP integrity: vendor ITF0 + EP 0x04/0x85 byte-identical to upstream, appended-before the
        CDCs, MS-OS-2.0/WinUSB still keyed on ITF0 → probe-rs will still bind. CFG_TUD_VENDOR=1.
  - [x] Fixed a real 2-CDC bug: `cdc_uart.c` line-coding/line-state/send-break callbacks now itf-guard
        to CDC0 (else opening/closing/setting-baud on CDC1 would reprogram/suspend the UART bridge).
  - [x] CAP_BREAK runtime index rewritten to CDC0 (idx 62 = CDC0 ACM bmCapabilities; old relative
        form would land in CDC1).
  - [x] RP2040 DPSRAM budget sufficient (8 EPs ≈ 896 B of 3712 B); +4.2 KB .bss for the 2nd CDC FIFO.
  - 4-lens adversarial workflow (wf_62d07ed1): SOURCE spec-correct; the only NEEDS_FIX was a stale
    `build/` artifact (now rebuilt). Notes deferred to M1: CDC1 uses `strstr("status")` not jsmn
    (fine — gate2_cdc.py sends one clean line); `tud_cdc_n_write` return unchecked (fine for ~50 B).
- **Validation — PASS on LIVE hardware (2026-06-20, attempt 2; `build/hackagotchi_probe.uf2` flashed via `picotool load -x`):**
  - Pre-flash provenance (rank-2, decoded from the staged ELF): pins GP26/27, product "Hackagotchi Probe
    (CMSIS-DAP)", strings "Hackagotchi UART"+"Hackagotchi Control", `tud_cdc_rx_cb` present, reply template
    `{"fw":"Hackagotchi","heap":%u,"up":%u}` — confirmed the 2-CDC image BEFORE flashing.
  - [x] exactly TWO `/dev/cu.usbmodem*` nodes — **usbmodem21202 + usbmodem21204**
  - [x] `probe-rs list` still finds the probe — **"Hackagotchi Probe (CMSIS-DAP)"** — DAP binds WITH both CDCs
        present (re-checked AFTER the 100-cycle round-trip: still bound). [a target-attached `info` IDCODE read
        is the stronger DAP proof — captured on the Gate-1 rig, which wires a real target.]
  - [x] node map by ROLE (behavioral, suffix-independent): **CDC0=UART = usbmodem21202** (silent to `status`),
        **CDC1=Control = usbmodem21204** (answers JSON). macOS does not surface the iInterface strings as BSD
        names (`ioreg` shows both as "usbmodem"), so role is keyed on behavior — more robust than a name string.
  - [x] `{"q":"status"}` → **100/100 valid JSON** (latency avg 0.3 ms / max 0.5 ms). **NEGATIVE CONTROL:** the
        UART node returned 0 replies to the identical request → the round-trip check genuinely discriminates and
        CAN emit FAIL (not a tautology).
  - [x] heap watermark machine-read live: **free=51016 B** in the reply — IDENTICAL to Gate-1's recorded 51016
        (the +4.2 KB 2nd-CDC FIFO is `.bss`/static, NOT on the FreeRTOS heap) → **closes the Gate-1 heap
        re-measure note** at rank-1. (`up=104 s` also confirms the monotonic clock.)
  - [ ] DEFERRED (low-risk; operator opted to skip 2026-06-20): node-map stable across 3 replug + 1 host reboot —
        role is behavioral/suffix-independent so the residual risk is cosmetic; CDC0 carrying live *target* UART —
        no target-UART wire / no loopback jumper this session (the Gate-1 rig is SWD-only).
  - Evidence: `tests/gates/gate2/roundtrip_*.log`

---
**OVERALL (2026-06-20, hardware return):**  Gate 0 ✅ PASS (5/5)  ·  Gate 1 ✅ PASS — at-DAP-priority GENUINE contention closed at rank-1 (1000 cycles provenance-bound by `picotool verify` + 300 self-attesting cycles: dashboard `n` looped 307→2189, `stall_us`≈50000, `prio=1`, 0 fails; heap/representativeness caveats disclosed)  ·  Gate 2 ✅ PASS (core) — 2 nodes + DAP binds + 100/100 JSON live; replug-stability + CDC0-live-UART deferred (low-risk).  **All three gates pass on hardware → cleared to start M1 (UI port).**

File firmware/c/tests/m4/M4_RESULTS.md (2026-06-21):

# M4 — Full UI parity (CDC1-driven) — **COMPLETE, HIL-verified (2026-06-21)**

M4 ports the remaining MicroPython OLED-family features to the C firmware. The original drove them as
**button menus**; the probe has **no button** (GP27 became SWDIO at Gate 1), so the redesign is: **actions
over CDC1, state shown on snapshot-fed screens** — the M3 pattern extended. Triage against the LOCKED pin
map dropped the hardware-bound screens (I2C-scan / Oscilloscope / GPIO-mon / PWM-lab / Demo: their pins are
SWD/SD/UART; the scanner would only find our own OLED now). The feasible, valuable set was built:
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

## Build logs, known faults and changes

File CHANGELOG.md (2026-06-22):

# Changelog

All notable changes to the Hackagotchi C probe firmware (`firmware/c`) are documented here.
Format follows [Keep a Changelog](https://keepachangelog.com/); headings are the release tags. The
firmware's own semver is compiled into the binary and reported by `{"q":"status"}` → `"ver"`.

## [1.1] - 2026-06-22

The **OLED UI overhaul** — a cat + Spectre the ghost give the probe a face — shipped together with the
**`HG_PIN_DAP` reliability fix** that the overhaul turned out to need, plus DAP health telemetry. Still
**R1-clean: 0 DAP transfer stalls.**

### OLED UI overhaul — the cat + Spectre the GhostLabs ghost (M-UI-1..5)
A full dashboard glow-up where **every flicker of personality is a literal readout of a real
probe/recorder signal** — all within R1 (idle-priority render, snapshot-only reads) and the
camera-free text-attestation model.

- **Graphics engine:** `ssd1306_blit()` — a clipped 1-bit sprite blit (OR / ANDNOT / XOR) with a
  pico-free, host-unit-tested core (`tests/m_ui/blit_test.c`) and an ASCII-art sprite pipeline
  (`tools/spr_gen.py` → `sprites.gen.h`). Sprites are flash-resident (~0 RAM).
- **Persistent status bar** on every screen (REC / SD glyphs + a ghost pip), attested as a `BAR …`
  line; `DASH_MAX_LINES` 6→8 so a new token can never silently drop a literal fact. New `hud_gauge_h()`.
- **Spectre, the ghost** — its state *is* the target board's soul: dozing (quiet) / live (talking) /
  pale (wedged) / glitch (SD fault) / exorcised, from recent UART liveness, attested `g:<state>`.
- **Cat moods** — sleep / content / hunting / alert from existing signals, attested `cat:<mood>`;
  flying-data particle speed scales with live throughput.
- **Resurrection tally** — wedge→recover + fault counts, edge-counted in the 50 Hz SD task (not the
  4 Hz render loop, which could miss a fast edge) and shown on UPTIME.
- **Companion interaction over CDC1** (no physical button): `pet`, `summon`/`banish`, `exorcise`
  (a host flasher fires it after a clean reflash), `ghost` (mute → pure-instrument cluster), `theme`
  (motion density). An optional dither screen-wipe between screens is available behind `-DHG_SCREEN_WIPE`
  (off by default — at 4 Hz a single full-frame XOR reads as a glitch, not a smooth transition).

Footprint: text +3.3 KB, bss +164 B total. Static-analysis gate green; the blit host unit test and an
extended `screen_hil.py` attest the new surfaces.

### DAP reliability — XIP-cache-contention fix (`HG_PIN_DAP`, ON by default)
The heavier render loop above exposed a subtle, **0-stall** regression and we fixed it before shipping:

- **The finding.** The firmware runs from flash XIP through a 16 KB instruction cache. The v1.1 render
  loop (blit engine + ghost compositing, ~8 blits/frame) churns a large enough flash-instruction working
  set to **evict the flash-resident CMSIS-DAP framing path** from that cache; the next transaction pays a
  QSPI refill inside the USB-IN response window → **retryable** DAP framing desyncs (wrong command-ID /
  short-transfer / IN-timeout). It stays **0-stall** (the RAM-resident USB ISR keeps acking the bus — added
  *latency*, not a lock), so it passed the R1 hard bar yet regressed the strict Gate-1 *retryable* rate the
  shipped v1.0 met (**~1.4–3.0% vs v1.0's ~0.2%**). Priority can't save it — when the DAP task runs, the
  cache is already polluted. Proven by an **interleaved A/B against the shipped v1.0 image** on one bench
  (candidate last-in-time → not bench drift). The *light* v1.0 UI never crossed this threshold; the v1.1 UI does.
- **The fix — `HG_PIN_DAP`.** A gated custom linker script (`memmap_hackagotchi_pin.ld`) drops the 7
  DAP/USB transaction objects from flash `.text` (via `EXCLUDE_FILE`) so they run from **SRAM**, out of the
  contended cache. **Residency change only — no FreeRTOS priority change, no upstream edit** — costing
  ~18.8 KB of the +139 KB XIP SRAM win. The pinned image soaks **0/500** (Gate 1 PASS, cleaner than v1.0's
  own ~0.2%) — the clean reference. (A longer 1000-cycle run of the pin+telemetry image on a *non-idle*
  host stayed **0-stall** but logged 2 retryable desyncs on one cycle — a strict-bar `FAIL` at ~0.2%, the
  v1.0-class floor; an idle-host re-run for a clean 0/N is the one open item — see `release-readiness.md` §0.)
  **ON by default from v1.1**; build `HG_PIN_DAP=OFF` to reproduce the pre-fix image for an A/B soak.
- **DAP health telemetry.** `{"q":"status"}` now reports `dap_xfers` (monotonic CMSIS-DAP commands
  executed, via a `--wrap=DAP_ExecuteCommand` witness) and `dap_idle_ms` — a machine-checkable liveness
  cross-check so a "clean" soak can't silently pass with a dead probe. The witness object is itself pinned.

See [`docs/firmware-conventions.md`](docs/firmware-conventions.md) §2 ("the XIP cache is priority-blind"),
[`docs/mcu-bringup-playbook.md`](docs/mcu-bringup-playbook.md) §10, and `docs/release-readiness.md`.

## [1.0] - 2026-06-21

First public release. A debug probe that is *also* a black-box flight recorder and a reactive,
Tamagotchi-style dashboard for dev boards that go dark — a fork of Raspberry Pi `debugprobe`
(v2.2.3) that stays **R1-clean (0 transfer stalls)** while doing all three at once.

### Probe / DAP
- CMSIS-DAP v2 probe over SWD-on-PIO (full debug + flash of an RP2040 target), forked from
  `debugprobe-v2.2.3`. SWD remapped + locked to GP26/GP27. The DAP path is guaranteed by FreeRTOS
  task **priority** on the single-core RP2040 (v2.2.3 is single-core — not SMP).
- Runs from flash XIP (not `copy_to_ram`): **+139 KB free SRAM** at identical DAP throughput.

### Bridge + control (two CDC interfaces)
- **CDC0** = transparent target-UART bridge (GP0/GP1), IRQ-driven into a lock-free SPSC ring (0 drops).
- **CDC1** = JSON control channel (`{"q":...}`): status/dump/lastfault, screen nav, hex sniffer,
  macro sender, runtime baud select, SD explorer (ls/cat), settings persistence, beep/led/pixel,
  `bootsel` (hands-free reflash), and test hooks. jsmn-based, bounded, fragmentation-safe.

### Reliability core (M1)
- Post-mortem **crash box** — HardFault + malloc-fail captured to memory that survives the reboot,
  read back over `{"q":"lastfault"}`.
- **Software watchdog**, armed by default, monitoring the USB task (so DAP load can't starve it).
- `{"q":"bootsel"}` software reset-to-bootloader for button-free reflashing.

### SD black-box recorder (M2)
- carlk3 FatFs on SPI0 continuously logs the target's UART (session headers, heartbeats,
  visible-stop + wedge detection, trigger freeze-frames) — the "flight recorder."
- Proven to coexist with DAP flashing: **0 stalls** under a continuous-write soak (the R1 invariant).

### OLED dashboard (M3) + full tool UI (M4)
- 128×64 SSD1306 over I2C1 @ FM+ (1 MHz, single-owner bus): a cat mascot + 6 monitoring screens
  (home / sniffer / recorder / throughput / watchdog / uptime), plus buzzer + WS2812 NeoPixel event
  feedback — all snapshot-fed off the DAP hot path.
- No physical button (GP27 is SWDIO), so navigation + tools are CDC1-driven; the tool screens
  (hex / macro / baud / SD) are excluded from auto-cycle so the panel never parks on a menu.

### Release engineering (M5)
- Firmware **semver compiled in** and reported via `{"q":"status"}` → `"ver"`.
- Manual-dispatch CI (`firmware-c.yml`): build + static-analysis gate (GCC `-fanalyzer` + cppcheck),
  artifacts, and an optional tagged Release that ships the binaries **plus NOTICE + LICENSE**.
- Licensing: project **GPL-3.0-or-later**; the `firmware/c/` subtree **MIT** (upstream-compatible).
  All linked third-party code is permissive (MIT / BSD-3 / Apache-2.0), attributed in
  `THIRD-PARTY-NOTICES.md`.

### Verified
- All gates + milestones HIL-attested on the tagged image — see [`docs/release-readiness.md`](docs/release-readiness.md):
  Gate 0/1/2, the M1–M4 suites, host unit tests, and the R1 0-stall coexistence invariant.

### Known caveats
- Retryable (0-stall) DAP transfer errors rise under an *artificial* continuous-max-SD soak; ~0 in
  real use (the target is halted during a real flash). Host-load-sensitive — run soaks on an idle host.
- Some target boards re-glitch their QSPI under sustained flash hammering (still 0 stalls); power-cycle
  the target between long soak campaigns. Orthogonal to the probe firmware.

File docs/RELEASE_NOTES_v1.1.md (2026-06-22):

## Hackagotchi probe firmware — v1.1 🛠️🐾👻

**The "give it a soul" release.** v1.0 shipped the hard part — a CMSIS-DAP debug probe, a UART-to-microSD
black-box recorder, and a reactive OLED dashboard, **all three on one single-core RP2040 without ever
stalling a flash**. v1.1 gives that machine a *face*: a cat and **Spectre, the ghost**, where every
flicker of personality is a **literal readout of a real probe/recorder signal** — not decoration.

And because we hold ourselves to "prove it on hardware," the heavier graphics exposed a subtle, *zero-stall*
timing regression — so we caught it, root-caused it, and **fixed it before shipping** (the `HG_PIN_DAP`
story below). Still **R1-clean: 0 DAP transfer stalls.**

---

### 🆕 What's new since v1.0

| | Feature | Attested as |
|---|---|---|
| 👻 | **Spectre, the ghost** — its state *is* the target's soul: dozing (quiet) / live (talking) / pale (wedged) / glitch (SD fault) / exorcised, driven from real UART liveness | `g:<state>` |
| 🐱 | **Cat moods** — sleep / content / hunting / alert from live signals; flying-data particle speed scales with throughput | `cat:<mood>` |
| 🎨 | **A real graphics engine** — `ssd1306_blit()`, a clipped 1-bit sprite blit (OR / ANDNOT / XOR), host-unit-tested, fed by an ASCII-art sprite pipeline. Sprites are flash-resident (~0 RAM) | `blit_test.c` |
| 📊 | **Persistent status bar** on every screen (REC / SD glyphs + a ghost pip) | `BAR …` line |
| 💀 | **Resurrection tally** — wedge→recover + fault counts, edge-counted in the 50 Hz SD task (never misses a fast edge) | on UPTIME |
| 🕹️ | **Companion interaction over CDC1** (no button): `pet`, `summon`/`banish`, `exorcise` (auto-fired after a clean reflash), `ghost` (mute → pure instrument), `theme` (motion density) | CDC1 verbs |
| 🛡️ | **`HG_PIN_DAP`** — DAP/USB hot path pinned to SRAM (the XIP-cache fix below). **On by default.** | `dap_xfers` = live |
| 📈 | **DAP health telemetry** — `{"q":"status"}` now reports `dap_xfers` (transfers executed) + `dap_idle_ms` | `status` reply |

The whole character layer renders at the **lowest priority off snapshot-only reads** — it never touches
the DAP hot path. (v1.0's full feature set — probe, recorder, two CDCs, crash box, watchdog, SD explorer —
is all unchanged and carried forward.)

---

### 🛡️ Under the hood: the regression we caught (and fixed)

A debugger you can't trust isn't a debugger. So this is worth a paragraph.

The firmware runs from **flash XIP** through a 16 KB instruction cache (that choice buys +139 KB of SRAM at
identical DAP throughput). The new render loop churns a big enough flash-instruction working set that it
**evicts the CMSIS-DAP framing path from that cache** — and the next probe transaction pays a flash-refill
delay right inside the USB response window. The result was **retryable** DAP desyncs at **~1.4–3.0%**, where
shipped v1.0 sat at **~0.2%**. Crucially it was **still 0-stall** (the RAM-resident USB ISR keeps the bus
acked — it's added *latency*, not a hang), so it slipped past the hard correctness bar while quietly
regressing a softer one. **Task priority doesn't help here: priority schedules the CPU, not the shared
cache.** We proved it was the firmware (not bench noise) with an **interleaved A/B against the actual
shipped v1.0 image** on one bench, candidate last-in-time.

**The fix (`HG_PIN_DAP`, on by default):** a linker variant pins just the 7 DAP/USB transaction objects into
**SRAM**, out of the contended cache — a *residency* change only (no priority change, no upstream edit,
~18.8 KB of the SRAM headroom). The pinned image soaks **0/500**, back at/below the v1.0 floor, 0 stalls
throughout. And to make sure a "clean" soak can never silently pass with a dead probe, the probe now
self-reports a monotonic `dap_xfers` counter you can read before/after.

→ Full write-up: `docs/firmware-conventions.md` §2, `docs/mcu-bringup-playbook.md` §10, `docs/release-readiness.md` §0.

---

### ⬆️ Flash it / upgrade from v1.0 (no toolchain needed)

1. Download **`hackagotchi_probe.uf2`** below.
2. Enter BOOTSEL — on a running v1.0 unit, **hands-free**: send `{"q":"bootsel"}` to the control port
   (there's no button — GP27 is SWDIO). Otherwise BOOTSEL the XIAO at power-up.
3. `picotool load -x hackagotchi_probe.uf2` (or drag the `.uf2` onto the `RPI-RP2` drive).
4. Confirm — send `{"q":"status"}` to the control serial port → `{"fw":"Hackagotchi","ver":"1.1.0",…,"dap_xfers":…}`.

Settings persist across the upgrade. No re-wiring; same pin map as v1.0.

---

### ✅ Verified on this image

- **Build + static-analysis gate** (`analyze.sh`) — PASS; the two pristine TUs stay 0-warning.
- **Artifact provenance** — `strings` → `ver 1.1.0`; `nm` confirms all 7 DAP/USB objects resident in SRAM
  (`0x2000xxxx`), i.e. the fix is actually in the binary, not just the source.
- **DAP under sustained flash** — the pinned image soaks **0/500** (Gate 1, **0 stalls**) — the clean
  reference. A longer 1000-cycle run on a *non-idle* host stayed **0-stall** but logged **2 retryable
  (recoverable) desyncs on a single cycle** — a strict-bar miss at ~0.2% (the v1.0-class idle floor), with
  a live `dap_xfers` witness (~2 M transfers serviced) confirming the probe never went dark. The fix is
  proven by the A/B (the ~7–15× regression is gone) + the 0/500; an idle-host 1000-cycle re-run for a
  clean 0/N is the one open item (`docs/release-readiness.md` §0).
- The v1.0 HIL suite (probe / bridge / recorder / crash box / watchdog / CDC / SD) carries forward —
  unaffected by a `+0` UI layer + a residency change. See `docs/release-readiness.md`.

---

### 📦 Assets

`hackagotchi_probe.uf2` · `hackagotchi_probe.elf` (to symbolicate crash dumps) · `THIRD-PARTY-NOTICES.md` · `LICENSE`

### 📝 Notes

- The firmware reports its own version live (`{"q":"status"}` → `ver` = `1.1.0`).
- **License:** project GPL-3.0-or-later; the `firmware/c/` subtree MIT. All dependencies permissive (MIT / BSD-3 / Apache-2.0).
- ⚠️ Under an *artificial* continuous-max-SD soak, retryable (0-stall) DAP errors can still appear — ~0 in
  real use (the target is halted during a real flash). Run soaks on an idle host. Some target boards
  re-glitch their QSPI under sustained hammering (still 0 stalls) — power-cycle the target between long soaks.

📓 Full changelog: `CHANGELOG.md` · 🔧 build from source: `docs/c-firmware-build.md` · 🛠️ build a unit: `docs/build-a-hackagotchi.md`

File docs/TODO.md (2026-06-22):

# Hackagotchi — TODO

Working backlog. The plan of record is `docs/engineering-plan.md`; this is the live checklist.

## Now — the 3 gates (gates-first; no OLED port until all pass)
- [x] **Gate 0 (probe half):** bare XIAO flashed with stock `debugprobe_on_pico.uf2` (v2.2.3),
  enumerates as CMSIS-DAP (probe-rs sees it). *(2026-06-19)*
- [x] **Gate 0 (fixtures):** `blink_a.elf` (250ms) + `blink_b.elf` (80ms) built & on disk
  (`fixtures/`, gitignored) via pinned Arm GCC 13.3.Rel1 + existing pico-sdk — NOT system GCC 16.1.
  Full download+verify is ready. *(2026-06-19)*
- [x] **Gate 0 (finish): PASS — 5/5 clean** *(2026-06-19)*. Fresh Pico W target (RP2040 rev B2),
  SWCLK=GP2/SWDIO=GP3/GND. info reads DPIDR 0x0bc12477; full 2MB mass-erase via openocd ~7.7s;
  probe-rs `download --verify` + openocd `verify_image` (6596 B) both confirm. See
  `firmware/c/tests/gates/GATE_RESULTS.md`. **Finding F0-1:** `probe-rs erase` is pathologically slow
  on RP2040 (>150s, doesn't use bootrom block-erase) — gate + our recovery flows use openocd/bootrom.
- [x] **Gate 1 — build half** *(2026-06-19, commit 2158e3d)*: fork built on debugprobe-v2.2.3,
  SWD remapped + **locked** to GP26/GP27 (adjacent), UART0 tap GP0/1, one lowest-prio OLED
  coexistence task on a real SSD1306 (i2c1 GP6/7), **heap_4**. Builds clean (pinned GCC 13.3 +
  pico-sdk 2.2.0); `picotool info` verifies the pin map. Findings F1-1 (v2.2.3 is single-core
  FreeRTOS — no SMP affinity), F1-2 (board injected via boards/ shim, not a probe_config.h overlay).
- [x] **Gate 1 — soak half: PASS (core claim)** *(2026-06-19, commit 07c1a70)*. probe-rs 1000/1000,
  openocd 200/200, adversarial-50ms 1000/1000 (+3000 stretch), all 0 fails/stalls under the corrected
  stdout check; OLED liveness operator-attested; **heap_4 kept**. 5-lens verification = PASS_WITH_BLOCKERS;
  blockers closed (F1-3 verify-guard bug fixed, provenance banner, doc). See GATE_RESULTS.md.
- [x] **Gate 1 — deferred robustness** — **CLOSED** *(2026-06-20, GATE_RESULTS Close-out wf_96721d04)*:
  at-DAP-priority genuine contention machine-captured (`prio=1`, `stall_us≈50000`, dashboard `n`
  307→2189, 0 fails); the gate doc is upgraded to unconditional PASS for the contention claim.
- [x] **Gate 2 core** — **PASS** *(2026-06-20)*: 2nd CDC (IAD `0xEF/0x02/0x01`), DAP still binds,
  `gate2_cdc.py` round-trip 100/100, exactly two nodes.
- [~] **Gate 2 deferrals (M5)** — tooling built + (b) firmware-proven: `gate2_cdc.py --live-uart` PASS
  (CDC0 UART loopback 0-drop + CDC1 answered + 0 stalls concurrent with a DAP soak); `--replug-rounds`
  added for (a). Pending the operator bench run: (a) physical 3× replug + 1 reboot, and a (b) re-run on a
  power-cycled target so the flash also completes clean. See `docs/release-readiness.md`.

## After gates pass — build the firmware (engineering-plan M1–M5)
- [x] **M1 probe + bridge + CDC1 control + reliability core** — **COMPLETE / PASS** *(2026-06-20)*,
  HIL-verified end-to-end (`tests/m1/M1_RESULTS.md` OVERALL). Conventions codified in
  `docs/firmware-conventions.md`. Cleared to start M2.
  - [x] **Crash box** (fault handler/crash-box + stack/malloc hooks routed to it) — **PASS, HIL-verified**
    *(2026-06-20)*: `isr_hardfault` overlay captures the M0+ exception frame to `.uninitialized_data`
    (survives the watchdog reboot — verified outside the bss clear), surfaced via CDC1 `{"q":"lastfault"}`;
    `tests/m1/crashbox_hil.py` forces a fault and asserts capture+survival+re-enumeration (0→1).
  - [x] **SW-watchdog task** — **PASS, HIL-verified** *(2026-06-20)*: monitors the high-prio TUD task
    (not a low-prio one — would false-reset mid-flash), records `kind=watchdog/task=TUD` + reboots;
    disarmed by default (HW WDT off until `wd_arm`); `tests/m1/watchdog_hil.py` (arm→wedge→assert).
  - [x] **`{"q":"bootsel"}`** CDC1 command (`reset_usb_boot`) — **PASS, HIL-verified** *(2026-06-20)*:
    dropped to BOOTSEL + reflashed via `picotool` with no button. Dev loop is now hands-free.
    Recovery guarantees documented in `docs/recovery-model.md`.
  - [x] **jsmn parser** (replaces `strstr`) + `next`/`prev`/`dump` — **PASS, HIL-verified** *(2026-06-20)*:
    vendored `src/jsmn.h` (MIT), bounded line buffer, structured `"q"` dispatch; `tests/m1/jsmn_hil.py`
    proves strstr false-positives (`{"q":"statusx"}`, `{"note":"status please"}`) are now rejected +
    fragmented requests reassemble. **Finding F1-4:** a JSON parser's locals overflowed the 1 KB TUD
    task stack (ENXIO on CDC1) — fixed with static buffers + a 512-word TUD stack.
  - [x] **bounded SPSC UART bridge (CDC0) hardening** — **PASS, HIL-verified** *(2026-06-20)*:
    target→host RX is now interrupt-driven into a 4 KB lock-free SPSC ring (`src/spsc_ring.h` +
    `src/uart_bridge.c`), replacing the polling-into-32B that lost bytes between polls. Host unit test
    `tests/m1/ring_test.c` (6/6); HIL `tests/m1/uart_bridge_hil.py` round-trips via PL011 internal
    loopback (no jumper), 0 drops. Telemetry `urx_drop`/`urx_hw`/`utx_drop` in status.
  - [x] per-interface USB string descriptors (already wired in Gate-2; verified) + non-blocking host→target
    TX (replaced uart_write_blocking) + error-code/goto-cleanup idiom codified (`docs/firmware-conventions.md`). *(2026-06-20)*
  - [x] **Watchdog armed-by-default** *(2026-06-20)*: monitors TUD (DAP can't starve it); proven to FIRE on a
    real wedge (`watchdog_hil.py`) and NOT false-fire under 25-flash DAP soak (`watchdog_soak.py`).
- [~] **M2 SD + black-box logging** — IN PROGRESS (`firmware/c/tests/m2/M2_RESULTS.md`).
  - [x] **SD bring-up gate** — **PASS, HIL-verified** *(2026-06-20)*: carlk3 FatFs v3.6.2 (fetched by
    setup.sh) on SPI0 GP2/3/4/CS28, low-prio SD task; `{"q":"sd"}` → mount+write+readback OK on a real
    16 GB FAT32 card; DAP binds, M1 regression green. Heap trimmed 64→44 KB (FreeRTOSConfig overlay) to
    fit FatFs under copy_to_ram. RTC confirmed PCF8563 (not PCF85063A).
  - [x] **recorder core** (`src/recorder.c` + `tests/m2/recorder_test.c`) — **PASS, host-tested** *(2026-06-20)*:
    pure logic behind a `recorder_hw_t` vtable (naming/flush/visible-stop/wedge/triggers/freeze/heartbeat/
    throughput/RTC), 31/31 host checks + verify-the-verifier. Not yet wired to the firmware (increment 3).
  - [x] **wire to HW** — **PASS, HIL-verified** *(2026-06-20)*: 2nd SPSC ring + cdc_task tee + low-prio
    recorder→SD; `{"q":"rec"}`/`{"q":"tail"}`. Clean payload + heartbeat + WEDGE+freeze on the card
    (log_007), session# increments across reboots, DAP intact. Fixed a real bug: probe stdio was on GP0
    (bridge TX) polluting the target line — removed stdio_uart_init + the Gate-1 dashboard printf.
  - [x] **RAM-headroom pass** — **DONE, HIL-verified** *(2026-06-20)*: 98%→87% (−30 KB, free SRAM
    4.5→34 KB). ffconf overlay (exFAT/LBA64/mkfs/expand off → ff.c 46→29 KB) + dropped unused SDIO
    (~11 KB, SPI-only + 2 stubs) + heap 44→34 KB. FatFs/recorder/M1 all verified intact. copy_to_ram kept.
  - [x] **copy_to_ram → XIP (big RAM lever)** — **DONE, HIL-verified** *(2026-06-20)*: dropped
    `copy_to_ram` (one CMake line → `pico_set_binary_type default`); code runs from flash XIP. No
    `__not_in_flash_func` pinning needed (SWCLK is PIO-generated, hot path stays in the 16 KB XIP cache).
    **Free SRAM 35 → 174 KB (+139 KB)** for M3. Full re-gate green: probe-rs 1000/1000 + openocd 200/200
    (0/0), throughput +2.6 % (noise), crash box (PC now in flash 0x10xx) + watchdog HIL pass, M2 SD intact.
    See `tests/m2/M2_RESULTS.md` "copy_to_ram → XIP".
  - [x] **PCF8563 RTC — wall-clock log stamps** — **DONE, HIL-verified** *(2026-06-20)*: PCF8563 @0x51
    on I2C1, new `src/rtc_pcf8563.{c,h}` + `src/i2c1_bus.{c,h}` (shared-bus mutex closing the OLED↔RTC
    race); `hw_rtc_read` wired → recorder stamps wall-clock; CDC1 `{"q":"time"}`/`{"q":"settime"}`.
    `tests/m2/rtc_hil.py`: set→tick→reboot→new session header `start 2026-06-20 21:59:32` (not `+0s`).
  - [x] **SD-write-during-flash coexistence soak** (heavy R1 proof) — **DONE (recorder PASS; DAP caveat
    documented)** *(2026-06-20)*: device-side load generator (`{"q":"recgen_on"}`, ~33 `f_sync`/s) so the
    host only runs probe-rs (isolates SD-vs-DAP from host USB contention). 300 cycles: recorder FLAWLESS
    (err=0, logging=1, wedge=0, rec_drop=0, 761 KB written, content intact). DAP: 6/600 vs 0/600
    standalone — ~1 % retryable (0-stall) USB-transfer errors from background SD-DMA bus contention, ONLY
    under continuous-max-SD overlap that the real flow avoids (flashing halts the target → its UART/
    recording pauses). M3+ mitigation noted (defer SD flush during DAP flash). See `tests/m2/coexist_soak.py`
    + M2_RESULTS.md.
- [x] **M2 SD + black-box logging — COMPLETE** *(2026-06-20)*: SD gate · recorder core (host 31/31) ·
  HW wiring · RAM-headroom (copy_to_ram→XIP, +139 KB) · PCF8563 RTC wall-clock stamps · coexistence soak.
- [x] **M3 core screens — COMPLETE** *(2026-06-21)* (`firmware/c/tests/m3/M3_RESULTS.md`). Design of record =
  `m3-design` workflow; closed by `m3-closeout-audit` (COMPLETE-WITH-NITS, all silent-passes fixed). The probe
  is a reactive Tamagotchi-style dashboard (cat + 6 screens + buzzer/NeoPixel event feedback) that stays
  R1-clean while flashing targets. Future graphics rewrite plan: `docs/hackagotchiUI_upgrade_v1.1.md`.
  - [x] **M3.0 HW-reconciliation + snapshot boundary** — **PASS, HIL-verified** *(2026-06-20)*:
    `src/feedback.{c,h}` + `src/ws2812.pio` (non-blocking buzzer GP29 + **WS2812 NeoPixel** GP12/GP11
    status LED via PIO/pio1, serviced off the hot path) + `{"q":"beep"}`/`{"q":"led"}`/`{"q":"pixel"}`.
    Buzzer PASS; **NeoPixel PASS** (RED/GREEN/BLUE/WHITE all correct). **Finding M3-1:** the onboard RGB
    GP17/16 is an unreliable status channel (color ≠ nominal + competes w/ the GP25 USB-heartbeat) → use
    the NeoPixel. No button (GP27=SWDIO) → input is auto-cycle + CDC1; external buttons/LEDs later. Published
    `rec_snapshot_t` (single-writer seqlock, SD task) + `dash_get_rec_snapshot()` + `recorder_copy_tail()`
    + cached RTC; **fixed the pre-existing `{"q":"rec"}` cross-task race** (live `g_rec.filename` pointer +
    off-task `hw->sd_mounted()`). Gates: DAP binds, `{"q":"rec"}`×80 0 torn, **coexist soak 0/400 + rec_drop=0**.
  - [x] **M3.1 screen framework + first screen** — **PASS, HIL-verified** *(2026-06-21)*: multi-screen
    renderer (screen table + reader-clamped index, auto-cycle 6s + CDC1 `next`/`prev`/`{"q":"screen","n"}`).
    Screen fns emit a TEXT MODEL drawn to the OLED AND published for **self-attestation** (`{"q":"screen"}`
    returns the exact rendered text + a **show-success counter distinct from the loop counter** so a dark
    panel can't pass). Screens: PROBE/home + RECORDER (snapshot-fed). `screen_hil.py` PASS (nav, auto-cycle,
    OOB clamp no-hardfault, shows==loops climbing); operator confirmed both screens cycling; R1 re-soak 0/0.
  - [x] **M3.2 full feasible screen family + cat** — **PASS, HIL-verified** *(2026-06-21)*: 6 screens —
    HOME/mascot (the **cat** ported pixel-for-pixel: idle/blink/sleep+Z / active eyes+mouth+bubble+particles
    / yawn) · SNIFFER (live UART tail) · RECORDER · THROUGHPUT (sparkline) · WATCHDOG (freeze-frame) · CLOCK
    — all snapshot-fed (no direct g_rec/freeze/RTC from DASH). `screen_hil.py` PASS + live-data run (cat
    active, sniffer streaming, throughput 2.9K/s); operator confirmed render; R1 re-soak 120cyc 0/0 rec_drop=0.
    Dropped (pin conflict): scope/PWM/logic/I2C-scan. Deferred M4: macro/baud/SD-explorer, hex-sniffer.
  - [x] **M3.3 event feedback + closeout** — **PASS, HIL-verified** *(2026-06-21)*: `drive_feedback()` in
    sd_gate.c maps recorder events (wedge→alarm+red, SD-fault→buzz+red, trigger-hit→blip, recovery→chirp+
    green, boot chirp) to the buzzer + NeoPixel, edge-detected, off the hot path. `feedback_hil.py` asserts
    the HAL layer via `{"q":"fb"}` (beep count + colour). **Adversarial closeout audit** (`m3-closeout-audit`)
    = COMPLETE-WITH-NITS; fixed every silent-pass: show-counter now ACK-gated (ssd1306_show returns I2C
    status); `{"q":"time"}`/`{"q":"settime"}` rerouted off the above-DAP TUD task (snapshot read + SD-task
    apply); filename check de-tautologised; auto-cycle test hardened. probe-active DEFERRED with a recipe.
    Final coexist R1 soak 0/0 rec_drop=0.
- [x] **Post-M3: drop RTC, I2C1 → FM+ 1 MHz single-owner, remove the bus mutex** — **PASS, HIL-verified**
    *(2026-06-21)*: per user, the product needs no wall-clock. Deleting the PCF8563 left the OLED the sole
    I2C1 device (dashboard-only), so the mutex + `i2c1_bus_lock/unlock` + `{"q":"time"}`/`{"q":"settime"}`
    are gone; `rtc_read=NULL` → recorder stamps uptime (`+Ns`); screen 5 CLOCK→UPTIME; I2C1 at 1 MHz.
    `screen_hil`/`feedback_hil` PASS (shows==loops at 1 MHz), coexist R1 = 0 stalls/300 ops, OLED visually
    crisp at FM+. Simplifies the OLED path ahead of M4. See M3_RESULTS.md "Post-M3 simplification".
- [x] **M4 full UI parity** — **COMPLETE, HIL-verified** *(2026-06-21, commits 792b84f..00dcaa4)*: hex
    sniffer · macro sender · baud select · SD explorer · settings persistence — all CDC1-driven + snapshot-
    fed (no button), tool screens excluded from auto-cycle, config persisted to config.txt on SD. Adversarial
    closeout (SPSC inject/baud/open-log read confirmed safe; fixed a do_ls_read OOB on a long filename,
    restored the soak's hard 8% ceiling, disclosed a benign hg_config torn-read). R1: 0 stalls every soak;
    retryable DAP-fail rate ~1%->~4% idle-host (XIP-layout, accepted "don't gold-plate"). See M4_RESULTS.md.
    Confirmatory clean soak (both boards power-cycled): PROBE PASS — 0 stalls, flash succeeded every cycle;
    the 13/300 (4.3%) are retryable host/USB hiccups, not flash-fails or probe faults. Recorder flawless.
    Finding: this target board re-glitches its QSPI under sustained hammering (power-cycle between long runs);
    orthogonal to the probe firmware (0 stalls every run).
- [~] **M5 polish + tagged release** (.uf2 + .elf) — IN PROGRESS *(2026-06-21)*: version compiled in
  (`{"q":"status"}` `ver`), licensing/NOTICE bundle + SPDX, CHANGELOG, `docs/release-readiness.md`
  evidence index, CI ships NOTICE/LICENSE. "CI green" = the AUTOMATED checks CI can run (build +
  `analyze.sh` static analysis); the HIL gates are operator-attested on the release image (CI cannot run
  hardware). Remaining: README/CONTRIBUTING upgrade, the operator Gate-2 bench run, then `git push` + dispatch.
- [ ] **Raise the reliability stack further** over time (per user) — more host tests, HIL CI,
  tighter analyzers, RTT observability.

## Next — post-v1.0 backlog (ranked, 2026-06-22)

Prioritised from a survey→propose→rank pass over the current tree (value / effort / R1-risk / fit). Item
**#1 (host-tests CI) is DONE** — see Housekeeping above. The rest, best-first:

- [~] **(2) DAP transfer/health telemetry in `{"q":"status"}`** — value HIGH / effort S / risk MED *(touches the DAP path → re-gate before shipping)*.
  A monotonic `dap_xfers` + a coarse last-active stamp, giving the headline "0 stalls" invariant a
  firmware-side witness so every soak is self-cross-checkable (xfers advanced by the expected count).
  - [x] **Implemented on branch `feat/dap-health-telemetry`** *(2026-06-22, commit 5183048)*, **desk-verified
    only**. NOTE — the TODO's "++ in our overlay `main.c`" premise was wrong: with `THREADED=1` the active
    DAP path is upstream `tusb_edpt_handler.c::dap_thread` calling `DAP_ExecuteCommand`, not the dead
    `while(!THREADED)` loop. Wired instead via `-Wl,--wrap=DAP_ExecuteCommand` → `__wrap_DAP_ExecuteCommand`
    in a new owned `src/dap_health.{c,h}` (counters single-writer/lock-free; non-blocking `++` + `time_us_32`).
    This keeps the upstream re-diff surface at **zero** (no `tusb_edpt_handler.c` shadow → clean for the #8
    v2.3.1 spike). Surfaced in `write_status()` (`dap_xfers`/`dap_idle_ms`; buffer 256→320) + host CLI.
    Builds clean, `analyze.sh` PASS (`dap_health.c`+`cdc1_control.c` 0/0), disasm confirms `dap_thread→__wrap→real`.
  - [ ] **GATE before merge to main (needs the bench):** `gate1_soak.sh 1000` (0 fails + 0 stalls) +
    `coexist_soak.py 300` (0 stalls AND unchanged retryable rate), cross-checking that `dap_xfers` advanced
    by ~the soak's transfer count. Runs AT DAP priority — do not merge until green.
  - [ ] Follow-up (nobody proposed it): a companion `dap_retries` counter + a soak that ASSERTS the retryable
    rate stays under the documented ceiling — turns the central carried caveat into a guarded bound.
- [ ] **(3) BOM + narrative build/flash guide** — value HIGH / effort M / risk low *(pure docs)*.
  `docs/build-a-hackagotchi.md`: a real Bill of Materials (XIAO RP2040, expansion board, SSD1306 OLED,
  microSD, passive buzzer, WS2812, SWD/UART jumpers, filament — with qty/links/approx cost), a step-by-step
  assembly procedure, the consolidated pin map, and an **as-shipped vs case-docs reconciliation** callout:
  the case docs (`case/HACKAGOTCHI_CASE.md`, `CAT_ENCLOSURE_SPEC.md`) still enclose the *dropped* PCF8563 RTC
  + CR1220 coin cell + user button, GP27 became SWDIO, and the `.scad` models no cutout for the NeoPixel the
  firmware drives. This is the single biggest *physical*-reproducibility blocker today.
- [ ] **(4) Close Gate 2 deferral (a) — node-map stability** — value MED / effort S / risk low *(needs bench)*.
  The only genuinely-incomplete gate item in the tree (every other verdict is PASS; this one has had just one
  incidental cycle effectively pass). Tooling already exists: run `tests/gates/gate2_cdc.py --replug-rounds 4`
  (3× operator replug + 1 reboot, re-discover the control port by behaviour each time), record the verdict in
  `GATE_RESULTS.md` + `release-readiness.md`. Cheapest un-attested→attested conversion available.
- [~] **(5) Cut a tagged v1.1** for the shipped-but-unreleased M-UI overhaul — value HIGH / effort M / risk low.
  The Spectre ghost + sprite engine is the README's headline ("a debug probe with a soul"), but the only
  downloadable release (v1.0) predates ALL of it — anyone flashing the latest release gets a product that
  doesn't match the README.
  - [x] **Desk half DONE** *(2026-06-22)*: CHANGELOG `[Unreleased]` → `[1.1] - 2026-06-22` (marked
    candidate, pending HIL+publish), `docs/RELEASE_NOTES_v1.1.md` written, README doc fixes folded in
    (`{"q":"fb"}` added; `{"q":"ghost"}` no-arg auto-reset documented). **Candidate built + gated:**
    `VERSION=1.1.0 BUILD_DIR=/tmp/hg-v110 ./build_fork.sh` → text 173876 / bss 84304; `analyze.sh` PASS
    (pristine `hackagotchi_dashboard.c`/`cdc1_control.c` 0/0); `.elf` self-reports `1.1.0`.
  - [ ] **Bench half (operator)**: flash the candidate, re-attest the relevant HIL (the M-UI surfaces —
    `m3/screen_hil`, `m3/feedback_hil`, `m4/*`, plus `{"q":"fb"}`/`{"q":"ghost"}` behaviour) + a Gate-1
    0-stall re-soak, record in `release-readiness.md`, then tag **`v1.1`** at the release commit and
    publish (build with `VERSION=1.1.0` for the byte-identical `.uf2`). Plan the tag deliberately — GitHub
    immutable-releases permanently burns a tag name once a release uses it (it already forced v1.0.0 → v1.0);
    drop the "candidate" line from the CHANGELOG v1.1 entry on publish.
  - [ ] *Optional hardening:* a `verify-release.sh` that rebuilds from the tag and diffs the `.uf2` sha256
    against the published artifact (the "byte-identical rebuild" claim is currently unscripted).
- [ ] **(6) Host-CLI convenience wrappers + packaging** — value MED / effort M / risk low *(host-only, can't touch R1)*.
  `host/hackagotchi_ctl.py` wraps only ~6 of ~30 CDC1 verbs. Add thin subcommands for the high-value ones that
  today require hand-echoing JSON: `bootsel` (THE documented hands-free reflash path — handle the no-reply
  re-enumeration), `baud`, `sd ls/cat`, `lastfault`/`dump`, `macro`. Ship a pinned `requirements.txt`
  (pyserial, Pillow) + a venv bootstrap + `host/README.md` — every doc says `.venv/bin/python` but nothing
  creates it (guaranteed first-command stumble for a new contributor).
- [ ] **(7) Recorder lifecycle + SD housekeeping over CDC1** — value MED / effort M / risk low.
  `rec_start`/`rec_stop`/`rec_rotate`, `rm` by index, `rec_reset` (zero `rec_drop`/`faults`/`revived`), all via
  the established async-post-to-single-owner-SD-task pattern (structurally off the DAP path), reflected through
  `rec_snapshot_t` so the recorder screen updates live. "SD full" is a reachable, already-surfaced state with
  no way to act on it today (you must pull the card). Also adds the missing `{"q":"fb"}` to the README table.
- [ ] **(8) Spike debugprobe-v2.3.1 (post-#189 fix) through Gate 1** — value MED / effort L / risk MED *(needs bench)*.
  The project's own documented next upstream step (Risk R10 / `upstream-strategy.md` §1) and biggest
  anti-fossilisation lever; Gate 1 passing was the precondition, now met. Re-diff only the 3 shadowed overlay
  files (`main.c`/`cdc_uart.c`/`usb_descriptors.c`) against the new base, build to a separate `BUILD_DIR`, run
  `gate1_soak.sh >=1000` reading the authoritative 0-stall verdict line, write a falsifiable rebase-or-stay
  verdict. Don't rebase the product unless 0 stalls. Fold in the 5-minute fix: an `engineering-plan §4.1`
  "SUPERSEDED — single-core, see Finding F1-1" banner so the stale SMP/dual-core text stops misleading the
  future rebaser.

Minor doc-debt, worth a line when working nearby: (a) document WHY `main.c:243 tud_hid_get_report_cb` is
intentionally a no-op (the only genuine code TODO in the tree — the active DAP path is vendor/bulk and
`set_report` IS wired), so it stops reading as unfinished work; (b) a one-paragraph "where the plan of record
lives" pointer (engineering-plan = plan of record, this file = live checklist, CHANGELOG = shipped) to ease
onboarding given there's no single `ROADMAP.md`.

## Upstream (see `docs/upstream-strategy.md`)
- [ ] Track official **debugprobe stable tags**; after Gate 1 is green on v2.2.3, spike `v2.3.1`
  through the soak and rebase the overlay if it passes.
- [ ] Cherry-pick from yapicoprobe (verify license + add tests): **MSC drag-n-drop UF2 flash**,
  **RTT-into-CDC** (both HIGH, post-Gate-2).
- [ ] **Contribute upstream:** fix yapicoprobe **#197** (build broken on modern GCC) as a first
  PR; propose an umbrella LICENSE; pursue the co-maintainer path.

## Housekeeping
- [x] **LICENSE chosen** *(2026-06-20)*: project GPL-3.0-or-later (root `LICENSE`); the `firmware/c/`
  subtree MIT (`firmware/c/LICENSE`). Third-party deps (all permissive MIT/BSD-3/Apache) attributed in
  both `THIRD-PARTY-NOTICES.md`; SPDX tags on first-party sources.
- [ ] Vendor `sdcard.py` into `firmware/micropython/lib/` (currently a noted gap).
- [x] **Org remote** set: `git@github.com:GhostRoboticsLab/Hackagotchi.git`.
- [x] CI/CD: `.github/workflows/firmware-c.yml` — manual-dispatch build (setup.sh + build_fork.sh,
  pinned Arm GCC 13.3 via the self-hosted runner's fw-build cache) + the `analyze.sh` static-analysis
  gate + .uf2/.elf artifacts + optional Release (`engineering-plan.md` §7). *Untested until the org
  remote + a workflow run exist.*
- [x] **Host-tests CI job** *(2026-06-22)*: `.github/workflows/host-tests.yml` — GitHub-HOSTED
  (ubuntu-latest), push/PR, compiles + runs the three portable unit tests (`ring_test`, `recorder_test`,
  `blit_test`) with plain `cc`, and each test's verify-the-verifier break build (asserts the harness can
  FAIL). The repo's first community-runnable green check; the badge now means "portable logic verified per
  PR", not just "it builds". Done as plain `cc` rather than the originally-planned Ceedling — same coverage,
  no extra dep. (This is item #1 of the post-v1.0 backlog below.)

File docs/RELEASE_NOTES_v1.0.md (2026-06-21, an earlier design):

## Hackagotchi probe firmware — v1.0 🛠️🐾

First public release. A **debug probe that's also a black-box flight recorder and a
Tamagotchi-style dashboard** for dev boards that go dark — a fork of Raspberry Pi
`debugprobe` (v2.2.3) that does all three on one RP2040 **without ever stalling a flash**
(0 DAP transfer stalls under load, proven on hardware).

### What's in it
- 🔌 **SWD debug probe** (CMSIS-DAP) — halt / erase / reflash an RP2040 target with probe-rs or OpenOCD
- 📼 **UART black-box recorder** to microSD — session logs, heartbeats, and a freeze-frame of the target's last words on a wedge
- 🐾 **Reactive OLED dashboard** — a cat mascot + 6 live screens, with buzzer + NeoPixel event feedback
- 🧰 **JSON control over USB** (CDC1) — hex sniffer, macro sender, runtime baud, SD explorer, hands-free reflash
- 🛡️ **Reliability core** — crash box, software watchdog, lossless UART bridge; runs from flash XIP (+139 KB SRAM)

### Flash it (no toolchain needed)
1. Download **`hackagotchi_probe.uf2`** below.
2. BOOTSEL the XIAO: hold **B**, tap **R**, release **B** → an `RPI-RP2` drive mounts.
3. `picotool load -x hackagotchi_probe.uf2` (or drag the `.uf2` onto the drive).
4. Confirm — send `{"q":"status"}` to the control serial port → `{"fw":"Hackagotchi","ver":"1.0.0",…}`.

### Assets
`hackagotchi_probe.uf2` · `hackagotchi_probe.elf` (to symbolicate crash dumps) · `THIRD-PARTY-NOTICES.md` · `LICENSE`

### Notes
- The firmware reports its own version live (`{"q":"status"}` → `ver`).
- Verified on this image: build + static-analysis gate + full HIL suite — see `docs/release-readiness.md`.
- **License:** project GPL-3.0-or-later; the `firmware/c/` subtree MIT. All dependencies permissive (MIT / BSD-3 / Apache-2.0).
- ⚠️ Under an *artificial* continuous-max-SD soak, retryable (0-stall) DAP errors can appear — ~0 in real use (the target is halted during a real flash). Run soaks on an idle host.

📓 Full changelog: `CHANGELOG.md` · 🔧 build from source: `docs/c-firmware-build.md`

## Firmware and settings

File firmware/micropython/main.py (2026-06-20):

# Hackagotchi — a black-box flight recorder for dev boards that go dark.
# Copyright (C) 2026 GhostRoboticsLab and the Hackagotchi authors.
#
# SPDX-License-Identifier: GPL-3.0-or-later
#
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
import sys
import select
import time
import json
import math
from machine import UART, Pin, SoftI2C, ADC, PWM, time_pulse_us, reset

# ----------------- LED Setup -----------------
# Onboard user LEDs: GP25 (Blue), GP26 (Green), GP17 (Red). Active-low (0=ON, 1=OFF).
blue_led = Pin(25, Pin.OUT)
green_led = Pin(26, Pin.OUT)
red_led = Pin(17, Pin.OUT)

def set_leds(r, g, b):
    red_led.value(0 if r else 1)
    green_led.value(0 if g else 1)
    blue_led.value(0 if b else 1)

# Solid blue status during startup
set_leds(False, False, True)

# ----------------- Passive Buzzer Setup -----------------
# Buzzer is on GP29 (D3)
def beep(freq, ms):
    try:
        pwm = PWM(Pin(29))
        pwm.freq(freq)
        pwm.duty_u16(3000)
        time.sleep_ms(ms)
        pwm.duty_u16(0)
        pwm.deinit()
    except Exception:
        pass

# Boot indicator tone
beep(1500, 40)
time.sleep_ms(60)
beep(2200, 40)

# ----------------- User Button Setup -----------------
# Shield USER button is on GP27 (D1), active-low
button = Pin(27, Pin.IN, Pin.PULL_UP)

# ----------------- SSD1306 OLED Setup -----------------
oled_present = False
oled = None
try:
    import ssd1306
    # SCL is on GP7 (D5), SDA is on GP6 (D4).
    # Initialize I2C at 400kHz for rapid page updates.
    i2c = SoftI2C(scl=Pin(7), sda=Pin(6), freq=400000)
    if 0x3C in i2c.scan():
        oled = ssd1306.SSD1306_I2C(128, 64, i2c, addr=0x3C)
        oled_present = True
        print("OLED found and initialized at 0x3C.")
    else:
        print("OLED not found in I2C scan.")
except Exception as e:
    print("OLED configuration failed:", e)

# ----------------- Compact 5x7 font (data-dense screens) -----------------
# The built-in framebuf font is locked at 8x8 (16 cols x 8 rows, no scaling). To pack
# more onto the text-heavy screens (sniffer/hex, SD viewer, probe sidebar) we ship the
# canonical 5x7 "glcdfont": 5 column bytes per glyph, bit0 = top row .. bit6 = row 7.
# At a 6px advance that's 21 cols across 128px. Titles/menus keep the legible 8x8 font.
_F5x7 = bytes.fromhex(
    "0000000000"  # 0x20 space
    "00005f0000"  # !
    "0007000700"  # "
    "147f147f14"  # #
    "242a7f2a12"  # $
    "2313086462"  # %
    "3649552250"  # &
    "0005030000"  # '
    "001c224100"  # (
    "0041221c00"  # )
    "14083e0814"  # *
    "08083e0808"  # +
    "0050300000"  # ,
    "0808080808"  # -
    "0060600000"  # .
    "2010080402"  # /
    "3e5149453e"  # 0
    "00427f4000"  # 1
    "4261514946"  # 2
    "2141454b31"  # 3
    "1814127f10"  # 4
    "2745454539"  # 5
    "3c4a494930"  # 6
    "0171090503"  # 7
    "3649494936"  # 8
    "064949291e"  # 9
    "0036360000"  # :
    "0056360000"  # ;
    "0008142241"  # <
    "1414141414"  # =
    "4122140800"  # >
    "0201510906"  # ?
    "324979413e"  # @
    "7e1111117e"  # A
    "7f49494936"  # B
    "3e41414122"  # C
    "7f4141221c"  # D
    "7f49494941"  # E
    "7f09090901"  # F
    "3e4149497a"  # G
    "7f0808087f"  # H
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
    "0204081020"  # backslash
    "0041417f00"  # ]
    "0402010204"  # ^
    "4040404040"  # _
    "0001020400"  # `
    "2054545478"  # a
    "7f48444438"  # b
    "3844444420"  # c
    "384444487f"  # d
    "3854545418"  # e
    "087e090102"  # f
    "0c5252523e"  # g
    "7f08040478"  # h
    "00447d4000"  # i
    "2040443d00"  # j
    "7f10284400"  # k
    "00417f4000"  # l
    "7c04180478"  # m
    "7c08040478"  # n
    "3844444438"  # o
    "7c14141408"  # p
    "081414187c"  # q
    "7c08040408"  # r
    "4854545420"  # s
    "043f444020"  # t
    "3c4040207c"  # u
    "1c2040201c"  # v
    "3c4030403c"  # w
    "4428102844"  # x
    "0c5050503c"  # y
    "4464544c44"  # z
    "0008364100"  # {
    "00007f0000"  # |
    "0041360800"  # }
    "0804081008"  # ~
)


def text_small(oled, s, x, y, c=1):
    # Render a string in the 5x7 font (6px advance). Clips at the right edge so a long
    # line never wraps into the next row. Falls back to blank for chars outside 0x20-0x7E.
    for ch in s:
        o = (ord(ch) - 0x20) * 5
        if 0 <= o <= len(_F5x7) - 5 and x + 5 <= 128:
            for col in range(5):
                bits = _F5x7[o + col]
                px = x + col
                yy = y
                while bits:
                    if bits & 1:
                        oled.pixel(px, yy, c)
                    bits >>= 1
                    yy += 1
        x += 6
        if x >= 128:
            break

# ----------------- SD Card Setup -----------------
sd_present = False
sd_mounted = False
sd_card_obj = None

def mount_sd():
    global sd_present, sd_mounted, sd_card_obj
    if sd_mounted:
        return True
    try:
        from machine import SPI
        import sdcard
        import os
        # CS on GP28 (D2), SPI0 on GP2 (D8), GP3 (D9), GP4 (D10)
        cs = Pin(28, Pin.OUT, value=1)
        spi = SPI(0, baudrate=10000000, polarity=0, phase=0, sck=Pin(2), mosi=Pin(3), miso=Pin(4))
        sd_card_obj = sdcard.SDCard(spi, cs)
        os.mount(sd_card_obj, "/sd")
        sd_mounted = True
        sd_present = True
        print("SD Card mounted successfully at /sd")
        return True
    except Exception as e:
        sd_mounted = False
        sd_card_obj = None
        print("SD Card mount failed:", e)
        return False

def unmount_sd():
    global sd_mounted, sd_card_obj
    if not sd_mounted:
        return True
    try:
        import os
        os.umount("/sd")
        sd_mounted = False
        sd_card_obj = None
        print("SD Card unmounted successfully.")
        return True
    except Exception as e:
        print("SD Card unmount failed:", e)
        return False

def ensure_sd_pins():
    if not sd_mounted:
        return False
    try:
        from machine import SPI
        Pin(28, Pin.OUT, value=1)
        SPI(0, baudrate=10000000, polarity=0, phase=0, sck=Pin(2), mosi=Pin(3), miso=Pin(4))
        return True
    except Exception:
        return False

# Attempt to mount SD card at boot
mount_sd()

_fx_trans_n = 0
def trigger_transition_wipe():
    # Multi-style screen transition; cycles each call for variety. Runs only on a screen
    # change, so the brief blocking (~6 OLED frames) never disrupts steady-state bridging.
    global _fx_trans_n
    if not (oled_present and oled is not None):
        return
    try:
        _fx_trans_n = (_fx_trans_n + 1) % 3
        if _fx_trans_n == 0:
            # Curtain: black closes in from both edges to the centre, lit leading rules.
            for x in range(0, 65, 11):
                oled.fill_rect(0, 0, x, 64, 0)
                oled.fill_rect(128 - x, 0, x, 64, 0)
                oled.vline(min(x, 127), 0, 64, 1)
                oled.vline(max(0, 127 - x), 0, 64, 1)
                oled.show()
        elif _fx_trans_n == 1:
            # Venetian blinds: 8 horizontal bands wipe down together.
            for h in range(2, 10, 2):
                for by in range(0, 64, 8):
                    oled.fill_rect(0, by, 128, min(h, 8), 0)
                oled.show()
        else:
            # Vertical scan-wipe: black sweeps left->right behind a bright scan bar.
            for x in range(0, 129, 22):
                oled.fill_rect(0, 0, x, 64, 0)
                if x < 128:
                    oled.fill_rect(min(x, 126), 0, 2, 64, 1)
                oled.show()
        oled.fill(0)
        oled.show()
    except Exception:
        pass

# ----------------- Persistent Config -----------------
def load_bridge_cfg():
    cfg = {"baud": 115200, "macros": ["AT", "PING", "STATUS", "RESET", "HELP", "HELLO"]}
    try:
        with open("bridge_cfg.json") as f:
            cfg.update(json.load(f))
    except Exception:
        pass
    return cfg

def save_bridge_cfg(cfg):
    try:
        with open("bridge_cfg.json", "w") as f:
            json.dump(cfg, f)
    except Exception:
        pass

bridge_cfg = load_bridge_cfg()

# ----------------- UART Setup -----------------
BAUDRATES = [9600, 19200, 38400, 57600, 115200]
BAUDRATE = bridge_cfg["baud"]
if BAUDRATE not in BAUDRATES:
    BAUDRATE = 115200

# Initialize hardware UART0. GPIO 0 = D6 (TX), GPIO 1 = D7 (RX).
uart = UART(0, baudrate=BAUDRATE, tx=Pin(0), rx=Pin(1), rxbuf=8192, txbuf=1024)

# Register polling handles
poll = select.poll()
poll.register(sys.stdin, select.POLLIN)
poll.register(uart, select.POLLIN)

# ----------------- Global State -----------------
# 0: Mascot/Stats, 1: Sniffer, 2: I2C Scanner, 3: Oscilloscope, 4: GPIO Monitor,
# 5: PWM Gen/Meter, 6: Macro Sender, 7: Baud rate menu, 8: Demo Trigger menu,
# 9: SD Explorer, 10: Watchdog (flight recorder), 11: Throughput meter
SCREEN_COUNT = 12
screen = 0
tx_bytes = 0
rx_bytes = 0

# ----------------- Flight-recorder watch state -----------------
# These run as ALWAYS-ON background monitors (not just when their screen is visible) -- the
# whole point of a black box. The Watchdog screen (10) surfaces the detail; the alerts fire
# globally (beep + LED + a log mark + a blinking header badge) wherever you are.
watch_terms = [str(t)[:14] for t in bridge_cfg.get("watch", ["ERROR", "FATAL", "Traceback", "panic", "BUSY-TIMEOUT"])]
watch_hits = 0
watch_last = ""            # last matched term + a snippet
_watch_line = ""           # RX line accumulator for substring matching
ever_active = False        # have we ever seen target traffic? (don't flag a wedge before)
last_rx_t = 0              # ticks_ms of the last received byte
wedge_active = False       # target went silent after being active = a wedge
wedge_since = ""           # wall-clock / uptime stamp when the wedge was detected
WEDGE_SILENCE_MS = 8000    # silence after activity that counts as a wedge
freeze_frame = bytearray() # rolling last ~96 bytes -- the target's dying words
alert_until = 0            # ticks_ms until the global alert badge stops blinking
alert_text = ""            # short alert label (shown on the Watchdog screen)
# Throughput meter
tp_hist = []               # bytes/sec samples (newest last), capped for the sparkline
tp_accum = 0               # bytes counted since the last 1 s sample
tp_last_t = 0
tp_peak = 0

# ----------------- UART Logger State -----------------
logging_active = False
log_buffer = bytearray()
last_log_write_t = 0
last_bb_hb = 0              # black-box heartbeat timer (stamps the log every 60s)
current_log_filename = "uart_log.txt"
last_log_err = ""          # last logger fault reason (SD FULL / WRITE ERR), shown on-screen

def get_next_log_filename():
    global current_log_filename
    if not sd_mounted:
        current_log_filename = "uart_log.txt"
        return current_log_filename
    try:
        import os
        ensure_sd_pins()
        files = os.listdir("/sd")
        max_idx = 0
        for f in files:
            if f.startswith("log_") and f.endswith(".txt"):
                try:
                    idx = int(f[4:-4])
                    if idx > max_idx:
                        max_idx = idx
                except ValueError:
                    pass
        new_idx = max_idx + 1
        current_log_filename = f"log_{new_idx:03d}.txt"
    except Exception:
        current_log_filename = "uart_log.txt"
    return current_log_filename

def log_uart_data(data):
    global log_buffer, last_log_write_t, logging_active
    if not logging_active or not sd_mounted:
        return
    if isinstance(data, str):
        log_buffer.extend(data.encode())
    else:
        log_buffer.extend(data)
    now = time.ticks_ms()
    if len(log_buffer) >= 64 or (time.ticks_diff(now, last_log_write_t) > 500 and len(log_buffer) > 0):
        flush_log_buffer()

def flush_log_buffer():
    global log_buffer, last_log_write_t, logging_active, current_log_filename, last_log_err
    if len(log_buffer) == 0 or not sd_mounted:
        return
    try:
        import os
        ensure_sd_pins()
        with open("/sd/" + current_log_filename, "ab") as f:
            f.write(log_buffer)
        log_buffer = bytearray()
        last_log_write_t = time.ticks_ms()
    except Exception as e:
        # A write fault stops the recorder, but it must be VISIBLE -- a silent stop on a
        # black box is the worst failure. Distinguish a full card (ENOSPC/errno 28) from a
        # generic write error so the on-screen badge tells the user which to fix.
        es = str(e)
        last_log_err = "SD FULL" if ("28" in es or "ENOSPC" in es or "No space" in es) else "WRITE ERR"
        print("Logger write failed (%s), stopping logger:" % last_log_err, e)
        logging_active = False
        log_buffer = bytearray()
        beep(400, 120)
        time.sleep_ms(60)
        beep(400, 120)      # distinctive low double-buzz = recorder died


# ----------------- RTC (PCF8563, expansion-board I2C @ 0x51) -----------------
# Battery-backed by a CR1220 coin cell, so wall-clock survives power loss. The black
# box stamps its session header + heartbeats with real time when the RTC reads valid;
# with no (or a dead) backup cell the VL flag is set and we fall back to uptime -- the
# log is still useful, just relative instead of absolute.
RTC_ADDR = 0x51


def _bcd(v):
    return (v >> 4) * 10 + (v & 0x0F)


def read_rtc():
    # (Y, mon, d, hh, mm, ss) or None if the RTC is absent or its time is untrusted.
    try:
        d = i2c.readfrom_mem(RTC_ADDR, 0x02, 7)   # sec,min,hr,day,wday,mon,yr (BCD)
        if d[0] & 0x80:                            # VL: integrity lost since last set
            return None
        return (2000 + _bcd(d[6]), _bcd(d[5] & 0x1f), _bcd(d[3] & 0x3f),
                _bcd(d[2] & 0x3f), _bcd(d[1] & 0x7f), _bcd(d[0] & 0x7f))
    except Exception:
        return None


def log_stamp():
    rtc = read_rtc()
    if rtc:
        return "%04d-%02d-%02d %02d:%02d:%02d" % rtc
    return "+%ds (no RTC batt)" % (time.ticks_diff(time.ticks_ms(), boot_ms) // 1000)


def start_logging():
    # Open a fresh session file + write a timestamped header. Returns False if the SD
    # won't mount (caller can buzz an error). The single entry point for every start --
    # boot auto-start, the Screen-9 menu, and the host {"cfg":{"logging":true}} path.
    global logging_active, log_buffer, last_log_err
    if not mount_sd():
        return False
    last_log_err = ""       # fresh session clears any prior fault badge
    get_next_log_filename()
    log_buffer.extend(("\n=== BLACK BOX %s | start %s | baud %d ===\n"
                       % (current_log_filename, log_stamp(), BAUDRATE)).encode())
    logging_active = True
    flush_log_buffer()      # persist the header at once, so a yanked card still has it
    return True


def stop_logging():
    global logging_active
    flush_log_buffer()
    logging_active = False


# Autonomous black box: optionally begin recording at power-on, so an untethered or
# overnight capture runs with nobody around to press START. Enable with
# {"cfg":{"log_on_boot":true}}; default off so we don't fill the card every boot.
if bridge_cfg.get("log_on_boot", False):
    if start_logging():
        print("Black box: auto-logging to", current_log_filename)


def draw_rec_indicator(oled, anim_tick):
    if logging_active and (anim_tick // 4) % 2 == 0:
        oled.fill_rect(92, 2, 4, 4, 1)
        oled.text("REC", 98, 0)


def draw_header(oled, title, anim_tick=0, demo=False, show_rec=False):
    # Slim title bar shared by every screen: title at y=0, divider rule at y=9. The old
    # per-screen idiom (title at y=2, rule at y=11, content at y=14) cost 14px before any
    # content; this costs ~9px, so every screen reclaims ~one content row. Content now
    # starts at y=11. demo/show_rec draw the corner badges the old code did inline.
    oled.text(title, 2, 0)
    if demo:
        oled.text("DEMO", 100, 0)
    elif show_rec:
        draw_rec_indicator(oled, anim_tick)
    oled.hline(0, 9, 128, 1)
    # Global alert badge: a blinking inverted "!" at the top-right while an alert is fresh
    # (a trigger hit or a target wedge). Drawn last so it shows on every screen, over REC.
    if alert_until and time.ticks_diff(alert_until, time.ticks_ms()) > 0 and (anim_tick // 2) % 2 == 0:
        oled.fill_rect(118, 0, 9, 9, 1)
        oled.text("!", 119, 0, 0)


def draw_sparkline(oled, data, x, y, w, h, c=1, baseline=False):
    # Auto-scaled line graph of `data` into the box (x,y,w,h). Reusable by the throughput
    # meter and any screen that wants a trend. Cheap: one line() per sample.
    n = len(data)
    if n == 0 or w < 2 or h < 2:
        return
    lo = min(data)
    hi = max(data)
    rng = (hi - lo) or 1
    if baseline:
        oled.hline(x, y + h - 1, w, c)
    prev = None
    for i in range(n):
        px = x + (i * (w - 1)) // max(1, n - 1)
        py = y + h - 1 - int((h - 1) * (data[i] - lo) / rng)
        if prev is not None:
            oled.line(prev[0], prev[1], px, py, c)
        prev = (px, py)


def draw_progress_bar(oled, x, y, w, h, frac, c=1):
    # Outlined bar filled to `frac` (0..1). Used for confirm timers and meters.
    if frac < 0:
        frac = 0.0
    elif frac > 1:
        frac = 1.0
    oled.rect(x, y, w, h, c)
    fw = int((w - 2) * frac)
    if fw > 0:
        oled.fill_rect(x + 1, y + 1, fw, h - 2, c)


def boot_splash():
    # Animated power-on identity card: the Hackagotchi wordmark wipes in behind a bright scan
    # bar, the underline grows with it, then the tagline + corner brackets settle in. One-shot
    # at boot (the only place a blocking animation is acceptable -- the loop isn't running yet).
    if not (oled_present and oled is not None):
        return
    try:
        title = "Hackagotchi"
        tx0 = 28
        full_w = len(title) * 8
        steps = 16
        for i in range(steps + 1):
            rv = i / steps
            oled.fill(0)
            oled.text(title, tx0, 14)
            cut = tx0 + int(full_w * rv)
            oled.fill_rect(cut, 10, 128 - cut, 18, 0)   # mask the not-yet-revealed tail
            if rv < 1.0:
                oled.fill_rect(min(cut, 126), 10, 2, 18, 1)  # bright leading scan bar
            oled.hline(22, 28, int(84 * rv), 1)          # underline grows with the reveal
            oled.show()
            time.sleep_ms(16)
        for i in range(4):
            oled.fill_rect(0, 34, 128, 30, 0)
            if i >= 1:
                text_small(oled, "black box for boards", 4, 40)
            if i >= 2:
                text_small(oled, "that go dark", 28, 50)
            if i >= 3:
                oled.hline(0, 0, 8, 1);    oled.vline(0, 0, 8, 1)        # top-left
                oled.hline(120, 0, 8, 1);  oled.vline(127, 0, 8, 1)      # top-right
                oled.hline(0, 63, 8, 1);   oled.vline(0, 56, 8, 1)       # bottom-left
                oled.hline(120, 63, 8, 1); oled.vline(127, 56, 8, 1)     # bottom-right
            oled.show()
            time.sleep_ms(140)
        time.sleep_ms(300)
    except Exception:
        pass

# Demo Mode status
demo_mode = bridge_cfg.get("demo_on_boot", False)
last_demo_switch_t = time.ticks_ms() if demo_mode else 0
boot_ms = time.ticks_ms()   # for the Screen 0 uptime stat

# Terminal sniffer history
sniffer_mode = 0  # 0: ASCII scrolling, 1: Hex dump
terminal_lines = ["", "", "", "", "", ""]   # 6 lines x 21 cols (rendered in the 5x7 font)
hex_history = []  # last 30 bytes for hex dump (6 rows x 5 bytes, 5x7 font)

yawn_end_t = 0
last_active_state = False
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

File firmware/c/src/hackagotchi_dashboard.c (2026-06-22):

/*
 * Hackagotchi — M3 OLED dashboard task (multi-screen renderer). SPDX-License-Identifier: MIT
 * See hackagotchi_dashboard.h for the architecture (lowest-prio render, snapshot-only reads, no button).
 *
 * M3.2 ports the full feasible MicroPython screen family (firmware/micropython/main.py): the cat mascot
 * (draw_cat, ported pixel-for-pixel), Home/bridge stats, live-UART sniffer, throughput sparkline,
 * watchdog/flight-recorder, recorder status, and a clock. Screens the static pin map forbids (scope/PWM/
 * logic-analyzer/I2C-scanner) are intentionally absent; the button menus (macro/baud/SD-explorer) are M4.
 *
 * Screen fns draw graphics DIRECTLY to the OLED (the cat/sparkline aren't expressible as text) and ALSO
 * fill a text attestation model. The SHOW-SUCCESS counter (g_dash_shows, ticked only when ssd1306_show()
 * ran) + an operator glance keep the render honest where the text model can't (a dark panel can't pass).
 */

#include <stdio.h>
#include <stdarg.h>
#include <string.h>
#include <pico/stdlib.h>
#include <hardware/i2c.h>

#include "FreeRTOS.h"
#include "task.h"

#include "ssd1306.h"
#include "i2c1_bus.h"
#include "hg_config.h"   // M4: macro list (MACRO screen) + baud (BAUD screen)
#include "sd_gate.h"      // rec_snapshot_t + dash_get_rec_snapshot()
#include "hackagotchi_dashboard.h"
#include "sprites.gen.h"  // M-UI-2: generated 1-bit sprites (status-bar glyphs + ghost vitals states)
#include "hg_input.h"     // v1.2: poll the joystick here (shares the OLED's I2C1 owner -> no mutex)

#ifndef DASH_I2C_ADDR
#define DASH_I2C_ADDR 0x3Cu
#endif
#ifndef ADVERSARIAL_STALL_MS
#define ADVERSARIAL_STALL_MS 0
#endif

#define DASH_I2C_INST   i2c1    // OLED on I2C1 GP6/GP7 (sole device on the bus — no mutex)
#define DASH_REFRESH_MS 250u    // ~4 Hz (proven-safe coexistence rate from Gate 1 / M2 soaks)
#define DASH_CYCLE_MS  6000u    // auto-advance screens every 6 s (no button)
#define DASH_MAX_LINES    8     // attestation text lines (M-UI-2: raised 6->8 so the status-bar BAR
                                //   token + cat/ghost tokens never silently drop a literal fact past
                                //   the cap — the feasibility must-fix; costs ~2*DASH_COLW=44 B static)
#define DASH_COLW        22     // 21 cols @ 6px pitch + NUL
#define TP_RING          60     // throughput sparkline history (bytes/sec samples)

TaskHandle_t dashboard_taskhandle;

volatile uint32_t g_dash_counter   = 0;
volatile uint32_t g_dash_stall_us  = 0;
volatile uint32_t g_dash_shows     = 0;
volatile int32_t  g_dash_screen    = 0;
volatile uint32_t g_dash_stack_free = 0;

// --- navigation intents (posted by CDC1/TUD, consumed here) ---
static volatile int32_t s_nav_delta = 0;
static volatile int32_t s_nav_abs   = -1;
void dash_nav_step(int delta) { __atomic_fetch_add(&s_nav_delta, delta, __ATOMIC_RELAXED); }
void dash_nav_to(int idx)     { __atomic_store_n(&s_nav_abs, idx, __ATOMIC_RELAXED); }

// M4: hex-sniffer view mode (SNIFFER screen toggles ASCII<->hex). Dashboard-local; flipped over CDC1
// {"q":"hex"}. A plain bool is fine — single writer (the CDC1 handler), read by the render loop.
static volatile bool s_hex_mode = false;
bool dash_hex_toggle(void) { s_hex_mode = !s_hex_mode; return s_hex_mode; }
bool dash_hex_mode(void)   { return s_hex_mode; }

// M4.2: last macro index sent over CDC1, marked on the MACRO screen. Single writer (the CDC1 handler).
static volatile int32_t s_macro_last = -1;
void dash_macro_mark(int i) { s_macro_last = i; }

// --- M-UI-5 companion interaction intents (posted by CDC1/TUD, consumed by the render loop) ---
static volatile int32_t  s_ghost_force  = -1;  // -1 auto · 0 banish (absent) · 1 summon (present)
static volatile int32_t  s_char_on      = 1;   // character layer: 1 companion (default) · 0 pure-instrument
static volatile int32_t  s_theme_dense  = 1;   // 1 dense (default) · 0 calm (reduced motion)
static volatile uint32_t s_pet_until    = 0;   // ms deadline for the pet reaction (absolute clock)
static volatile int32_t  s_exorcise_req = 0;   // set by CDC1; armed into the frame countdown by the loop
static int               s_exorcise_frames = 0;// render-loop-owned exorcism dissolve countdown (frames)

void dash_pet(void)            { s_pet_until = (uint32_t)(time_us_64() / 1000ull) + 1500u; }
void dash_ghost_summon(int on) { __atomic_store_n(&s_ghost_force, on, __ATOMIC_RELAXED); }
void dash_char_enable(int on)  { __atomic_store_n(&s_char_on, on ? 1 : 0, __ATOMIC_RELAXED); }
int  dash_char_enabled(void)   { return __atomic_load_n(&s_char_on, __ATOMIC_RELAXED); }
void dash_exorcise(void)       { __atomic_store_n(&s_exorcise_req, 1, __ATOMIC_RELAXED); }
void dash_theme(int dense)     { __atomic_store_n(&s_theme_dense, dense ? 1 : 0, __ATOMIC_RELAXED); }
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

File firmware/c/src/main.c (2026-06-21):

// SPDX-License-Identifier: MIT
/*
 * The MIT License (MIT)
 *
 * Copyright (c) 2021 Raspberry Pi (Trading) Ltd.
 * Copyright (c) 2021 Peter Lawrence
 *
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
 */

/*
 * HACKAGOTCHI FORK OVERLAY of debugprobe-v2.2.3 src/main.c.
 * Diff vs upstream is exactly three additions, each tagged // [HACKAGOTCHI]:
 *   1. #include "hackagotchi_dashboard.h"
 *   2. DASHBOARD_TASK_PRIO / _STACK  (lowest priority — strictly below DAP)
 *   3. xTaskCreate(dashboard_task, ...) in main()'s THREADED block
 * This file shadows upstream's via include order; the fetched upstream tree is left pristine.
 * When bumping the base, diff this against the new upstream main.c.
 */

#include "FreeRTOS.h"
#include "task.h"

#include <pico/stdlib.h>
#include <stdio.h>
#include <string.h>

#if PICO_SDK_VERSION_MAJOR >= 2
#include "bsp/board_api.h"
#else
#include "bsp/board.h"
#endif
#include "tusb.h"

#include "probe_config.h"
#include "probe.h"
#include "cdc_uart.h"
#include "get_serial.h"
#include "tusb_edpt_handler.h"
#include "DAP.h"
#include "hardware/structs/usb.h"
#include "hackagotchi_dashboard.h"   // [HACKAGOTCHI] 1/3
#include "crash_box.h"               // [HACKAGOTCHI] M1 reliability core — post-mortem fault box
#include "watchdog_task.h"           // [HACKAGOTCHI] M1 reliability core — SW watchdog
#include "sd_gate.h"                 // [HACKAGOTCHI] M2 — SD bring-up gate (low-prio SD/FatFs task)
#include "i2c1_bus.h"                // [HACKAGOTCHI] I2C1 bring-up (OLED only, FM+ 1 MHz, no mutex)
#include "feedback.h"               // [HACKAGOTCHI] M3.0 — status LEDs + buzzer (non-blocking HAL)

// UART0 for debugprobe debug
// UART1 for debugprobe to target device

static uint8_t TxDataBuffer[CFG_TUD_HID_EP_BUFSIZE];
static uint8_t RxDataBuffer[CFG_TUD_HID_EP_BUFSIZE];

#define THREADED 1

#define UART_TASK_PRIO (tskIDLE_PRIORITY + 3)
#define TUD_TASK_PRIO  (tskIDLE_PRIORITY + 2)
#define DAP_TASK_PRIO  (tskIDLE_PRIORITY + 1)
// [HACKAGOTCHI] 2/3 — the OLED coexistence task is STRICTLY below DAP so it can never delay the
// probe path (single-core FreeRTOS, configNUM_CORES=1; the only guarantee is priority/preemption).
#ifdef ADVERSARIAL_AT_DAP_PRIO
// ADVERSARIAL-ONLY: run the stress task AT DAP's priority so a busy_wait genuinely TIME-SLICES with
// DAP (defeats the "preempted in ~50us" no-op). This is NOT a product config — it deliberately
// violates the strict-below-DAP rule to probe DAP's buffer-handoff under real contention.
#define DASHBOARD_TASK_PRIO  (tskIDLE_PRIORITY + 1)
#else
#define DASHBOARD_TASK_PRIO  (tskIDLE_PRIORITY + 0)
#endif
#define DASHBOARD_TASK_STACK 1024

// [HACKAGOTCHI] M1: the SW-watchdog health task runs at the HIGHEST app priority so it is never
// starved (it must feed the HW WDT on time) and can preempt a wedged lower task to record the reason.
// It sleeps ~all the time (500 ms cycle, microseconds of work), so the cost to UART/DAP is negligible.
#define WD_TASK_PRIO (tskIDLE_PRIORITY + 3)

// [HACKAGOTCHI] M1: the TUD task runs tud_cdc_rx_cb (the CDC1 JSON control handler) on its own stack,
// on top of TinyUSB's own call depth. configMINIMAL_STACK_SIZE (256 words) is too tight once the
// handler adds JSON locals — give TUD headroom. (Reply/token buffers are also moved off-stack.)
#define TUD_TASK_STACK 512

TaskHandle_t dap_taskhandle, tud_taskhandle, mon_taskhandle;

// [HACKAGOTCHI] M1: SW-watchdog heartbeat (bumped each usb_thread loop) + a HIL hook that wedges the
// TUD task on demand so the watchdog can be proven to fire. Defined here (the TUD task's home).
volatile uint32_t g_tud_checkin = 0;
volatile bool     g_tud_wedge   = false;

static int was_configured;

void dev_mon(void *ptr)
{
    uint32_t sof[3];
    int i = 0;
    TickType_t wake;
    wake = xTaskGetTickCount();
    do {
        /* ~5 SOF events per tick */
        xTaskDelayUntil(&wake, 100);
        if (tud_connected() && !tud_suspended()) {
            sof[i++] = usb_hw->sof_rd & USB_SOF_RD_BITS;
            i = i % 3;
        } else {
            for (i = 0; i < 3; i++)
                sof[i] = 0;
        }
        if ((sof[0] | sof[1] | sof[2]) != 0) {
            if ((sof[0] == sof[1]) && (sof[1] == sof[2])) {
                probe_info("Watchdog timeout! Resetting USBD\n");
                /* uh oh, signal disconnect (implicitly resets the controller) */
                tud_deinit(0);
                /* Make sure the port got the message */
                xTaskDelayUntil(&wake, 1);
                tud_init(0);
            }
        }
    } while (1);
}

void usb_thread(void *ptr)
{
#ifdef PROBE_USB_CONNECTED_LED
    gpio_init(PROBE_USB_CONNECTED_LED);
    gpio_set_dir(PROBE_USB_CONNECTED_LED, GPIO_OUT);
#endif
    TickType_t wake;
    wake = xTaskGetTickCount();
    do {
        // [HACKAGOTCHI] M1: SW-watchdog HIL hook — when set, this task deliberately stops looping so
        // the watchdog can be proven to catch a wedged TUD task.
        if (g_tud_wedge)
            for (;;) tight_loop_contents();

        tud_task();
        // Heartbeat AFTER tud_task() so it proves tud_task() RETURNED this iteration (a hang inside
        // tud_task stops the heartbeat -> watchdog fires). NB: this proves the usb_thread LOOP +
        // tud_task() liveness, not USB-stack health — the upstream dev_mon task (SOF watchdog) covers
        // a logically-stalled-but-returning USB stack via tud_deinit/tud_init. The two are complementary.
        g_tud_checkin++;
#ifdef PROBE_USB_CONNECTED_LED
        if (!gpio_get(PROBE_USB_CONNECTED_LED) && tud_ready())
            gpio_put(PROBE_USB_CONNECTED_LED, 1);
        else
            gpio_put(PROBE_USB_CONNECTED_LED, 0);
#endif
        // If suspended or disconnected, delay for 1ms (20 ticks)
        if (tud_suspended() || !tud_connected())
            xTaskDelayUntil(&wake, 20);
        // Go to sleep for up to a tick if nothing to do
        else if (!tud_task_event_ready())
            xTaskDelayUntil(&wake, 1);
    } while (1);
}

// Workaround API change in 0.13
#if (TUSB_VERSION_MAJOR == 0) && (TUSB_VERSION_MINOR <= 12)
#define tud_vendor_flush(x) ((void)0)
#endif
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

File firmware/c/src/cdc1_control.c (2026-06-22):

/*
 * Hackagotchi — CDC1 JSON control channel. SPDX-License-Identifier: MIT
 *
 * CDC1 (instance 1) is a LINE-oriented request/response control port, separate from CDC0 (the target-
 * UART bridge in cdc_uart.c). Each request is one line of JSON — {"q":"<command>"} — and each reply is
 * one line of JSON. M1 replaces the Gate-2 strstr() prototype with a real jsmn parse over a bounded
 * line buffer, so a command is matched on the STRUCTURED value of the "q" key, not a substring:
 * {"note":"status please"} no longer false-triggers `status` the way the strstr prototype did.
 *
 * Commands: status, dump, lastfault, wd_arm, next, prev (request/response); crash, wd_test, bootsel
 * (no reply — the device faults/wedges/reboots and the host detects re-enumeration).
 *
 * Runs in the tud_task()/usb_thread (TUD task) context, so replies are same-task-safe and never touch
 * the DAP/SWD path.
 */

#include <string.h>
#include <stdio.h>
#include <stdlib.h>   // atoi (numeric jsmn values for beep/led test commands)
#include <stdbool.h>
#include <pico/stdlib.h>

#include "pico/bootrom.h"           // reset_usb_boot for {"q":"bootsel"}

#include "FreeRTOS.h"
#include "task.h"
#include "tusb.h"

#define JSMN_STATIC                 // keep jsmn symbols file-local (header-only, single TU)
#include "jsmn.h"
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

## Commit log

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2026-06-19 feat(xiao-uart): slim title bars + 5x7 compact font for denser screens
    Pack more onto the 128x64 OLED across all 10 pocket-debug screens:
    - Shared draw_header(): title at y=0 + divider rule at y=9 (was title y=2,
    rule y=11, content y=14), content now from y=11 -> ~one extra content row
    on every screen. Replaces the header idiom duplicated 10x.
    - Canonical 5x7 glcdfont (_F5x7 + text_small): 21 cols vs the built-in 8x8's
    16, used only on the data-dense screens -- Sniffer ASCII (6 lines), Hex
    (6 rows x 5 bytes + ASCII gutter, was 5x4), SD viewer (5 lines x 21 cols),
    and the probe sidebar (whose 8x8 "State:" ran off past x=128). Menus and
    titles keep the legible 8x8 built-in font.
    -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
    [main.py]
2026-06-19 feat(xiao-uart): autonomous black-box recorder (boot auto-start, RTC stamps, heartbeat)
    The bridge already had session-based SD logging; make it a true untethered black
    box for catching a standalone Pico wedge nobody is watching:
    - Boot auto-start via {"cfg":{"log_on_boot":true}} -- records from power-on with
    nobody to press START (default off, so it doesn't fill the card every boot).
    - One start_logging()/stop_logging() entry point (boot, Screen-9 menu, and the host
    cfg path all funnel through it) that writes a timestamped session header.
    - Wall-clock timestamps from the expansion board's PCF8563 RTC (I2C 0x51, CR1220
    backed); the VL flag or an absent RTC falls back gracefully to upt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
    [main.py]
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2026-06-19 feat(bridge): fault-tolerant main loop + visible logger faults
    The bridge is a black box for dev boards whose own debug channel dies
    under load, so the bridge itself must never silently brick. Previously
    any loop exception fell to a dead-end handler that printed once and spun
    forever (looks bricked, and stops bridging entirely). Now:
    - Per-iteration try/except: a transient fault (bad byte, SD hiccup, I2C
    glitch) is logged to the black box (RTC-stamped), flashes the error
    LED, beeps, and the bridge carries on watching the target.
    - Fault-storm escalation: 8 back-to-back faults => clean reboot with a
    visible 3-2-1 countdown (never a silent spin).
    - Optional hardware WDT, default OFF; {"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
    [main.py]
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2026-06-19 feat(pockettap): animated boot splash, transition library, FX helpers
    First pass of the visual overhaul (all within the non-blocking bridge loop;
    blocking animation only at boot, before the loop runs):
    - boot_splash() is now animated: the PocketTap wordmark wipes in behind a
    bright scan bar, the underline grows with the reveal, then the tagline and
    corner brackets settle in.
    - trigger_transition_wipe() became a 3-style transition that cycles per call
    (curtain-close, venetian blinds, vertical scan-wipe) -- every long-press
    screen change now gets a distinct, snappy (~6-frame) transition.
    - Added reusable FX primitives draw_sparkline() and draw_progress_bar() for
    the throughput meter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
    [main.py]
2026-06-19 feat(pockettap): flight-recorder apps -- wedge detector, trigger watch, throughput
    Adds the on-thesis differentiators (the black-box features), plus a live
    meter, as two new screens fed by always-on background monitors:
    - Watchdog (screen 10): the wedge detector flags the target going silent
    >8s after being alive (blinking global "!" badge + low alarm + stamped
    into the log), keeps a rolling 96-byte freeze-frame of its dying words,
    and a trigger watcher scans each RX line for armed substrings (default
    ERROR/FATAL/Traceback/panic/BUSY-TIMEOUT) -> chirp + flash + log mark +
    hit counter. Short-press acknowledges.
    - Throughput (screen 11): a live auto-scaled bytes/sec sparkline with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
    [main.py]
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2026-06-19 feat(case): add PocketTap "Field Recorder" pocket case
    A new minimal, distinctive enclosure for PocketTap (XIAO RP2040 + Expansion
    Board). Not a plain box — a soft pebble with functional gestures:
    - Canted top so the OLED tilts toward you on a desk (and gives the 9mm OLED
    module the clearance it needs on the tall end).
    - Rounded "probe snout" cable-boot on the XIAO end where the USB-C and the
    UART-tap leads (GP0/GP1/GND) exit together, with strain relief.
    - Lanyard eyelet at the tall OLED corner for pocket/keyring carry.
    - Flush thin-framed OLED visor, recessed button, buzzer grille; snap-fit
    seam, no visible screws.
    - Corner-post board cradle; `coupon` part for a fast seam/fit test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
    [pockettap_case.scad]
2026-06-19 docs(pockettap): warn against POLLOUT-gating the forward USB write
    Tried buffering UART->USB and flushing only when sys.stdout reports POLLOUT,
    to stop a stalled host from blocking the loop (and starving the reverse
    recovery channel). POLLOUT works, but registering sys.stdout in any poll() kills
    sys.stdin's POLLIN on this MicroPython (stdin/stdout are the same USB-CDC duplex
    stream) -> the bridge stops reading n/r/g/R/B. Verified by A/B deploy and
    reverted. Leave the plain blocking write (the host drains USB during recovery,
    so it never blocks in practice) and document the trap inline so it isn't redone.
    [main.py]
2026-06-19 feat(pockettap): host-side control over USB ({"screen":N}, {"q":"status"})
    The single button is a UX ceiling once the tool has 12 screens (the roadmap's
    top-flagged limitation). Cheapest fix: let a host app/script drive and monitor
    the bridge over the same USB-CDC it already uses for telemetry.
    - Broaden the host-command gate from `{"cfg":` to any `{...}` JSON line;
    process_host_command returns False for anything unrecognized, so genuine
    JSON destined for the target still falls through to the UART.
    - {"screen":N} (0..SCREEN_COUNT-1): jump the bridge to any screen, exit demo,
    reply {"status":"OK","screen":N}.
    - {"q":"status"}: reply a no-side-effect snapshot (screen/baud/tx/rx/logging/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
    [main.py]
2026-06-19 feat(pockettap): freeze-frame retrieval + stat reset over USB; stop cmd leak
    Round out the host interface so the black-box recorder can be read and reset
    programmatically (the recorder UX is the product's moat):
    - {"q":"freeze"}: dump the target's last ~96 bytes (its "dying words" before a
    wedge) as hex + printable ascii, with the wedge flag/stamp -- pull a wedge
    post-mortem over USB without the OLED or the microSD.
    - {"q":"status"}: now also reports wedge state + trigger hit count.
    - {"clear":true}: host-side stat reset (tx/rx/throughput/hits + freeze-frame),
    mirroring the on-device short-press, for scripted captures.
    Also fix a pre-existing wart the new commands exposed: host-comma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
    [main.py]
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2026-06-19 feat: e-ink "screenshot over the tap" -> PNG (remote panel visibility)
    Adds remote visibility into what the Pico's e-paper is showing, over the
    refresh-immune UART tap -- a recovery/observability tool and the verification
    path for visual work (e-ink animations / new pages) when no one can see the panel.
    - app.py: 'S' reverse-channel command dumps the InkyCanvas framebuffer (4736 B,
    296x128 MONO_VLSB) over the debug UART, framed SS>/SSD/SS<. Encoded in 240-byte
    chunks (multiple of 3 -> no interior base64 padding) via a memoryview, so the
    per-chunk alloc is ~320 B -- the whole-buffer encode OOMed on the fragmented
    low-RAM heap under .mpy shadows. Data goes straight to the UART (not th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
    [pockettap_ctl.py]
2026-06-19 fix: make the e-ink screenshot transfer robust (pacing + buffer + tolerance)
    The first live captures dropped chunks: the Pico bursts ~6 KB over UART faster
    than the busy XIAO bridge can relay it, overrunning the bridge's RX buffer.
    - app.py: pace the dump -- 192-byte chunks (multiple of 3 -> clean base64) with
    time.sleep_ms(25) between chunks, so each chunk is relayed before the next.
    - pockettap/main.py: enlarge the bridge UART rxbuf 1024 -> 8192 to hold the
    whole burst.
    - pockettap_ctl.py: tolerate an incomplete stream -- truncate to a clean base64
    boundary and render any missing bytes as gray, instead of crashing on a
    bad-length decode.
    Mechanism is proven live (SS> header + fra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
    [main.py, pockettap_ctl.py]
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2026-06-19 feat(firmware/c): scaffold the PocketDebugger fork (gates-first)
    No OLED/dashboard code yet -- gates first. Adds:
    setup.sh fetch debugprobe@v2.2.3 + submodules (+ --build-stock for Gate 0)
    boards/board_pockettap_config.h draft XIAO pin map; documents the full SWD<->SD-bus collision;
    SWCLK/SWDIO are a flagged candidate pending the solder decision
    README.md fork model, gate sequence, toolchain
    .gitignore ignore fetched upstream/ + build/ + gate-run evidence dirs
    [board_pockettap_config.h]
2026-06-19 test(gates): host-side harness for the 3 PocketDebugger gates
    Hardware-blind-safe scripts (exit 2 = can't run yet, 0 = pass, 1 = fail), ready
    to run the moment the SWD header is soldered:
    pin_toolchain.sh / usb_enum_snapshot.sh reproducibility + USB descriptor diff
    gate0_check.sh probe-rs + openocd flash/verify a target (exit-code based)
    gate1_soak.sh / gate1_soak_openocd.sh sustained flash soak, two-image verify, timeout-guarded
    heap_plot.py FreeRTOS heap-watermark leak/headroom check
    gate2_cdc.py dual-CDC enumeration + JSON round-trip + name->node mapping
    fixtures/build_fixtures.sh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
    [gate2_cdc.py, heap_plot.py]
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2026-06-19 feat(hackagotchi): build Gate-1 probe fork (debugprobe-v2.2.3 + OLED coexistence task)
    Forks raspberrypi/debugprobe @ debugprobe-v2.2.3 for the XIAO RP2040, adding the one
    low-priority OLED task whose coexistence with the SWD flash path Gate 1 must prove.
    - board_hackagotchi_config.h: SWD remapped to GP26(SWCLK)/GP27(SWDIO) — adjacent,
    SWDIO=SWCLK+1 as probe.pio's set_consecutive_pindirs requires; UART0 tap on GP0/1;
    PROBE_IO_RAW (no level shifter, the topology Gate 0 validated). Fixes the draft's bugs
    (missing PROBE_IO_RAW/PROBE_PIN_OFFSET; RESET wrongly on GP1=UART-RX).
    - Board injected WITHOUT editing the fetched upstream tree, via a boards/
    board_debug_probe_config.h shim: the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
    [board_hackagotchi_config.h, hackagotchi_dashboard.c, main.c]
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2026-06-19 fix(gate1): harden soak verification (probe-rs verify exits 0 on mismatch) + provenance + at-DAP adversarial
    Adversarial verification of the Gate-1 evidence (5-lens workflow) surfaced real holes; this closes the
    script/build ones:
    - gate1_soak.sh: `probe-rs verify` (0.31) prints "Verification failed: contents do not match" but EXITS 0
    on a real mismatch (confirmed live on this host) — so the old `if ! probe-rs verify` re-verify guard was
    a no-op. Now decide by STDOUT (grep "Verification successful"/"Verification failed"), never exit code.
    Also tee a PROVENANCE banner (probe-rs info on the remapped pins) into each log, since the CMSIS-DAP
    serial is the RP2040 flash unique-id and is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
    [main.c]
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2026-06-19 fix(gate1): set ssd1306 external_vcc=false (was uninitialized -> charge pump off -> dark OLED)
    The OLED coexistence task declared ssd1306_t on the stack and never set external_vcc — the one field
    ssd1306_init() reads but does not set. A garbage value sends 0x8D,0x10 (charge pump DISABLED) so the
    panel gets no boost voltage and stays dark (observed live; DAP was unaffected). The expansion OLED
    uses the internal charge pump, so external_vcc=false -> 0x8D,0x14 (pump ON). This fix is what made the
    OLED come alive for the Gate-1 soak; it was missed in the soak-hardening commit (30ac962).
    [hackagotchi_dashboard.c]
2026-06-19 feat(gate2): build 2nd-CDC firmware (DAP + UART-bridge + JSON control) — flash-ready, validation pending
    Adds CDC1 (JSON control channel) alongside CDC0 (target UART bridge) and the DAP vendor interface,
    as overlays compiled instead of the matching upstream files:
    - tusb_config.h: CFG_TUD_CDC 1 -> 2.
    - usb_descriptors.c: device class -> IAD composite 0xEF/0x02/0x01; bcdDevice 0223->0224; CDC1 on
    interfaces 3/4 with endpoints 0x86/0x07/0x88; strings "Hackagotchi UART"/"Hackagotchi Control";
    CAP_BREAK runtime index rewritten to CDC0 (the old relative form would patch CDC1).
    - cdc_uart.c (overlay): itf-guard line-coding/line-state/send-break callbacks to CDC0 — fixes a real
    2-CDC bug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
    [cdc1_control.c, cdc_uart.c]
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2026-06-20 test(gate1): close at-DAP-priority contention at rank-1 + firmware self-attestation
    The prior Gate-1 evidence (5200 idle-priority cycles) was a weak stressor (DAP
    preempts an idle-prio busy_wait in ~50us = a tautology) AND the running image was
    never machine-bound to the soak — a re-run 4-lens adversarial workflow (wf_96721d04)
    flagged exactly this as a SILENT-PASS risk (a stock-image soak would yield byte-
    identical evidence) and returned DO-NOT-PASS until bound. Closed on hardware return:
    - Self-attestation: dashboard_task now exposes g_dash_counter (frame counter n) +
    g_dash_stall_us (measured busy_wait); cdc1_control.c reports n/stall_cfg/stall_us/
    prio in the CDC1 status JSON (fw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
    [cdc1_control.c, gate1_liveness.py, hackagotchi_dashboard.c]
2026-06-20 feat(m1): crash box — post-mortem HardFault capture surviving reboot (HIL-verified)
    First M1 reliability-core increment. The probe runs probe-less (it IS the
    debugger), so a silent fault otherwise vanishes. The crash box snapshots a
    post-mortem the instant a fault fires, parks it in reset-surviving RAM, and the
    next boot surfaces it over CDC1 + the stdio log.
    - src/crash_box.{c,h}: isr_hardfault overrides the pico-sdk weak vector with a
    naked M0+ trampoline (selects PSP/MSP per EXC_RETURN), captures the 8-word
    exception frame into a .uninitialized_data (NOLOAD) record that survives a
    watchdog reboot — verified outside [__bss_start__,__bss_end__] in the
    copy_to_ram linker script;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
    [cdc1_control.c, crashbox_hil.py, main.c]
2026-06-20 feat(m1): SW watchdog + self-reflash bootsel command (HIL-verified)
    Second M1 reliability-core increment.
    - src/watchdog_task.{c,h}: a highest-priority health task that feeds the HW
    watchdog only while the high-priority TUD task keeps checking in (heartbeat
    g_tud_checkin). Monitoring TUD on purpose — NOT a low-prio task, which
    legitimately starves under flash load and would false-reset mid-flash. On a
    true wedge it records kind=watchdog/task=TUD into the crash box and reboots;
    the 8s HW WDT backstops the watchdog task itself dying. DISARMED by default
    (HW WDT not enabled until wd_arm) so a fresh flash cannot reboot-loop.
    - cdc1_control.c: {"q":"bootsel"} -> reset_usb_boot lets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
    [cdc1_control.c, main.c, watchdog_hil.py]
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2026-06-20 feat(m1): jsmn control parser replacing strstr (HIL-verified)
    Third M1 increment. CDC1 commands are now matched on the STRUCTURED value of
    the "q" key via a real JSON parse over a bounded line buffer, not a substring.
    - src/jsmn.h: vendored zserge/jsmn (MIT, header-only, JSMN_STATIC). Noted in
    THIRD-PARTY-NOTICES.md.
    - cdc1_control.c: bounded LINE_MAX line buffer reassembles requests split across
    USB packets; get_q() extracts "q" and dispatches by exact strcmp. Commands:
    status/dump/lastfault/wd_arm/next/prev (reply) + crash/wd_test/bootsel (reboot).
    Errors badjson/noq/unknown/toolong. lastfault clean state now valid JSON (null);
    status gains page; next/prev move a page-nav index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
    [cdc1_control.c, jsmn_hil.py, main.c]
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2026-06-20 test(m1): harden M1 evidence per adversarial audit (no deliverable gaps)
    An adversarial 3-lens audit (audit-m1-complete) returned M1-INCOMPLETE — not for
    missing deliverables (plan-completeness + code-consistency both said COMPLETE)
    but for real test-rigor and doc-staleness issues. Addressed:
    - watchdog_soak.py: strengthened from a near-tautological stressor. It loaded DAP,
    but the watchdog monitors TUD (which DAP cannot starve by the priority argument),
    and tolerated no-op flash failures. Now drives the MONITORED task: a background
    DAP flash thread AND a concurrent CDC0 loopback firehose hammering TUD, and
    rejects no-op runs (requires real flashes). Re-run: 120 flashes [0 failed]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
    [crashbox_hil.py, uart_bridge_hil.py, watchdog_soak.py]
2026-06-20 test(m1): close round-2 audit findings — measured margins + real silent-pass fixes
    Second adversarial audit pass returned M1-INCOMPLETE again — plan + code lenses
    COMPLETE (no missing deliverables), test-rigor INCOMPLETE with deeper findings,
    incl. one HIGH. All addressed:
    - ring_test.c (HIGH silent-pass): used assert() -> no-ops under -DNDEBUG and the
    PASS line would print with 0 checks. Replaced with a CHECK() macro (NDEBUG-
    independent), an honest pass/fail counter, a RING_SELFTEST_BREAK verify-the-
    verifier hook, AND a 4M-op concurrent producer/consumer fence stress (the
    release/acquire ordering was previously untested; exercised on weakly-ordered
    arm64). Confirmed: normal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
    [cdc1_control.c, crashbox_hil.py, jsmn_hil.py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]
2026-06-20 test(m1): close round-3 audit — fix the wd_gap stale-peak silent-pass (my own overcorrection)
    Round 3 caught that the wd_gap "measured margin" I added in round 2 was itself a
    stale boot-latched peak (always 500ms, never reset) — the EXACT silent-pass defect
    round 1 demoted urx_hw for. So gap1 < ceiling was constant-true regardless of load.
    A real silent-pass I introduced while fixing the previous one. Fixed properly:
    - watchdog_task: add wd_gap_reset() (zero the peak). cdc1: {"q":"wd_reset"} + expose
    the TUD heartbeat counter (g_tud_checkin) as `tud` in status.
    - watchdog_soak.py: reset the peak at start, then gate on THREE device-sourced
    signals — (i) TUD heartbeat advanced +1.65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
    [cdc1_control.c, crashbox_hil.py, watchdog_hil.py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]
2026-06-20 test(m1): close round-4 audit — stop manufacturing a tautological "load reached TUD" gate
    Round 4 caught that the tud_delta gate I added in round 3 (to fix round 2's gap)
    was ALSO tautological — the SAME class of error, twice. The TUD heartbeat
    (g_tud_checkin) free-runs at ~20kHz even idle (configTICK_RATE_HZ=20000), so
    tud_delta clears any threshold in <1s with zero load. So "positive proof the load
    reached TUD" proved only that the heartbeat is alive.
    Root realization: a soak CANNOT prove a stall margin here. TUD is high-priority
    and no normal load drives it near the 4000ms threshold — which is precisely WHY
    arm-by-default is safe (the priority argument: TUD+2 > DAP+1). So any "the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
    [watchdog_soak.py]
2026-06-20 test(m1): round-5 audit = M1-COMPLETE; reconcile the last doc<->code drifts
    Round 5 of the adversarial audit returned OVERALL M1-COMPLETE on all three lenses
    (plan + test-rigor + code-consistency) — no HIGH, 5 medium + 4 low, all evidence/
    consistency nits. Closed the material ones (the rest are disclosed):
    - DOC<->CODE DRIFT (the real one): M1_RESULTS prose said the tautological wd_gap
    "margin" gate was removed, but watchdog_soak.py still gated on wd_gap>=GAP_CEIL
    and the watchdog comments still called s_max_gap_ms a "MEASURED margin the soak
    asserts". Since wd_gap stays 0 under any soak-able load, that gate could never
    fail — decorative. Resolution: DEMOTE wd_gap to informatio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
    [crashbox_hil.py, jsmn_hil.py, watchdog_soak.py]
2026-06-20 feat(m2): SD bring-up gate — carlk3 FatFs mount/write/read-back (HIL-verified)
    First M2 increment: the foundational SD hardware proof. A real microSD on SPI0
    (SCK=GP2, MOSI=GP3, MISO=GP4, CS=GP28 — the pins the M1 SWD remap freed) mounts,
    write+read-back byte-identical, from a LOW-priority task off the DAP hot path.
    - setup.sh: fetch carlk3 no-OS-FatFS-SD-SDIO-SPI-RPi-Pico v3.6.2 (Apache-2.0, wraps
    ChaN FatFs R0.15) into gitignored upstream/ — same pattern as debugprobe.
    - CMakeLists: add_subdirectory the lib + link it; FILTER its src/crash.c out of
    INTERFACE_SOURCES (it ships its own isr_hardfault that collides with M1's
    crash_box.c). SDIO sources stay (sd_card.c hard-refs sd_s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
    [cdc1_control.c, hw_config.c, main.c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]
2026-06-20 chore(license): open-source under GPL-3.0
    The project had no LICENSE file (default "all rights reserved"); add an
    explicit license so the code can be distributed and contributed to.
    - Add GPL-3.0-or-later as the project license (LICENSE), matching the
    Pwnagotchi/Flipper/Meshtastic lineage and giving a copyleft leash vs
    closed clones of a clonable COTS board.
    - Add SPDX header + copyright to firmware/micropython/main.py (v1 firmware).
    - Keep firmware/c/ (the v2 debugprobe fork) under MIT (firmware/c/LICENSE) so
    fixes stay upstream-compatible per docs/upstream-strategy.md; its files
    already declared SPDX MIT.
    - Add root THIRD-PARTY-NOTICES.md (bundled drivers MIT; C deps MIT/BSD-3/Apa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
    [main.py]
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2026-06-20 feat(m3): M3.0 — feedback HAL (NeoPixel + buzzer) + published recorder snapshot
    M3.0 lays the M3 dashboard foundation, gates-first (design of record: the
    adversarially-critiqued m3-design workflow).
    feedback HAL (src/feedback.{c,h} + src/ws2812.pio): non-blocking user feedback
    serviced from the low-prio SD task, off the DAP hot path. Buzzer = GP29 PWM tone.
    Status LED = the XIAO onboard WS2812 NeoPixel (GP12 data + GP11 power) via PIO on
    pio1 (SWD owns pio0) so the 800 kHz waveform clocks in hardware and the CPU only
    pushes one word (never blocks/masks IRQs -> R1-safe). CDC1: {"q":"beep"},
    {"q":"led"}, {"q":"pixel"} (+ a get_int jsmn numeric extractor).
    Finding M3-1: the onboard RGB on GP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
    [cdc1_control.c, feedback.c, main.c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]
2026-06-20 feat(m3): M3.1 — multi-screen dashboard framework + self-attestation
    Evolve the Gate-1 single-frame OLED harness into the product dashboard: a screen
    table rendered at the lowest priority, snapshot-only reads, no physical button.
    Framework (src/hackagotchi_dashboard.{c,h}):
    - Screen fns produce a TEXT MODEL (title + <=5 lines); the framework BOTH draws it
    to the OLED AND publishes the identical text (seqlock) for CDC1 self-attestation,
    so the attestation is faithful by construction.
    - g_dash_shows: a SHOW-SUCCESS counter incremented only inside the lock-acquired
    ssd1306_show() branch, DISTINCT from the loop counter g_dash_counter, so a dark/
    skipped panel shows shows<loops and can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
    [cdc1_control.c, hackagotchi_dashboard.c, screen_hil.py]
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2026-06-20 feat(m3): M3.3 event feedback + M3 closeout audit fixes (M3 COMPLETE)
    M3.3 — buzzer + NeoPixel event feedback (src/sd_gate.c drive_feedback, run on the
    recorder-owning SD task, off the DAP hot path): edge-detected wedge->alarm,
    recovery->chirp, SD-fault->buzz, trigger-hit->blip, plus a boot chirp; a persistent
    NeoPixel status colour set on change (red=wedge/fault, dim-green=logging). HIL
    tests/m3/feedback_hil.py drives the real conditions over the UART loopback.
    M3 closeout — ran a 3-lens adversarial audit (workflow m3-closeout-audit):
    COMPLETE-WITH-NITS, no blockers; concurrency core verified sound, R1 intact. Fixed
    every silent-pass it found:
    - show-success counter was false (ssd1306_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
    [cdc1_control.c, coexist_soak.py, feedback.c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]
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

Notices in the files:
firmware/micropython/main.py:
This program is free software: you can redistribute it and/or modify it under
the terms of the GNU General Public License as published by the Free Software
